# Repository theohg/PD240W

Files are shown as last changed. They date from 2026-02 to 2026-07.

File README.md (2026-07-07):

# PD240W









An adjustable power supply for motor drives using USB-C Power Delivery negotiation, supporting up to **240W at 48V 5A**. This device is designed to be compatible with USB-PD up to 3.2. Firmware runs on a Raspberry Pi Pico ([RP2040](https://www.raspberrypi.com/products/rp2040/)).

Follow the latest project logs and updates on <a href="https://hackaday.io/project/205084-pd240w" target="_blank" title="PD240W on Hackaday.io">
Hackaday.io Hackaday.io
</a>

<p align="center">
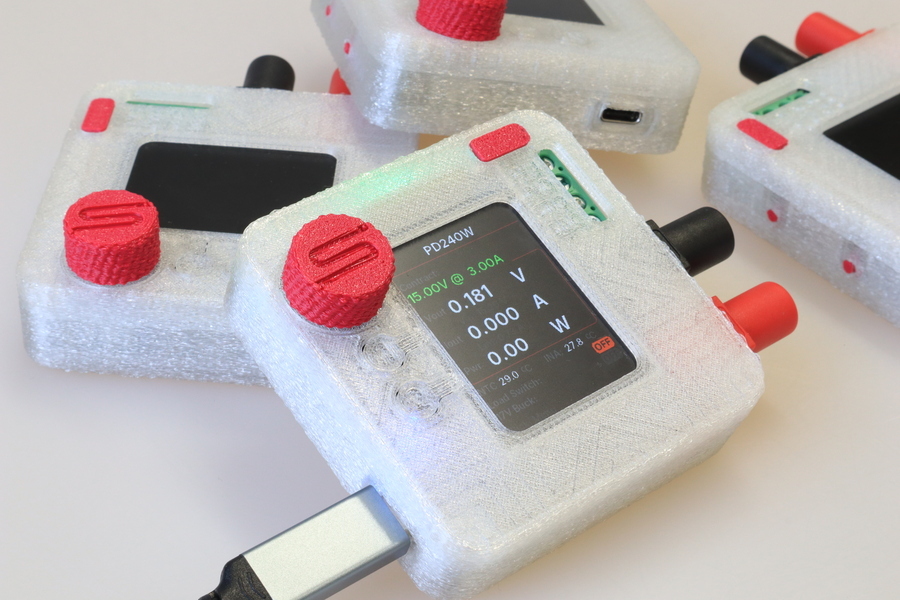
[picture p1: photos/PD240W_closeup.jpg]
PD240W closeup
  
</p>

> [!WARNING]
> **Disclaimer**: Firmware v2.0.0 includes guarded AVS/EPR negotiation, startup restore, and EPR-exit handling, but high-voltage charger interoperability still depends on the source and cable combination you test with. Validate 28V/36V/48V operation on your hardware.

## Table of Contents

- [Features](#features)
- [Hardware](#hardware)
- [Quick Start](#quick-start)
- [Controls](#controls)
- [Firmware Structure](#firmware-structure)
- [Want one?](#want-one)
- [Planned Features](#planned-features)
- [Acknowledgements](#acknowledgements)

## Features

- **USB-C Power Delivery**: Negotiates Fixed, PPS (3.3-21V programmable), and AVS (15-48V EPR) profiles
- **Current Limiting**: Adjustable 10mA-5A via INA228 power monitor with hardware overcurrent protection
- **LCD Interface**: 240x320 ST7789 display with anti-aliased fonts and Prusa-style encoder navigation
- **Safety**: Overcurrent ISR, overtemperature monitoring (NTC + INA228)
- **Settings Persistence**: User settings stored in RP2040 flash with CRC32 validation
- **Auto PPS/AVS Tuning**: Closed-loop voltage correction for PPS/AVS charger output accuracy
- **Charger Diagnostics**: On-device PD revision, charger identity, cable inference, and max-power reporting
- **Remote CLI**: USB serial command interface for measurements, PD selection, and settings updates
- **Energy Monitoring**: Tracks mAh delivered since boot via INA228 charge accumulator
- **17V Buck Output**: Optional mock STO/SBC voltage for motor drive safety circuits
- **Configurable**: Brightness, auto-dim, startup melody, auto-output on boot and more

## Hardware

<p align="center">
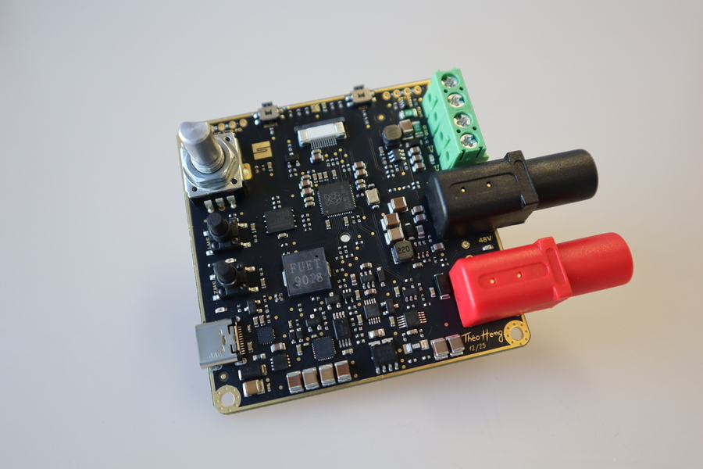
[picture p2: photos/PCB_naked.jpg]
PCB overview
  
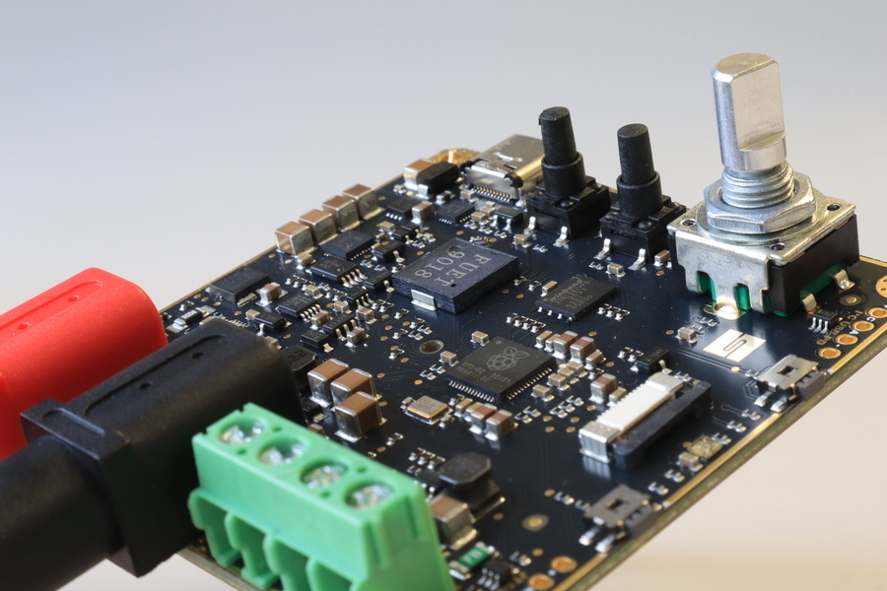
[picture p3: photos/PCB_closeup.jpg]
PCB closeup
  
</p>
<p align="center">
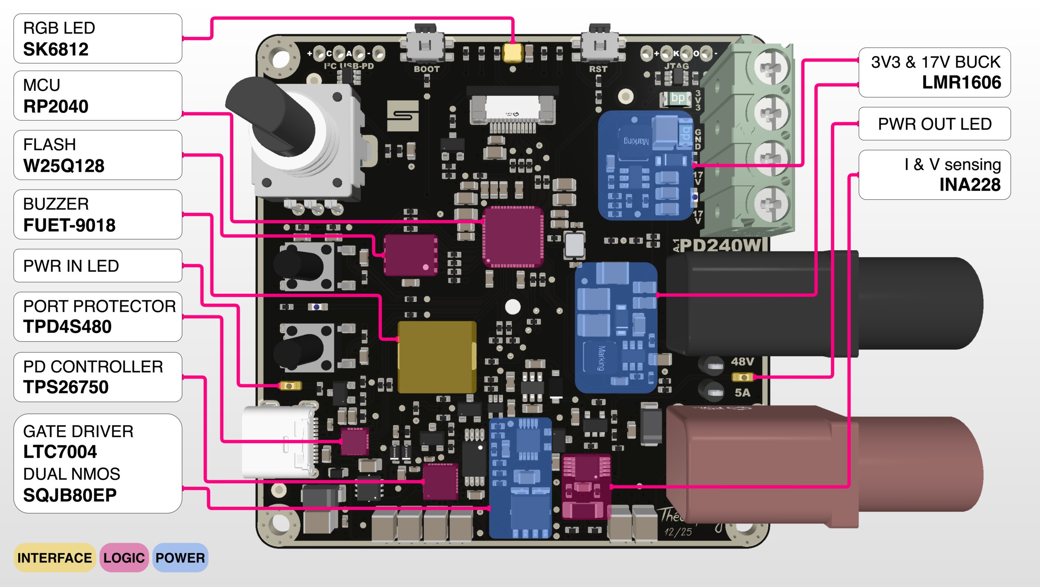
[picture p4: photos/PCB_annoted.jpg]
PCB annoted
  
</p>
<p align="center">
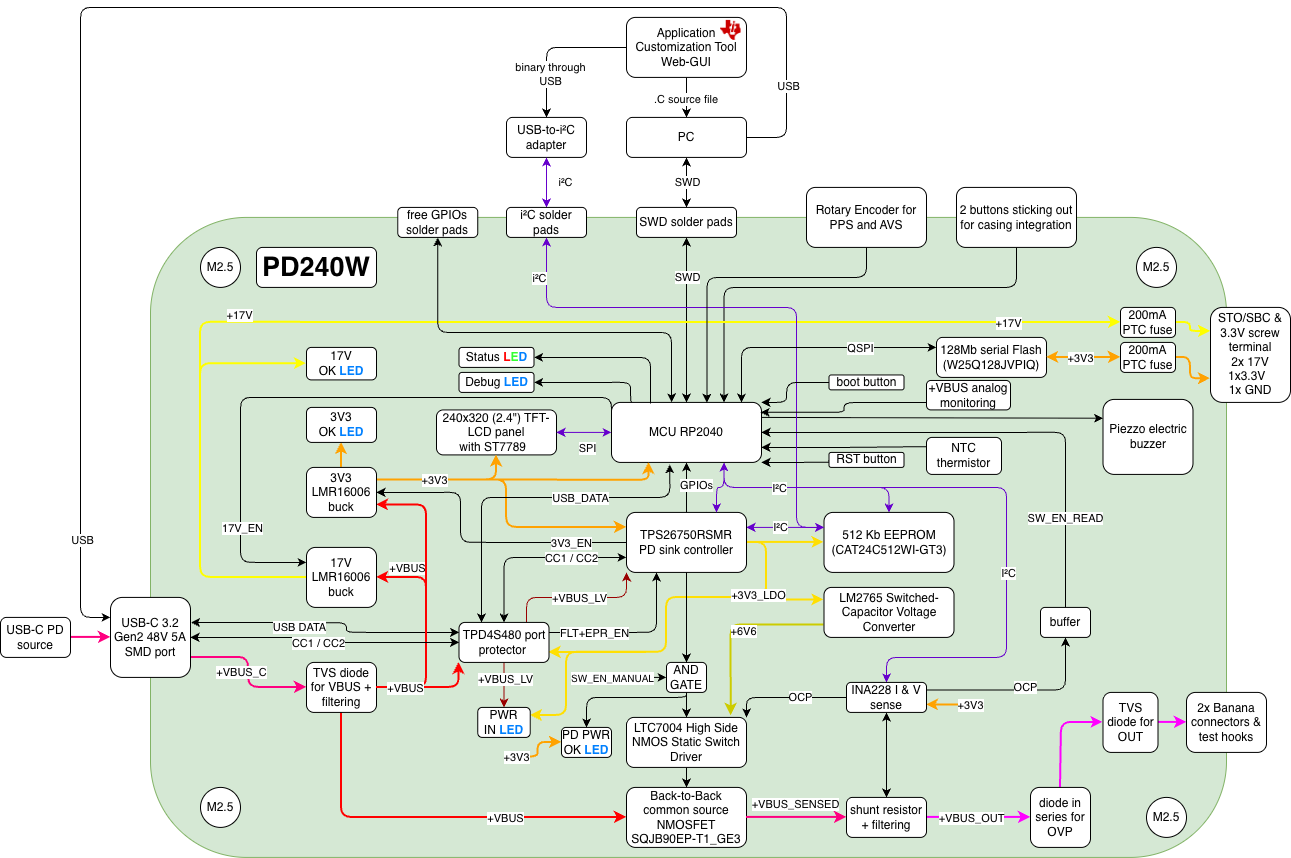
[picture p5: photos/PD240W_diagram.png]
PD240W diagram
  
</p>

| Type | Path | Contents |
|---|---|---|
| PCB (STEP) | `3D_models/PD240W_PCB.stp` | Full PCB 3D model |
| Enclosure (STL) | `3D_models/enclosure/` | Casing top/bottom, knob, button, LCD support, SWD cover |
| Gerbers | `PCB_files/Manufacturing/Fabrication/` | PCB manufacturing files |
| BOM | `PCB_files/Manufacturing/Assembly/` | Bill of materials |
| Pick & Place | `PCB_files/Manufacturing/Assembly/` | Pick and place file |

### Hardware Erata

USB data lines (D+/D-) are reversed in the current PCB revision, preventing native USB communication between the RP2040 and the USB host. This can be easily fixed by crossing the D+ and D- lines on the PCB by crossing the series 27Ω resistors as shown below:

<p align="center">
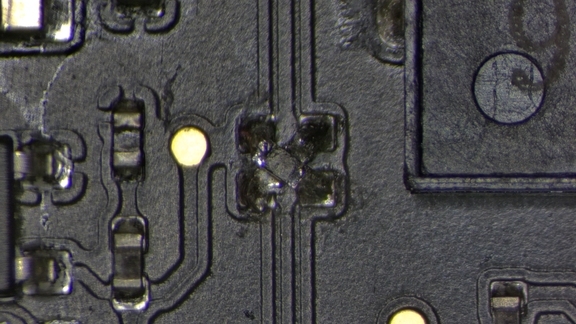
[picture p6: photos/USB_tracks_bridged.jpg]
PCB USB data lines bridged
  
</p>

## Quick Start

### Flash Pre-built Firmware

1. Download `PD240W.uf2` from the [latest release](https://github.com/theohg/PD240W/releases/latest)
2. Hold **BOOTSEL** button on the Pico while connecting USB
3. Drag `PD240W.uf2` to the mounted `RPI-RP2` drive

### Build from Source

Requires: [Pico SDK 2.3.0](https://github.com/raspberrypi/pico-sdk), ARM GCC toolchain, CMake, Ninja

```bash
git clone --recurse-submodules https://github.com/theohg/PD240W.git
cd PD240W

mkdir -p build && cd build
cmake -G Ninja ..
ninja
```

The output binary is `build/PD240W.uf2`.

The INA228 driver is tracked as a Git submodule in `external/ina228_multiplatform`. If you already cloned the repository without submodules, run:

```bash
git submodule update --init --recursive
```

PD240W does not automatically follow the newest INA228 library release. The version is pinned by the parent repository's recorded submodule commit for `external/ina228_multiplatform`, and that exact checked-out commit is what gets compiled into the firmware. Prebuilt `PD240W.uf2` releases already include that pinned INA version.

### Flash via SWD

```bash
openocd -f interface/cmsis-dap.cfg -f target/rp2040.cfg \
  -c "adapter speed 5000; program build/PD240W.elf verify reset exit"
```

> [!IMPORTANT]
> **EEPROM Initial Setup**: Before full PD negotiation can work, you must flash the **TPS26750 EEPROM** configuration. This is done via the **EEPROM Flash** workflow found in the **Settings** menu. 
> 
> **Note**: Before the EEPROM is flashed, the board will only power on when connected to a standard 5V non-PD charger (USB BC1.2 mode).

Once the firmware has been successfully flashed, connect the device to a compatible USB-PD power source and interact with the encoder and buttons to navigate the menus and adjust settings as explained below.

> [!NOTE]
> Finding a compact and affordable charger supporting **USB-PD 3.1** (up to 48V EPR) is currently quite rare. Here are a few known options:
>
> | Model | Max single-port PD Output | Voltage Profile | Approx. Price |
> |---|---|---|---|
> | **[UGREEN Nexode 140W](https://fr.ugreen.com/products/ugreen-nexode-140w-chargeur-usb-c-pd-3-1-3-ports)** | 140W | 28V @ 5A | ~60€ |
> | **[Framework Power Adapter - 180W](https://frame.work/fr/fr/products/16-power-adapter?v=FRANCR000F)** | 180W | 36V @ 5A | ~109€ |
> | **[HKY 240W GaN Charger](https://www.amazon.de/-/en/Charger-Framework-Thunderbolt-External-ADP-240KB/dp/B0FLXY1HYW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)** | 240W | 48V @ 5A | ~90€ |
> | **[Framework Power Adapter - 240W](https://frame.work/fr/fr/products/power-adapter-240w?v=FRAKMX000F)** | 240W | 48V @ 5A | ~120€ |
> | **[UGREEN NEXODE 500W](https://eu.ugreen.com/products/ugreen-nexode-500w-6-port-gan-desktop-fast-charger)** | 240W | 48V @ 5A | ~250€ |

## Controls

| Input | Action |
|---|---|
| Encoder Rotate | Navigate menus / Adjust values |
| Encoder Click | Confirm / Select |
| BTN1 (top) | Toggle load switch output |
| BTN2 (bottom) | Toggle 17V buck (requires VBUS > 18V) |

<p align="center">
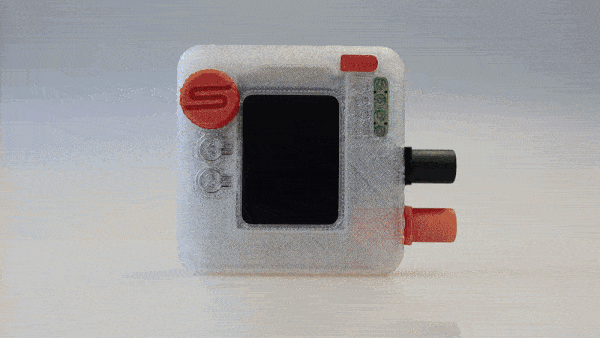
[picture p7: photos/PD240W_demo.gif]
PD240W usage demo
  
</p>

### Menu Structure

```mermaid
graph TD
  %% Nodes
      Boot([Boot]) -->|≤2s| Main[Main Screen]
      Main -->|Error| Fault[Fault Screen]
      Fault -->|Click| Main
      
      Main <-->|Click| Menu[Main Menu]

      Menu --> Voltage[Select Voltage]
      Menu --> Current[Current Limit]
      Menu --> Settings[Settings]
      Menu --> AboutFirmware[About PD240W]
      Menu --> AboutCharger[About This Charger]
      Menu --> Back[Back]

      Voltage <-->|Select PDO| AdjV[Adjust Voltage]
      Current <-->|Set Limit| AdjC[Adjust Current]
      
      Settings --> EEPROM[Flash EEPROM]
      Settings --> Configs[Params: Brightness / Sounds / Tuning...]
      AboutFirmware --> Main
      AboutCharger --> Main
      
      %% Styling
      classDef default fill:#f9f9f9,stroke:#333,stroke-width:1px;
      classDef alert fill:#ffcccc,stroke:#cc0000,stroke-width:2px;
      class Fault alert;
```

| Menu Item | Description |
|---|---|
| Select Voltage | Fixed / PPS / AVS PDO selection |
| Current Limit | 10mA - 5A output current limit adjustment with encoder acceleration |
| Settings | EEPROM flash workflow plus tuning, startup, brightness, and sound options |
| About PD240W | Device identity, firmware build info, flash usage, and project link |
| About This Charger | Live PD revision, CC orientation, QC inference, and cable diagnostics |
| Back | Return to the main live display |

## Firmware Structure

```
src/
├── main.cpp                        Entry point, non-blocking main event loop
├── hardware.h/cpp                  Hardware singleton aggregating all drivers
├── interrupts.h/cpp                Centralized GPIO interrupt router (RP2040 single-callback)
│
├── config/
│   ├── board_config.h              Pin definitions (Board:: namespace)
│   ├── app_config.h                Timeouts, thresholds, limits (AppConfig:: namespace)
│   └── version.h                   Firmware & hardware version, author...
│
├── drivers/                        Low-level hardware drivers (no business logic)
│   ├── display/
│   │   ├── st7789.h/cpp            SPI LCD driver with AA font rendering
│   │   ├── aa_font.h               Anti-aliased font data structure
│   │   └── font_inter_*.h          Generated Inter font bitmaps (14/20/28px)
│   ├── power/
│   │   └── tps26750/               USB-PD controller: PDO discovery, contract negotiation
│   ├── input/
│   │   ├── rotary_enc.h/cpp        Quadrature encoder with velocity tracking
│   │   ├── button.h/cpp            Debounced button with click/long-press
│   │   └── adc_inputs.h/cpp        VBUS voltage + NTC temperature (ADC channels)
│   ├── gpio/                       SimpleIO: digital output with non-blocking blink
│   ├── buzzer/                     PWM buzzer with melody playback
│   └── rgb_led/                    SK6812 via PIO state machine
│
├── logic/                          Application logic
│   ├── state_machine.h/cpp         BOOT -> MAIN <-> MENU <-> ADJUST, FAULT handling
│   ├── safety.h/cpp                Temperature/voltage/current monitoring, fault triggers
│   ├── pd_manager.h/cpp            PD contract caching, PPS keep-alive, auto-tuning
│   ├── settings.h/cpp              Flash persistence with CRC32, debounced saves
│   └── tps_eeprom_workflow.h/cpp   TPS26750 EEPROM compare/flash state machine
│
├── ui/
│   ├── display_manager.h/cpp       All screen rendering (boot, main, menu, adjust, fault)
│   ├── font_config.h               Central font size mapping (FONT_LARGE/MEDIUM/SMALL)
│   └── assets/synapticon_logo.h    Boot screen logo bitmap
│
├── utils/
│   ├── logging.h                   LOG_INFO/WARN/ERROR/DEBUG/CRITICAL macros
│   ├── pd_voltage.h                Shared programmable-voltage alignment helper
│   ├── tps_eeprom_loader.h/cpp     Low-level TPS26750 EEPROM read/write
│   └── tps26750_patch.c            TPS26750 binary configuration blob
```

## Want one?

<p align="center">
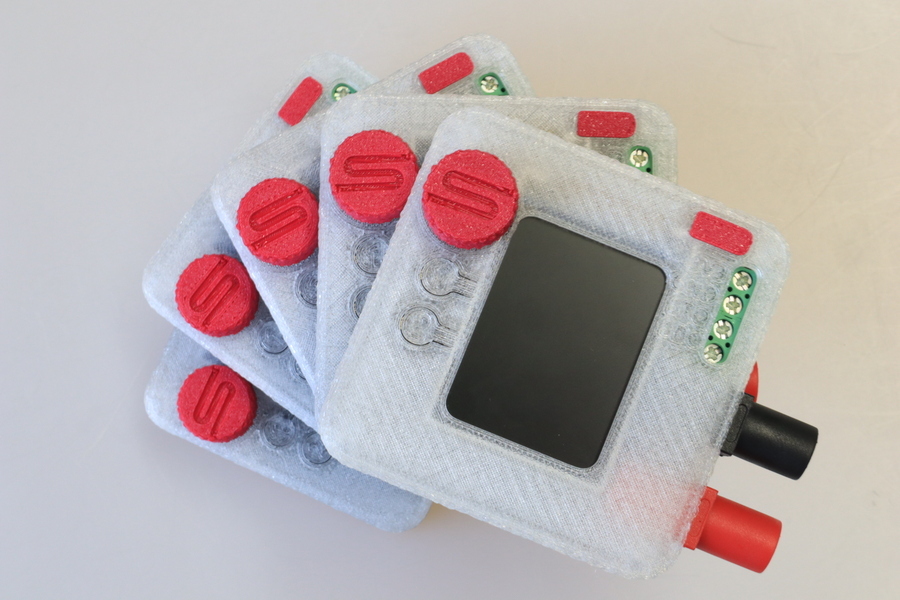
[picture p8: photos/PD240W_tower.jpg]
PD240W units
  
</p>

Feel free to order assembled PCBs, flash the firmware, and test it for yourself! Manufacturing 5 assembled PCBs will cost approximately **$415**. 

The project is open for contributions. Don't hesitate to improve the code, report bugs, or suggest new features via Pull Requests and Issues!

## License and Copyright

This repository contains different types of source files, which are licensed as follows:

### 1. Hardware files (CC BY-NC 4.0)
All hardware design files in the PCB_files directory (Schematics, PCB layout, Gerbers, BOM) and 3D printable enclosure files are licensed under the **Creative Commons Attribution-NonCommercial 4.0 International License**. 

You are free to download, modify, and build this board for personal, educational, and hobbyist use. However, you may **not** use these designs for commercial purposes (such as manufacturing and selling the boards) without prior written permission.

Please see the [LICENSE.txt](./LICENSE.txt) file for full terms.

### 2. Firmware & Software (MIT License)
The firmware and software source code in this repository is licensed under the **MIT License**. 

You are free to use, modify, and distribute the software component of this project. 

Please see the [LICENSE-FIRMWARE.txt](./LICENSE-FIRMWARE.txt) file for full terms.

## Planned Features for V2.1.0+

- **PPS battery charging in Constant Current (CC) mode**: PPS allows a fixed current mode that can be used for battery charging. This is to be tested by charging lithium-ion battery packs.
- **Improved CLI interface**: Needs more testing and polish.
- **Extended PPS and AVS Range**: Support for PPS voltages as low as 3.5V, AND SPR AVS profiles down to 9V.

## Acknowledgements

This project was made possible by [Synapticon GmbH](https://www.synapticon.com), who funded and supported its development. Thank you for providing the resources, hardware, and opportunity to bring PD240W to life.

Inspiration for this project was taken from the great work on portable USB-C PD power supplies by CentyLab on the [PocketPD](https://hackaday.io/project/194295-pocketpd-usb-c-portable-bench-power-supply) project and Alex Xia with his [ProtoV MINI](https://hackaday.io/project/204461-protov-mini-tiny-usb-c-breadboard-power-supply).

All work done on this project, from Hardware design to Firmware development, was done by me, as the sole contributor. I am grateful for the support and feedback from the community, and I hope this project can be a useful resource for anyone interested in USB-C PD power supplies!

***

<p align="center">
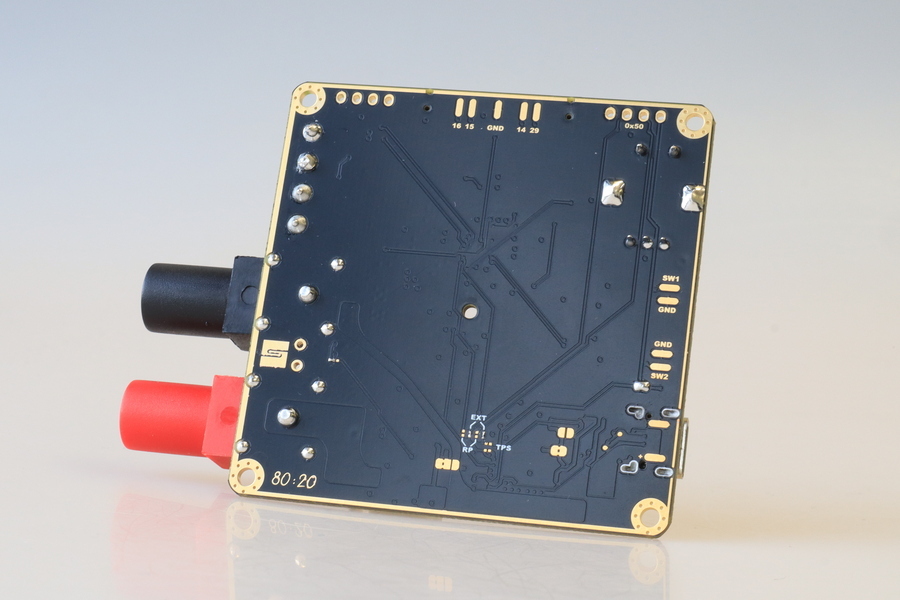
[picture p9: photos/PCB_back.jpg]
PCB back
  
</p>

Made with ❤️ by Théo Heng

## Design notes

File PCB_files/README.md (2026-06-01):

<p align="center" width="100%">
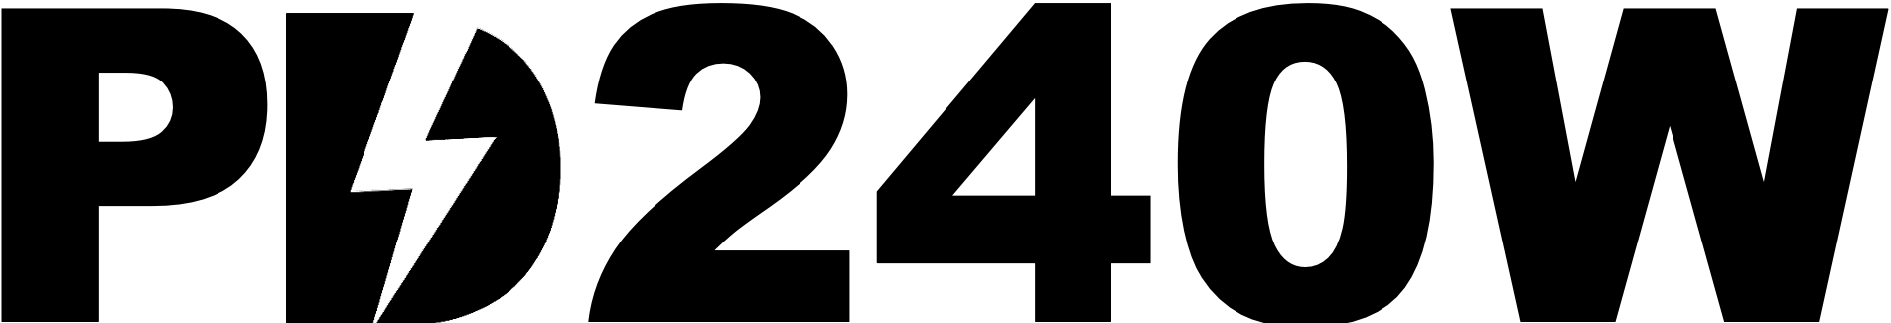
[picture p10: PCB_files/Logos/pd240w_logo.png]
  
</p>

<h1 align="center">PD240W</h1>

<p align="center" width="100%">
    
</p>

***

<p align="center">
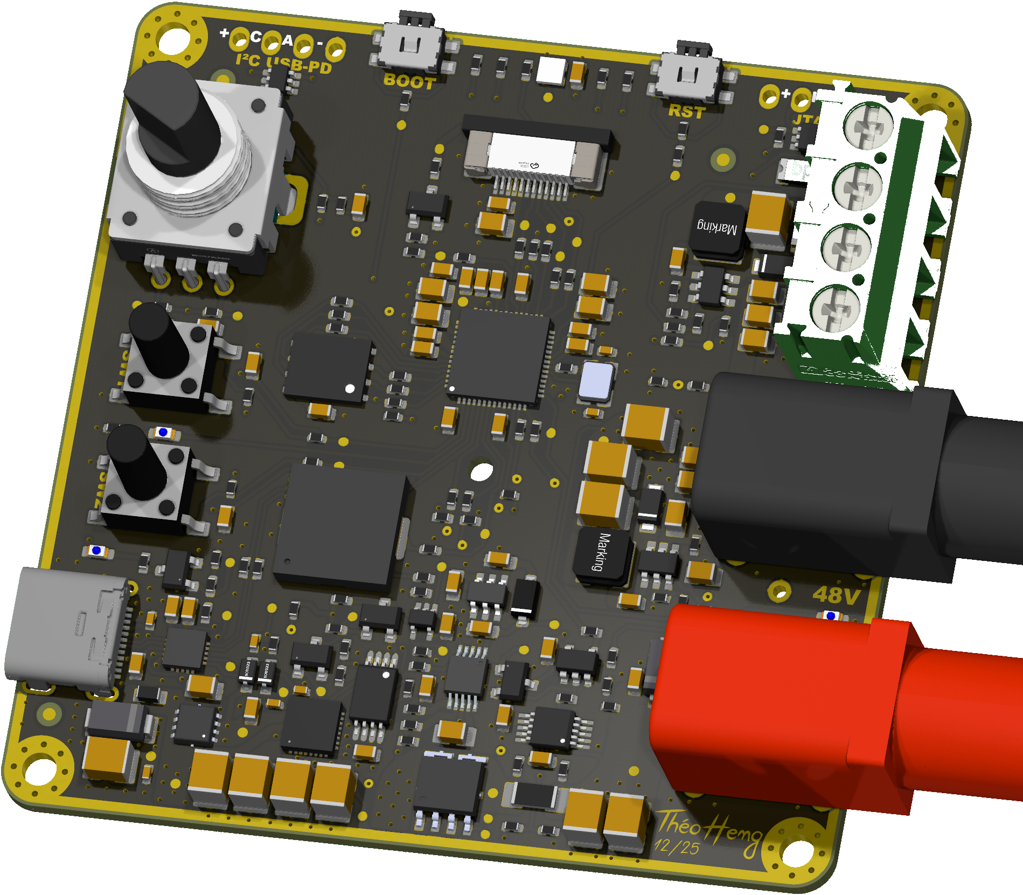
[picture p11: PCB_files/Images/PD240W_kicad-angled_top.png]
3D Top Angled
  
&nbsp; &nbsp; &nbsp; &nbsp;
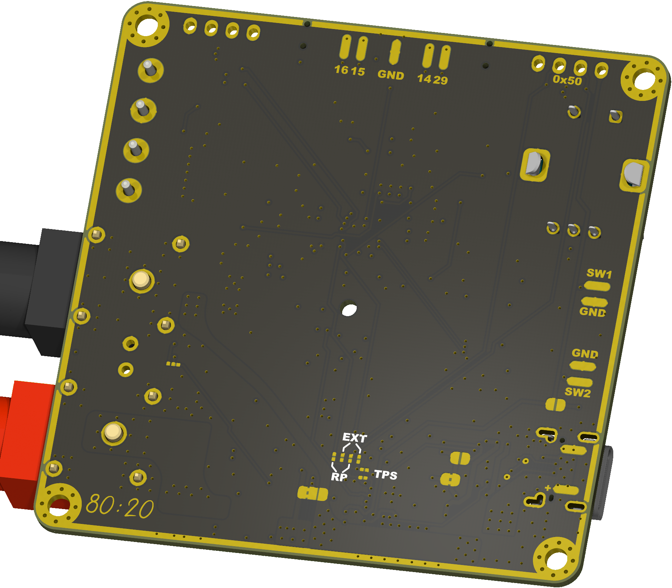
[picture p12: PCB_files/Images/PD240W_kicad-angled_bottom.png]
3D Bottom Angled
  
</p>

***

## SPECIFICATIONS

| Parameter | Value | 
| --- | --- |
| Dimensions | 66.0 × 66.0 mm |
| Input Voltage | 5 - 53 V |
| Output Voltage | 3.3 - 48 V |
| Max. Output Current Voltage | 5 A |
| Max Power Output | 240 W |

***

## DIRECTORY STRUCTURE
```
  ├─ Images             # Pictures, renders, and annotated PCB images
  ├─ lib                # KiCad footprint and symbol libraries
  │  ├─ lib_fp          # Footprint libraries
  │  └─ lib_sym         # Symbol libraries
  ├─ Logos              # Project logos used in the PCB design package
  ├─ Manufacturing      # Assembly and fabrication deliverables
  │  ├─ Assembly        # BoM, placement, and assembly notes
  │  └─ Fabrication     # Fabrication exports and release bundles
  ├─ Schematic          # Exported schematic documentation
  └─ Templates          # KiCad title block templates
```

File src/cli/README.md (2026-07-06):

# PD240W Serial CLI Reference

## Connection

The PD240W exposes a serial CLI over USB CDC at **115200 baud, 8N1**. Lines are terminated with `\n`.

> [!NOTE]
> On the current PCB revision, native USB CDC requires the USB D+/D- rework described in the repository [README](../../README.md).

**Finding the serial port:**

| OS | Command |
|----|---|
| macOS | `ls /dev/tty.usbmodem*` |
| Linux | `ls /dev/ttyACM*` |
| Windows | Device Manager → Ports (COM & LPT) |

Connect with any serial terminal:
```bash
# macOS / Linux
screen /dev/tty.usbmodem1234 115200
# or
minicom -D /dev/ttyACM0 -b 115200
```

## Protocol Rules

- **Queries** end with `?` and return the value on a single line: `20000\n`
- **Set commands** include a value after a space and return `OK\n` on success
- **Action commands** (no argument) return `OK\n`
- **Errors** return `ERR <CODE>\n` immediately

### Error Codes

| Code | Description |
|---|---|
| `UNKNOWN_CMD` | Command not found in dispatch table |
| `INVALID_PARAM` | Argument is missing, malformed, or wrong type (e.g. non-numeric, not ON/OFF) |
| `INVALID_INDEX` | PDO index out of range |
| `OUT_OF_RANGE` | Numeric value outside allowed bounds |
| `NOT_AVAILABLE` | Operation not possible (e.g. PPS command with no PPS contract, buck with low VBUS) |
| `FAULT_ACTIVE` | Output command rejected because a safety fault is active |
| `NO_POWER_MONITOR` | Load switch refused: INA228 power monitor did not initialize (no current sensing / overcurrent protection) |

### Log Output

Firmware log lines use prefixes: `[INFO]`, `[WARN]`, `[ERROR]`, `[DEBUG]`. These are separate from CLI responses and can be suppressed:

- `LOG:OFF` — Suppress all log output (recommended for scripting)
- `LOG:ON` — Re-enable log output

### Remote Control Mode

Receiving any serial command puts the device in **REMOTE** mode:
- Front panel is locked (encoder/buttons disabled)
- LCD shows a red **RMT** badge
- Long-press encoder returns to local control
- `SYST:LOC` command also exits remote mode

## Command Reference

### Identity & Status

| Command | Arguments | Response | Description |
|---|---|---|---|
| `*IDN?` | — | `PD240W,HWA.1,FWv2.0.0` | Device identification |
| `SYST:STAT?` | — | `MAIN` / `FAULT:OVERTEMP` / ... | System state |
| `SYST:UPTIME?` | — | `12345` | Uptime in seconds |
| `SYST:REBOOT` | — | `OK` | Software reboot (watchdog reset) |
| `SYST:BOOTSEL` | — | `OK` | Reboot into BOOTSEL (UF2 flash mode) |
| `SYST:LOC` | — | `OK` | Exit remote mode, return to local control |

### Output Control

| Command | Arguments | Response | Description |
|---|---|---|---|
| `OUTP:SW?` | — | `ON` / `OFF` | Query load switch state |
| `OUTP:SW` | `ON` / `OFF` | `OK` | Enable/disable load switch |
| `OUTP:BUCK?` | — | `ON` / `OFF` | Query 17V buck state |
| `OUTP:BUCK` | `ON` / `OFF` | `OK` | Enable/disable 17V buck (requires VBUS > 18V) |

### Measurements (read-only)

| Command | Arguments | Response | Description |
|---|---|---|---|
| `MEAS:VOLT?` | — | `20000` | Output voltage in mV (from INA228) |
| `MEAS:CURR?` | — | `1500` | Output current in mA |
| `MEAS:POW?` | — | `30000` | Output power in mW |
| `MEAS:TEMP?` | — | `452` | Board temperature in °C × 10 (45.2°C) |
| `MEAS:ITEMP?` | — | `380` | INA228 die temperature in °C × 10 |
| `MEAS:ENERGY?` | — | `1234` | Accumulated energy since boot in mWh |
| `MEAS:CHARGE?` | — | `1234` | Accumulated charge since boot in mAh |
| `MEAS:VBUS?` | — | `20100` | Pre-switch VBUS voltage in mV (from ADC) |
| `MEAS:ALL?` | — | `20000,1500,30000,452,380,1234` | volt_mv, curr_ma, pow_mw, temp_c×10, itemp_c×10, energy_mwh |

### PD Contract Management

| Command | Arguments | Response | Description |
|---|---|---|---|
| `PD:LIST?` | — | `0:5000/3000,1:9000/3000,...` | List available PDOs (index:mV/mA or PPS/AVS format) |
| `PD:ACTIVE?` | — | `20000,3000,FIXED` | Active contract: voltage, current, type |
| `PD:REV?` | — | `PD3.2` | PD revision string (`PD2.0` / `PD3.0` / `PD3.1` / `PD3.2`) |
| `PD:SEL` | `<index>` | `OK` | Select PDO by index (from PD:LIST?) |
| `PD:PPS` | `<voltage_mv>` | `OK` | Set PPS voltage in mV (must be in active PPS range) |
| `PD:AVS` | `<voltage_mv>` | `OK` | Set AVS voltage in mV (must be in active AVS range) |

### Current Limit

| Command | Arguments | Response | Description |
|---|---|---|---|
| `CURR:LIM?` | — | `1500` | Query current limit in mA |
| `CURR:LIM` | `<10-5000>` | `OK` | Set current limit in mA (10 mA steps) |

### Settings

| Command | Arguments | Response | Description |
|---|---|---|---|
| `SETT:BRIGHT?` | — | `80` | Query LCD brightness (5–100) |
| `SETT:BRIGHT` | `<5-100>` | `OK` | Set LCD brightness |
| `SETT:SOUND?` | — | `ON` / `OFF` | Query sounds enabled |
| `SETT:SOUND` | `ON` / `OFF` | `OK` | Toggle sounds |
| `SETT:AUTOPPS?` | — | `ON` / `OFF` | Query auto PPS tuning |
| `SETT:AUTOPPS` | `ON` / `OFF` | `OK` | Toggle auto PPS tuning |
| `SETT:AUTOAVS?` | — | `ON` / `OFF` | Query auto AVS tuning |
| `SETT:AUTOAVS` | `ON` / `OFF` | `OK` | Toggle auto AVS tuning |
| `SETT:AUTOOUT?` | — | `ON` / `OFF` | Query auto output |
| `SETT:AUTOOUT` | `ON` / `OFF` | `OK` | Toggle auto output |
| `SETT:DIM?` | — | `5` | Query dim timeout in minutes |
| `SETT:DIM` | `<0-10>` | `OK` | Set dim timeout in minutes (`0` = OFF) |
| `SETT:SAVE` | — | `OK` | Force save settings to flash |
| `SETT:RESET` | — | `OK` | Reset all settings to defaults |

### Log Control

| Command | Arguments | Response | Description |
|---|---|---|---|
| `LOG:ON` | — | `OK` | Enable firmware log output |
| `LOG:OFF` | — | `OK` | Suppress firmware log output |

### System

| Command | Arguments | Response | Description |
|---|---|---|---|
| `SYST:REBOOT` | — | `OK` | Software reboot via watchdog |
| `SYST:BOOTSEL` | — | `OK` | Reboot into UF2 flash mode |
| `SYST:LOC` | — | `OK` | Return to local (front panel) control |

## Raw Session Example

```
> *IDN?
PD240W,HWA.1,FWv2.0.0
> LOG:OFF
OK
> SYST:STAT?
MAIN
> PD:LIST?
0:5000/3000,1:9000/3000,2:15000/3000,3:20000/3000,4:PPS/3300-21000/5000
> PD:ACTIVE?
20000,3000,FIXED
> PD:REV?
PD3.0
> PD:SEL 4
OK
> PD:PPS 9500
OK
> MEAS:ALL?
9480,0,0,312,298,0
> CURR:LIM 2000
OK
> CURR:LIM?
2000
> OUTP:SW ON
OK
> MEAS:VOLT?
9500
> MEAS:CURR?
850
> MEAS:POW?
8075
> SETT:BRIGHT 70
OK
> OUTP:SW OFF
OK
```

## Python Quick Start

```python
from pd240w import PD240W

with PD240W("/dev/ttyACM0") as psu:
    print(psu.identity())           # PD240W,HWA.1,FWv2.0.0
    print(psu.list_pdos())          # ['0:5000/3000', '1:9000/3000', ...]
    psu.select_pdo(3)               # Select 20V
    psu.output(True)                # Enable output
    m = psu.measurements()
    print(f"{m['voltage_mv']/1000:.2f}V  {m['current_ma']/1000:.3f}A")
    psu.output(False)               # Disable output
```

See [tools/pd240w.py](../../tools/pd240w.py) for the full library and CLI tool.

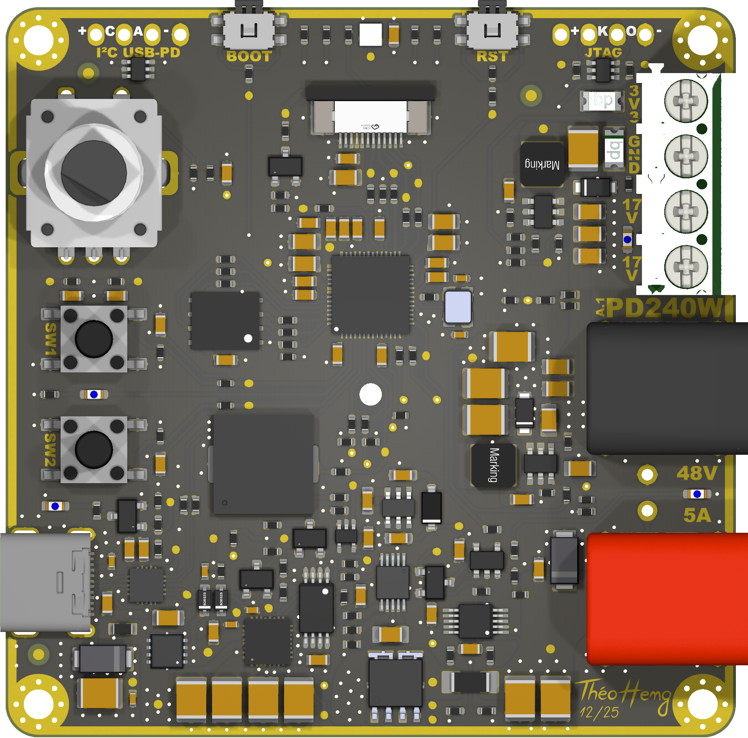
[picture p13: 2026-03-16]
PCB_files/Images/PD240W_kicad-top.png

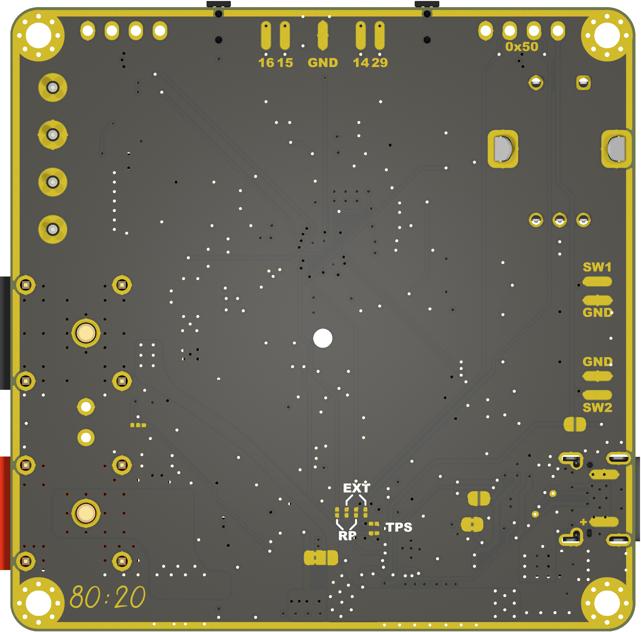
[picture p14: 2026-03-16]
PCB_files/Images/PD240W_kicad-bottom.png

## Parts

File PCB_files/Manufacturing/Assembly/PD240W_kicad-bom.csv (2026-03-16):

Row | Quantity Per PCB | References | Value | Datasheet | Footprint | Description | Manufacturer | Manufacturer Part Number | LCSC
1 | 2 | C45 C46 | 15p COG 50V | https://jlcpcb.com/api/file/downloadByFileSystemAccessId/8579707286171729920 | capc_1005_06_n | Capacitor, 15pF, 5%, C0G, 50V, 1005, 0402 | FH (Guangdong Fenghua Advanced Tech) | 0402CG150J500NT | C1548
2 | 2 | C19 C20 | 220p X7R 50V | https://jlcpcb.com/api/file/downloadByFileSystemAccessId/8588946226129604609 | capc_1005_06_l | Capacitor, 220pF, 10%, X7R, 50V, 1005, 0402 | Samsung Electro-Mechanics | CL05B221KB5NNNC | C296710
3 | 3 | C1 C2 C5 | 10n X7R 100V | https://jlcpcb.com/api/file/downloadByFileSystemAccessId/8588949628376502272 | capc_1005_06_n | Capacitor, 10nF, 10%, X7R, 100V, 1005, 0402 | Yageo | CC0402KRX7R0BB103 | C527014
4 | 32 | C4 C6 C8 C16 C17 C21 C22 C23 C24 C25 C26 C27 C30 C34 C35 C37 C38 C39 C40 C41 C42 C43 C44 C47 C48 C49 C50 C52 C53 C54 C55 C63 | 100n X7R 100V | https://jlcpcb.com/api/file/downloadByFileSystemAccessId/8586178586332446721 | capc_1608_09_l | Capacitor, 100nF, 10%, X7R, 100V, 1608, 0603 | Samsung Electro-Mechanics | CL10B104KC8NNNC | C15725
5 | 13 | C7 C31 C32 C33 C36 C51 C56 C57 C58 C62 C64 C65 C66 | 1u X7R 100V | https://jlcpcb.com/api/file/downloadByFileSystemAccessId/8590904853830971392 | capc_2012_14_n | Capacitor, 1uF, 10%, X7R, 100V, 2012, 0805 | Yageo | CC0805KKX7R0BB105 | C5370002
6 | 1 | C18 | 2.2u X7R 100V | https://jlcpcb.com/api/file/downloadByFileSystemAccessId/8590916664114966528 | capc_2012_14_m | Capacitor, 2.2nF, 10%, X7R, 100V, 2012, 0805 | Chinocera | HHV0805R7225K101NSLJ | C22367838
7 | 3 | C13 C14 C15 | 3.3u X5R 25V | https://jlcpcb.com/api/file/downloadByFileSystemAccessId/8590902687791857664 | capc_1608_09_n | Capacitor, 3.3uF, 20%, X5R, 25V, 1608, 0603 | CCTC | TCC0603X5R335M250CT | C5360803
8 | 1 | C3 | 4.7u | https://jlcpcb.com/api/file/downloadByFileSystemAccessId/8588955064752869376 | capc_3225_22_n | Capacitor, 4.7 uF, 10%, X7S, 100V, 3225, 1210 | Murata Electronics | GCM32DC72A475KE02 | C913445
9 | 10 | C9 C10 C11 C12 C28 C29 C59 C60 C61 C67 | 10u X7R 63V | https://jlcpcb.com/api/file/downloadByFileSystemAccessId/8589835732941770752 | capc_3225_27_n | Capacitor, 10uF, 10%, X7R, 63V, 3225, 1210 | Murata Electronics | GRM32ER71J106KA12L | C437568
10 | 4 | D4 D6 D9 D14 | APTD1608LQBC/D | https://jlcpcb.com/api/file/downloadByFileSystemAccessId/8589837755585884160 | kingbright_0603_blue | Standard LEDs - SMD Chip LED, Package= 0603, Color = Blue | Kingbright | APTD1608LQBC/D | C5344742
11 | 1 | D5 | B0520LW-7-F | https://jlcpcb.com/api/file/downloadByFileSystemAccessId/8560080535511982080 | sod-123_270x155135_n | Schottky Diodes & Rectifiers 20V 410mW, SMD, SOD123 | Diodes Incorporated | B0520LW-7-F | C155367
12 | 2 | D2 D3 | BZT52C18SQ | https://jlcpcb.com/api/file/downloadByFileSystemAccessId/8590197770775654400 | sod-323_230p_170x125x100_n | Zener Diode 18V 200mW 5% Surface Mount SOD-323 | JSMSEMI | BZT52C18SQ | C2857090
13 | 2 | D7 D10 | D3V3F4U6S-7 | https://jlcpcb.com/api/file/downloadByFileSystemAccessId/8589951277003141120 | sot363_sc88_65p_200x125x110_n | 4-Ch 3.3V Low Cap TVS Array 0.85pF 3.5A 350mW | Diodes Incorporated | D3V3F4U6S-7 | C1869321
14 | 2 | D12 D13 | MBR1H100SFT3G | https://jlcpcb.com/api/file/downloadByFileSystemAccessId/8588886768716288000 | sod-123fl_305p_260x160x90_n | Rectifier Diode, Schottky, 1 Phase, 1A, 100V | onsemi | MBR1H100SFT3G | C235757
15 | 1 | D11 | SK6812-EC20 | https://jlcpcb.com/api/file/downloadByFileSystemAccessId/8589835384537849856 | SK6812-EC20 | RGB LED with integrated controller | OPSCO Optoelectronics | SK6812-EC20 | C2909058
16 | 2 | D1 D8 | SMAJ48A | https://jlcpcb.com/api/file/downloadByFileSystemAccessId/8564879166429958145 | do-214ac_440p_430x250x230_n_p | Diode, TVS, Single, Unidirectional, Vrwm max 48V, Vbr min 53.3V, Vcl max 77.4V, Irm 1uA, peak puls power 400W, C 80pF @50V, IEC61000-4-2 ESD, IEC61000-4-4 EFT, IEC61000-4-5 Surge, DO-214AC, 2.9x4.6x2.65mm, -55°C ~ 150°C | hongjiacheng | SMAJ48A | C41376401
17 | 1 | DSP1 | HS20HS072RX | https://jlcpcb.com/api/file/downloadByFileSystemAccessId/8590902731202768896 | generic_display_518x362x2_10mm_standoff | 240x320 (2.4") TFT-LCD panel Integrated driver (ST7789T3) and FPC | HS | HS20HS072RX | C5329582
18 | 2 | F1 F2 | FSMD020-1206-R | https://jlcpcb.com/api/file/downloadByFileSystemAccessId/8588906240126279680 | ptc_1206_08_n | PTC, 30V, I_ hold 200mA, I_Trip 400mA, Imax 100A, 1206 | Fuzetec Tech | FSMD020-1206-R | C220145
19 | 1 | FB1 | BLM18SN220TH1D | https://jlcpcb.com/api/file/downloadByFileSystemAccessId/8589838767348477952 | fer_1608_09_n | Ferrite Bead, 120Ohm@100MHz, 25%, DCR 25mOhm, 1608, 0603 | Murata Electronics | BLM18SN220TH1D | C710392
20 | 2 | J5 J6 | 1935776 | https://jlcpcb.com/api/file/downloadByFileSystemAccessId/8590286408062967808 | phoenix_1935776 | 2 Position Wire to Board Terminal Block Horizontal with Board 0.197" (5.00mm) Through Hole | Phoenix Contact | 1935776 | C3817389
21 | 1 | J3 | 24.245.1 | https://jlcpcb.com/api/file/downloadByFileSystemAccessId/8590904437944623104 | fcr7350r | 4MM PANEL SKT S16N-PC RED | Changzhou Amass Elec | 24.245.1 | C7437326
22 | 1 | J4 | 24.245.2 | https://jlcpcb.com/api/file/downloadByFileSystemAccessId/8590904438813249536 | fcr7350b | 4MM PANEL SKT S16N-PC BLACK | Changzhou Amass Elec | 24.245.2 | C7437327
23 | 1 | J8 | AFC07-S12FCA-00 | https://jlcpcb.com/api/file/downloadByFileSystemAccessId/8588894283646029825 | AFC07-S12FCA-00 | 0.3mm 0.5mm 12P 2mm Bottom Contact Slide Lock Surface Mount, Right Angle SMD,P=0.5mm,Surface Mount，Right Angle FFC, FPC (Flat Flexible) Connector Assemblies ROHS | JUSHUO | AFC07-S12FCA-00 | C262559
24 | 1 | J1 | DX07S024JJ2R1300 | https://4donline.ihs.com/images/VipMasterIC/IC/JAEI/JAEI-S-A0001615074/JAEI-S-A0001615074-1.pdf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 | DX07S024JJ2R1300 | USB Connector USB 3.2 Gen 2 TypeC Receptacle Horizontal SMT Body, Height 3.14 mm, 24 Contacts | JAE Electronics | DX07S024JJ2R1300 | C2977282
25 | 1 | L1 | 22uH 1A 0.29Ohm | https://jlcpcb.com/api/file/downloadByFileSystemAccessId/8588893270500261888 | SWPA4030S220MT | FIXED IND 22UH 1A 292 MOHM SMD | Sunlord | SWPA4030S220MT | C83472
26 | 1 | L2 | 68uH 0.55A 0.91Ohm | https://jlcpcb.com/api/file/downloadByFileSystemAccessId/8588929589444030464 | SWPA4030S220MT | FIXED IND 68UH 0.55A 910 MOHM SMD | Sunlord | ASWPA4035S680MT | C340217
27 | 1 | PZ1 | FUET-9018 | https://jlcpcb.com/api/file/downloadByFileSystemAccessId/8588904050284220416 | buzzer_9x9x2.1mm | -30℃~+70℃ 1V~25V 2.1mm 3V 4kHz 5mA 65dB 9mm 9mm Passive (Externally Driven) Piezoelectric SMD, 9x9mm Buzzers ROHS | FUET | FUET-9018 | C391035
28 | 1 | Q1 | AGM612AP | https://jlcpcb.com/api/file/downloadByFileSystemAccessId/8589950125352120320 | vsonp8_65p_330x330x80_mfg | MOSFET, n-channel, 60V, r_ds_on 11mOhm, 10A @Ta=25°C, 50A @Tc=25°C, Vgs_th 1.6V, SMD PDFN-8 pin, (3.3x3.3x0.8mm), -55°C ~ 155°C (Tj) | AGM-Semi | AGM612AP | C5349119
29 | 5 | Q2 Q4 Q5 Q6 Q7 | AO3404A | https://jlcpcb.com/api/file/downloadByFileSystemAccessId/8586177430906146816 | sot-23-3L_103p_300x130x110_n | MOSFET 30V 1.4W, SOT-23-3L | Alpha & Omega Semicon | AO3404A | C30010
30 | 1 | Q3 | SQJB90EP-T1_GE3 | https://jlcpcb.com/api/file/downloadByFileSystemAccessId/8588924689125150720 | PowerPAKSO-8_127p_513x615x120_n | Dual NMOS transistor, 6 pin package | Vishay Intertech | SQJB90EP-T1_GE3 | C727731
31 | 1 | R22 | 8m 1% | https://jlcpcb.com/api/file/downloadByFileSystemAccessId/8590227465076842496 | WSLP1206_n_current_sense_6m_to_50m | Resistor, 8m, 1%, 50ppm, 1W, 3216, 1206 | Milliohm | HoLLR1206-1W-8mR-1% | C2988654
32 | 1 | R73 | 3.9R 1% | https://jlcpcb.com/api/file/downloadByFileSystemAccessId/8590208739052445696 | resc_1005_04_m | Resistor, 3.9R, 1%, 200ppm, 1/16W, 1005, 0402 | FOJAN | FRC0402F3R90TS | C2933095
33 | 29 | R7 R23 R24 R26 R37 R38 R39 R40 R42 R43 R44 R45 R46 R47 R48 R49 R51 R52 R56 R57 R58 R59 R60 R61 R62 R64 R65 R66 R74 | 27R 1% | https://jlcpcb.com/api/file/downloadByFileSystemAccessId/8588899757724995584 | resc_1005_04_m | Resistor, 27R, 1%, 100ppm, 1/16W, 1005, 0402 | Yageo | RC0402FR-0727RL | C138021
34 | 3 | R20 R50 R68 | 330R 1% | https://jlcpcb.com/api/file/downloadByFileSystemAccessId/8579706017514917888 | resc_1005_04_m | Resistor, 330R, 1%, 100ppm, 1/16W, 1005, 0402 | UNI-ROYAL(Uniroyal Elec) | 0402WGF3300TCE | C25104
35 | 7 | R5 R35 R53 R54 R55 R63 R67 | 1k 1% | https://jlcpcb.com/api/file/downloadByFileSystemAccessId/8579705924167974912 | resc_1005_04_m | Resistor, 1k, 1%, 100ppm, 1/16W, 1005, 0402 | UNI-ROYAL(Uniroyal Elec) | 0402WGF1001TCE | C11702
36 | 10 | R8 R9 R11 R12 R18 R25 R30 R84 R89 R90 | 4.7k 1% | https://jlcpcb.com/api/file/downloadByFileSystemAccessId/8579705919464263680 | resc_1005_04_m | Resistor, 4.7k, 1%, 100ppm, 1/16W, 1005, 0402 | UNI-ROYAL(Uniroyal Elec) | 0402WGF1003TCE | C25741
37 | 14 | R6 R10 R13 R19 R31 R36 R41 R69 R70 R71 R76 R77 R83 R86 | 10k 1% | https://jlcpcb.com/api/file/downloadByFileSystemAccessId/8556212101498380288 | resc_1005_04_n | Resistor, 10k, 1%, ±25ppm, 1/16W, 1005, 0402 | UNI-ROYAL(Uniroyal Elec) | 0402WGF1002TCE | C25744
38 | 9 | R2 R4 R33 R34 R72 R78 R79 R80 R82 | 33k 1% | https://jlcpcb.com/api/file/downloadByFileSystemAccessId/8671329089120387072 | resc_1005_04_n | Resistor, 33k, 1%, 100ppm, 1/16W, 1005, 0402 | Yageo | RC0402FR-0733KL | C138003
39 | 15 | R1 R3 R14 R15 R16 R17 R21 R27 R28 R29 R75 R81 R85 R87 R88 | 100k 1% | https://jlcpcb.com/api/file/downloadByFileSystemAccessId/8579705919464263680 | resc_1005_04_m | Resistor, 100k, 1%, 100ppm, 1/16W, 1005, 0402 | UNI-ROYAL(Uniroyal Elec) | 0402WGF1003TCE | C25741
40 | 1 | R32 | 10k @25°C | https://jlcpcb.com/api/file/downloadByFileSystemAccessId/8588905414750572545 | resc_1005_04_m | NTC Thermistors 10k @25°C, B3950, 0.33mA max | Sunlord | SDNT1005X103F3950FTF | C95939
41 | 2 | S1 S2 | EVQ-PUC02K | https://jlcpcb.com/api/file/downloadByFileSystemAccessId/8588918409580974080 | EVQPUC02K | Small-sized Side-operational SMD Light Touch Switches with straight terminals, with boss. | Panasonic | EVQ-PUC02K | C79174
42 | 2 | S4 S5 | GT-TC120A-H120-L1 | https://jlcpcb.com/api/file/downloadByFileSystemAccessId/8588904166035374080 | GT-TC120A-H120-L1 | Tactile switch SMD, black round button 12mm. | G-Switch | GT-TC120A-H120-L1 | C2762973
43 | 1 | S3 | PEC11R-4215F-S0024 | https://jlcpcb.com/api/file/downloadByFileSystemAccessId/8588891509874049024 | PEC11R-4215F-S0024 | Rotary Encoders 15mm SHAFT w/SWITCH 24 detents, 24 PPR | Bourns | PEC11R-4215F-S0024 | C143790
44 | 1 | U5 | 74LVC1G08SE-7 | https://jlcpcb.com/api/file/downloadByFileSystemAccessId/8588934949626130432 | sot353_65p_200x125x110_mo-203-aa_n | Single 2-input AND gate | Diodes Incorporated | 74LVC1G08SE-7 | C460522
45 | 1 | U6 | CAT24C512YI-GT3 | https://jlcpcb.com/api/file/downloadByFileSystemAccessId/8588881550012796928 | JEDEC_MO-153_AA | 512 Kb I2C CMOS Serial | Onsemi | CAT24C512YI-GT3 | C56096
46 | 1 | U8 | INA228AIDGSR | https://www.ti.com/lit/ds/symlink/ina228.pdf | vssop10_50p_300x300x110_mfg | INA240 High- and Low-Side, Bidirectional, Zero-Drift, Current-Sense Amplifier with | Texas Instruments | INA228AIDGSR | C2887910
47 | 1 | U2 | LM2765 | https://www.ti.com/cn/lit/ds/symlink/lm2765.pdf?ts=1773109320900 | sot236_p95_290x160x110_n | Switched-Capacitor Voltage Converter, 40mA, input 1.8-5.5V, out =2xVIN, 50kHz, SOT-23, -40°C~+85°C | Texas Instruments | LM2765M6X/NOPB | C140270
48 | 2 | U11 U12 | LMR16006XDDCR | https://www.ti.com/cn/lit/ds/symlink/lmr16006.pdf?ts=1773033603279 | sot6_p95_290x180x110_n | LMR16006 SIMPLE SWITCHER® 60 V 0.6 A Buck Regulators With High Efficiency ECO mode, 600mA, input 4-65V, out 4-65V, 700kHz, SOT-6, -40°C~+125°C | Texas Instruments | LMR16006XDDCR | C87080
49 | 1 | U4 | LTC7004x | https://jlcpcb.com/api/file/downloadByFileSystemAccessId/8588908169414520832 | msop_10p_300x490x110_tp168x188_n | Fast 60V High Side NMOS Static Switch Driver. | Analog Devices | LTC7004EMSE#TRPBF | C690106
50 | 1 | U9 | RP2040 | https://pip-assets.raspberrypi.com/categories/814-rp2040/documents/RP-008371-DS-1-rp2040-datasheet.pdf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 | qfn56_40p_700x700x90_tp_320x320_mfg | ARM® Cortex-M0+ - Microcontroller IC 32-Bit Dual-Core 133MHz External Program Memory 56-QFN (7x7) | Raspberry Pi | SC0914(13) | C2040
51 | 1 | U7 | SN74LVC1G17DBVR | https://www.ti.com/lit/ds/symlink/sn74lvc1g17.pdf?ts=1773125655769 | sot25_95p_300x280x145_jedec_mo-178-aa_n | SN74LVC1G17 Single Schmitt-Trigger Buffer | Texas Instruments | SN74LVC1G17DBVR | C7836
52 | 1 | U1 | TPD4S480RUKR | https://www.ti.com/lit/ds/symlink/tpd4s480.pdf?ts=1773161250726 | wqfn20_40p_300x300x80_tp_170x170_n | USB Type-C™ 48V EPR port protector with short-to-VBUS overvoltage and IEC ESD protection 20-WQFN -40 to 125 | Texas Instrument | TPD4S480RUKR | C43131250
53 | 1 | U3 | TPS26750SRSMR | https://www.ti.com/lit/ds/symlink/tps26750.pdf | qfn32_40p_400x400x100_tp_280x280_mfg | TPS26750 USB Type-C® and USB PD Controller With Integrated Power Switches | Texas Instruments | TPS26750SRSMR | C42166327
54 | 1 | U10 | W25Q128JVPIQ | https://jlcpcb.com/api/file/downloadByFileSystemAccessId/8588881960005472256 | wson8_127p_600x500x80_tp_435x340_n | 3V 128M-BIT SERIAL FLASH MEMORY WITH DUAL/QUAD SPI | Winbond Electronics | W25Q128JVPIQ | C190862
55 | 1 | Y1 | ABM8-272-T3 | https://jlcpcb.com/api/file/downloadByFileSystemAccessId/8559470777180311552 | osccc_320x205x80_abm8 | Crystal 12MHz 10pF 30ppm -40C +85C | Abracon LLC | ABM8-272-T3 | C20625731

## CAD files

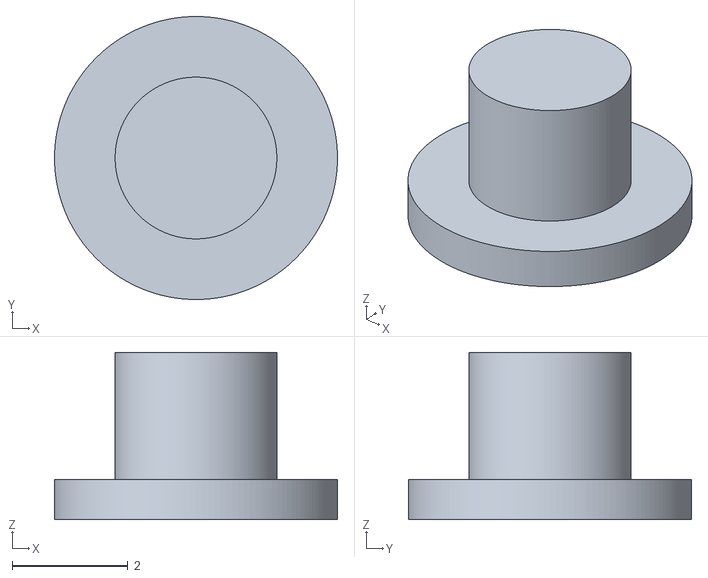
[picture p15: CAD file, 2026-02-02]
3D_models/enclosure/button.stl
4.90 x 4.90 x 2.90

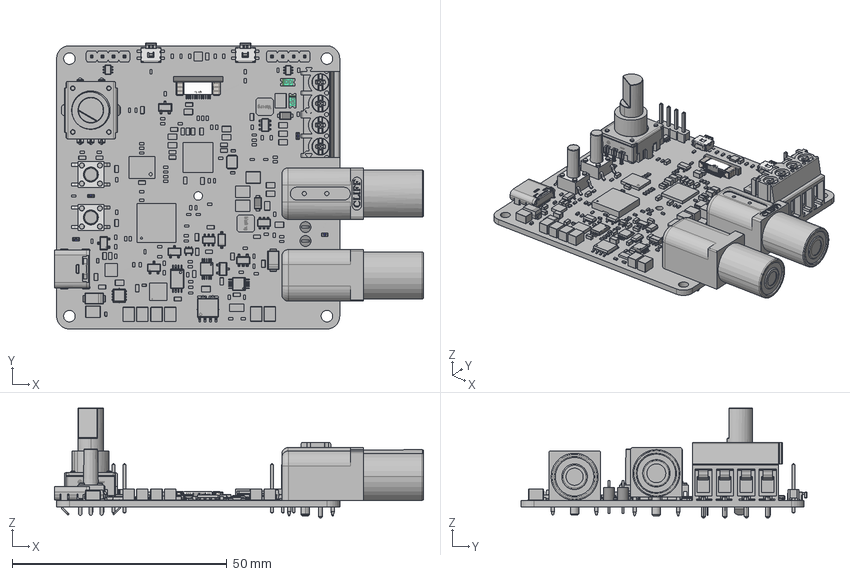
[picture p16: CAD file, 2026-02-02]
3D_models/PD240W_PCB.stp
86.0 x 66.7 x 25.6 mm

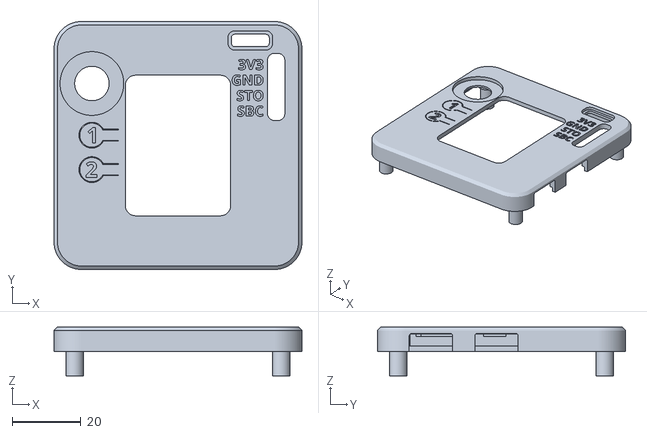
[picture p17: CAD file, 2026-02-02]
3D_models/enclosure/casing_top.stl
72.0 x 72.0 x 14.2

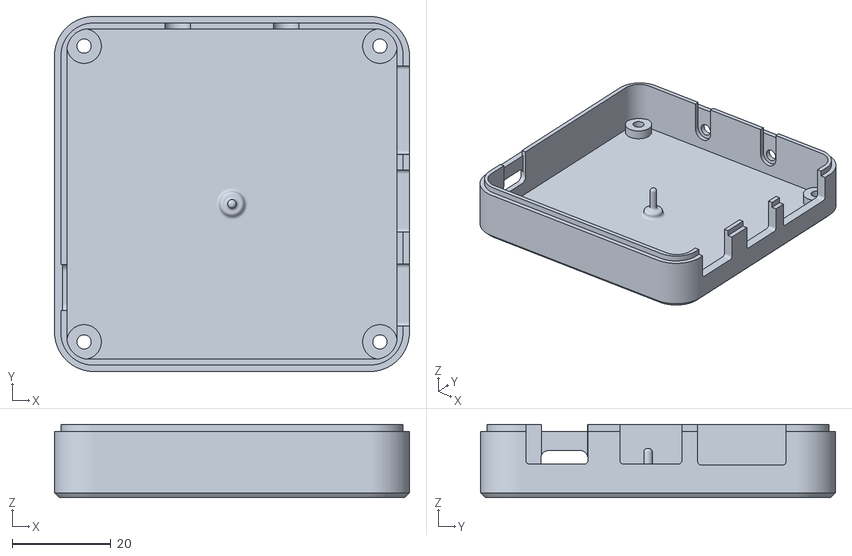
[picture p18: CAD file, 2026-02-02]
3D_models/enclosure/casing_bottom.stl
72.0 x 72.0 x 14.9

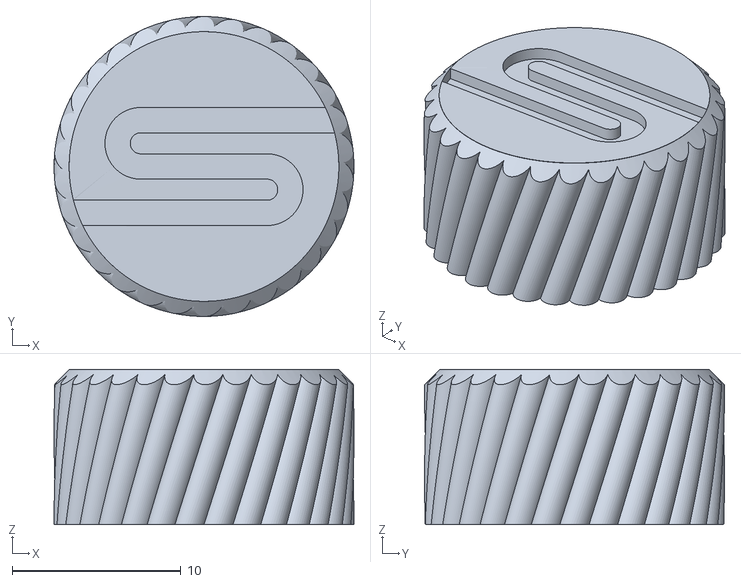
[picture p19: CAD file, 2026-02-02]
3D_models/enclosure/knob.stl
17.8 x 17.8 x 9.21

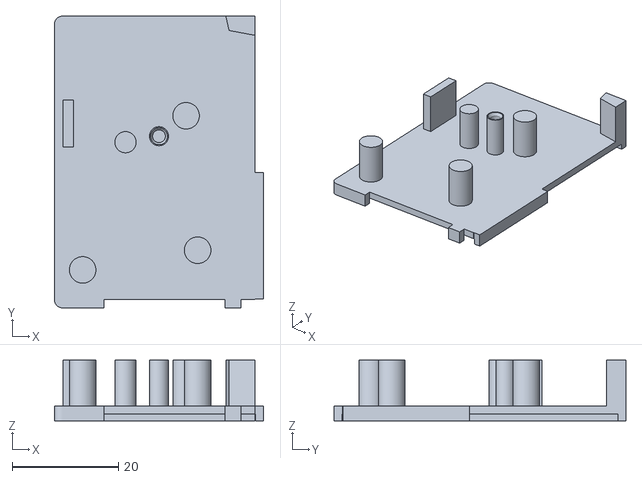
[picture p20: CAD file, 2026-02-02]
3D_models/enclosure/lcd_support.stl
39.4 x 55.0 x 11.5

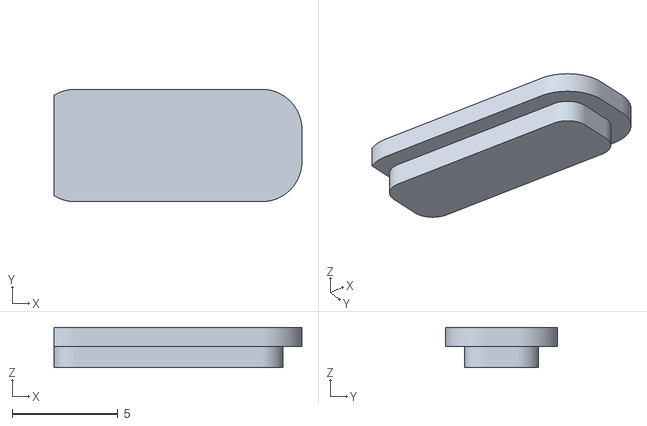
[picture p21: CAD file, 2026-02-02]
3D_models/enclosure/swd_cover.stl
11.7 x 5.30 x 1.90

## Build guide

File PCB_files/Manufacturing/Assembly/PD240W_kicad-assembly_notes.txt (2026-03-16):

ASSEMBLY NOTES (UNLESS OTHERWISE SPECIFIED)

1)	DO NOT POPULATE PARTS ARE MARKED WITH A RED CROSS.

2)	DO NOT POPULATE PARTS THAT ARE NOT PRESENT IN THE BOM.

3)	IF CONFLICTING INFORMATION IS FOUND BETWEEN THE ASSEMBLY
	FILE AND BOM, BOM SHOULD BE USED AS THE MAIN SOURCE.

4)	CONFORMAL COATING IS NOT REQUIRED.

5)	DOT OR TRIANGLE IDENTIFIES PIN #1 LOCATION AND DEVICE 
	ORIENTATION WHEN VIEWED FROM THE TOP.

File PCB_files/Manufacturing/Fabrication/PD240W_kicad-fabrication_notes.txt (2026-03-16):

FABRICATION NOTES (UNLESS OTHERWISE SPECIFIED)

1)	FABRICATE PER IPC-6012A CLASS 2.

2)	OUTLINE DEFINED IN SEPARATE GERBER FILE WITH
	"Edge_Cuts.GBR" SUFFIX.

	DIMENSIONS OF CIRCUMSIZED RECTANGLE SHOWN ON THIS
	DRAWING FOR REFERENCE ONLY.

3)	SEE SEPARATE DRILL FILES WITH ".DRL" SUFFIX 
	FOR HOLE LOCATIONS.

	SELECTED HOLE LOCATIONS SHOWN ON THIS DRAWING 
	FOR REFERENCE ONLY.

4)	SURFACE FINISH: IMMERSION GOLD

5)	SOLDERMASK ON BOTH SIDES OF THE BOARD SHALL 
	BE LPI, COLOR BLACK.

6)	SILK SCREEN LEGEND TO BE APPLIED PER LAYER 
	STACKUP USING WHITE NON-CONDUCTIVE EPOXY INK.

7)	ALL VIAS ARE TENTED ON BOTH SIDES UNLESS 
	SOLDERMASK OPENED IN GERBER.

8)	VENDOR SHOULD FOLLOW ROHS COMPLIANT PROCESS 
	AND Pb FREE FOR MANUFACTURING

9)	PCB MATERIAL REQUIREMENTS:

	A.	FLAMMABILITY RATING MUST MEET OR EXCEED 
		UL94V-0 REQUIREMENTS.
	B.	Tg 170 C OR EQUIVALENT.
	C.	EQUIVALENT MATERIAL SHALL BE RoHS COMPLIANT, 
		HALOGEN FREE AND APPROVED BY COMPANY NAME.

10)	DESIGN GEOMETRY MINIMUM FEATURE SIZES:

	BOARD SIZE				66.000 × 66.000 mm
	BOARD THICKNESS		1.578 mm
	TRACE WIDTH			0.150 mm
	TRACE TO TRACE		-0.000 mm
	MIN. HOLE (PTH)			0.300 mm
	MIN. HOLE (NPTH)		0.750 mm
	ANNULAR RING			0.100 mm
	COPPER TO HOLE		0.254 mm
	COPPER TO EDGE		0.250 mm
	HOLE TO HOLE			0.254 mm

11)	REFER TO IMPEDANCE TABLE FOR IMPEDANCE CONTROL REQUIREMENTS.

12)	CONFIRM SPACE WIDTHS AND SPACINGS.

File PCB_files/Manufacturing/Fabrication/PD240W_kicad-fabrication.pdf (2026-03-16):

# Top Fabrication (Scale 1:1)

# PD240W Fabrication Document

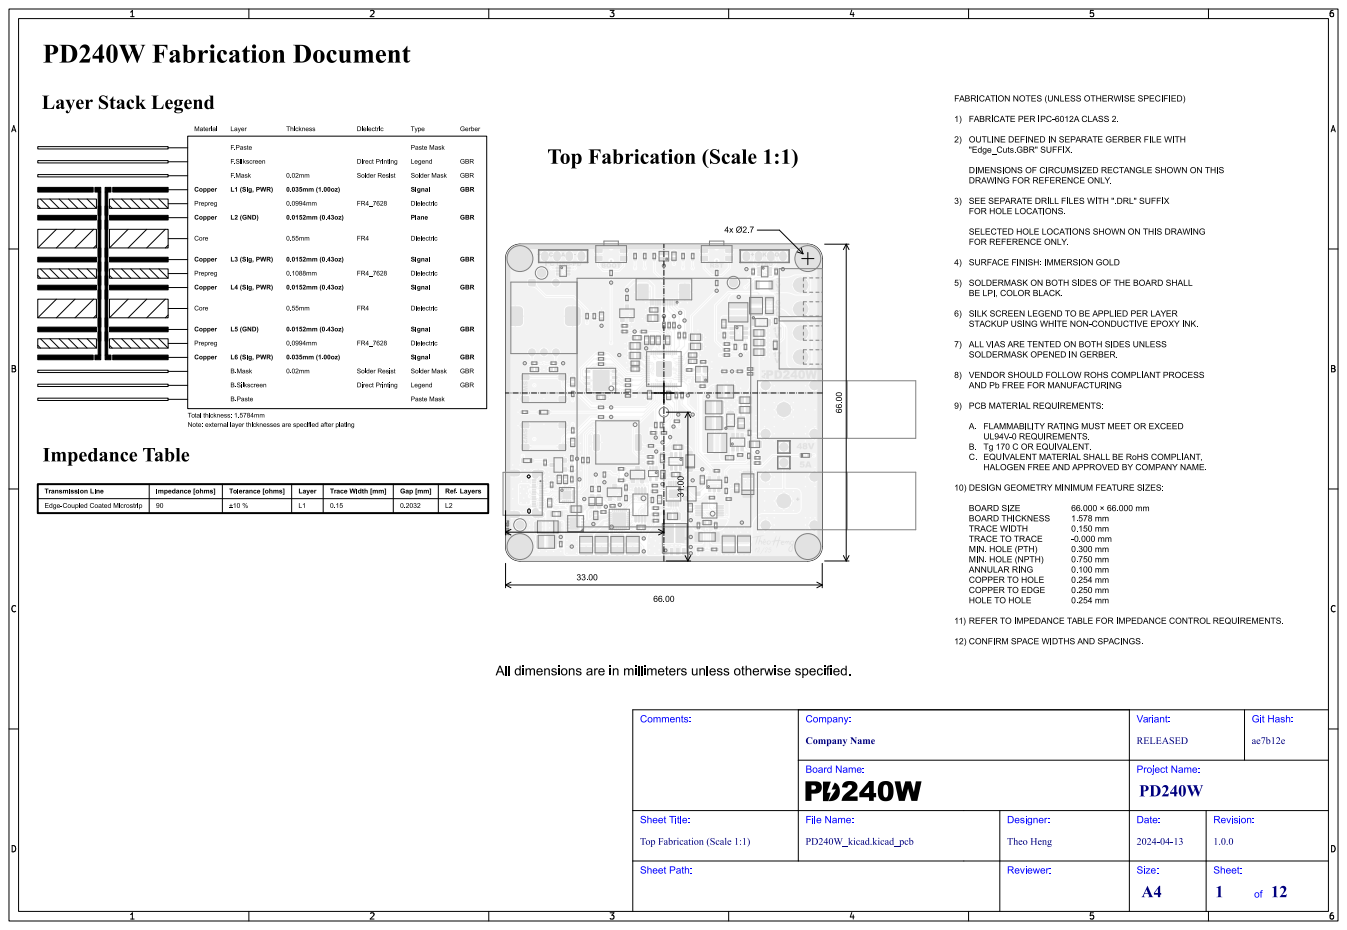
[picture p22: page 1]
Git Hash:; Comments:; Sheet Path:; Sheet Title:; File Name:; Company Name; Company:; RELEASED; Variant:; Board Name:; PD240W_kicad.kicad_pcb; Theo Heng; Designer:; Reviewer:; Project Name:; Date:; Revision:; Size:; Sheet:; 6 PCB EDGE

Top Fabrication (Scale 1:1)

# Bottom Fabrication (Scale 1:1)

# PD240W Fabrication Document

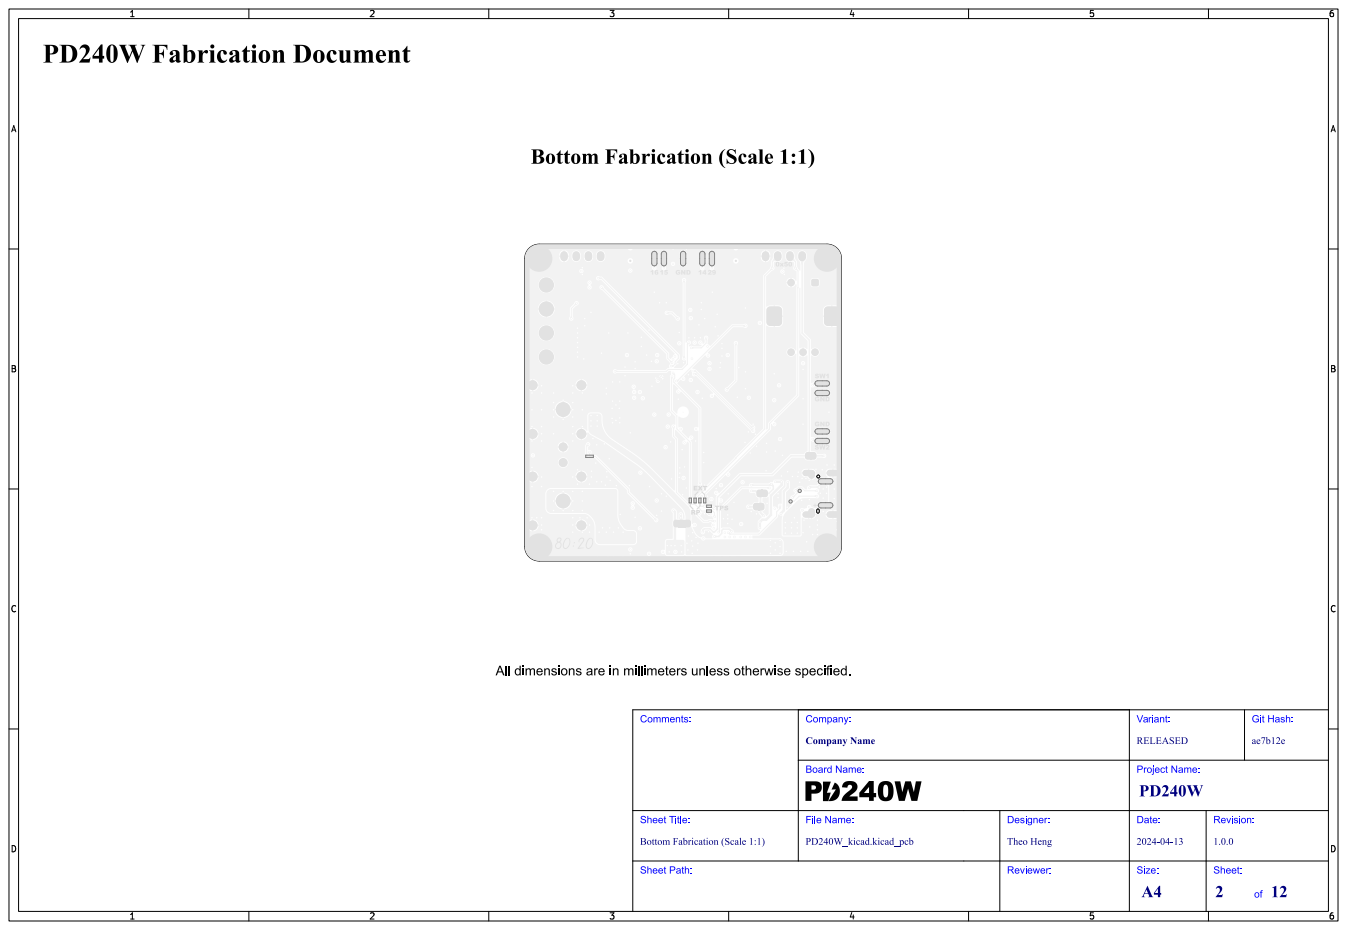
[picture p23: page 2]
Git; Hash:; Comments:; Sheet Path:; Sheet Title:; File Name:; Company Name; Company:; RELEASED; Variant:; Board Name:; PD240W_kicad.kicad_pcb; Theo Heng; Designer:; Reviewer:; Project Name:; Date:; Revision:; Size:; Sheet:

Bottom Fabrication (Scale 1:1)

# Drill Drawing L1 - L6 (Scale 1:1)

# PD240W Fabrication Document

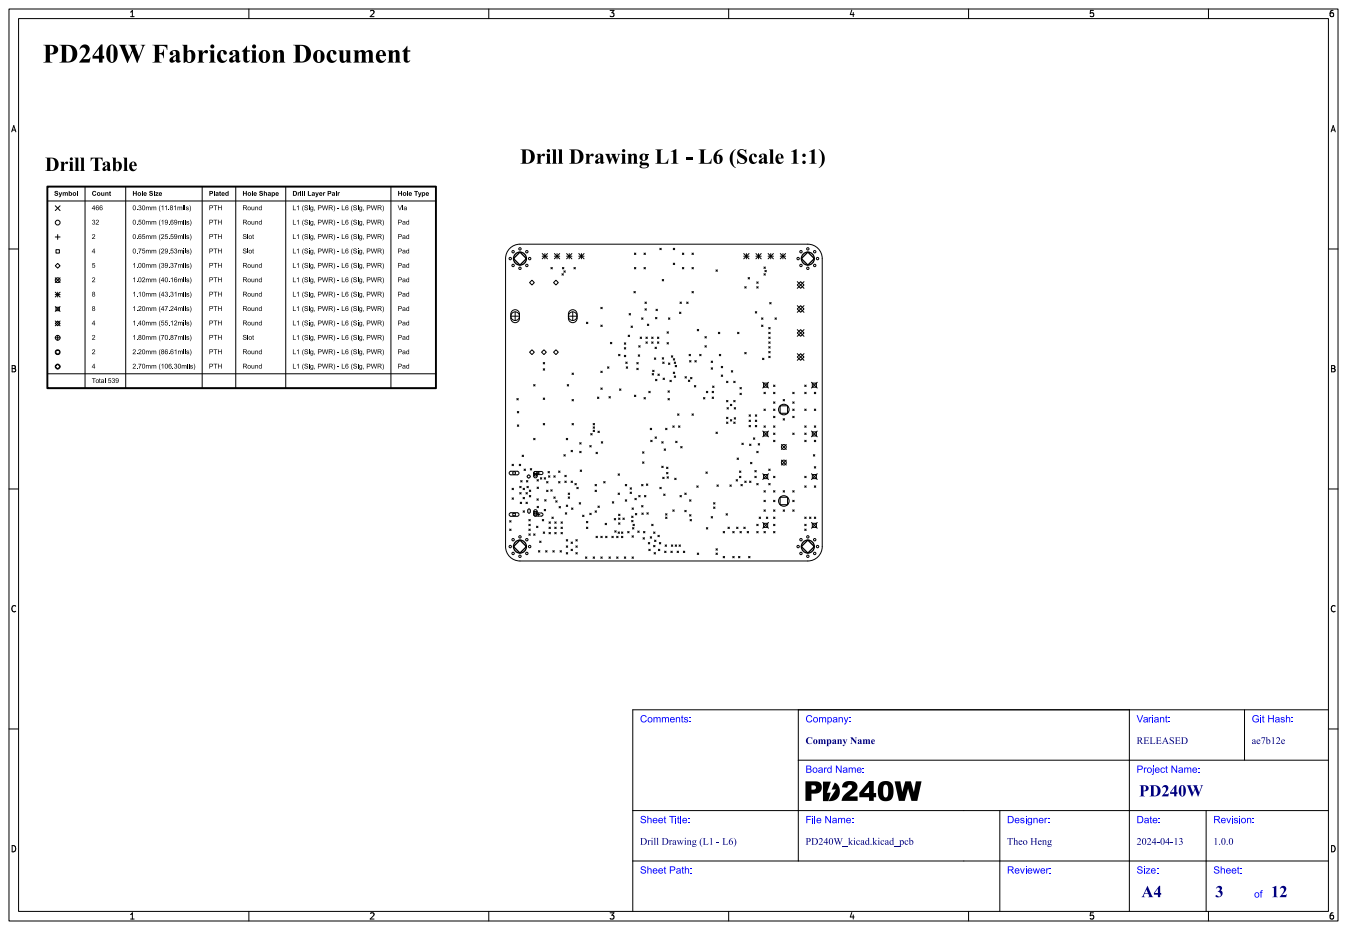
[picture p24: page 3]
Git; Hash:; Comments:; Drill Drawing (L1 - L6); Sheet Path:; Sheet Title:; File Name:; Company Name; Company:; RELEASED; Variant:; Board Name:; PD240W_kicad.kicad_pcb; Theo Heng; Designer:; Reviewer:; Project Name:; Date:; Revision:; Size:; Sheet:

# Drill Drawing L1 - L6 (Scale 1:1)

# PD240W Fabrication Document

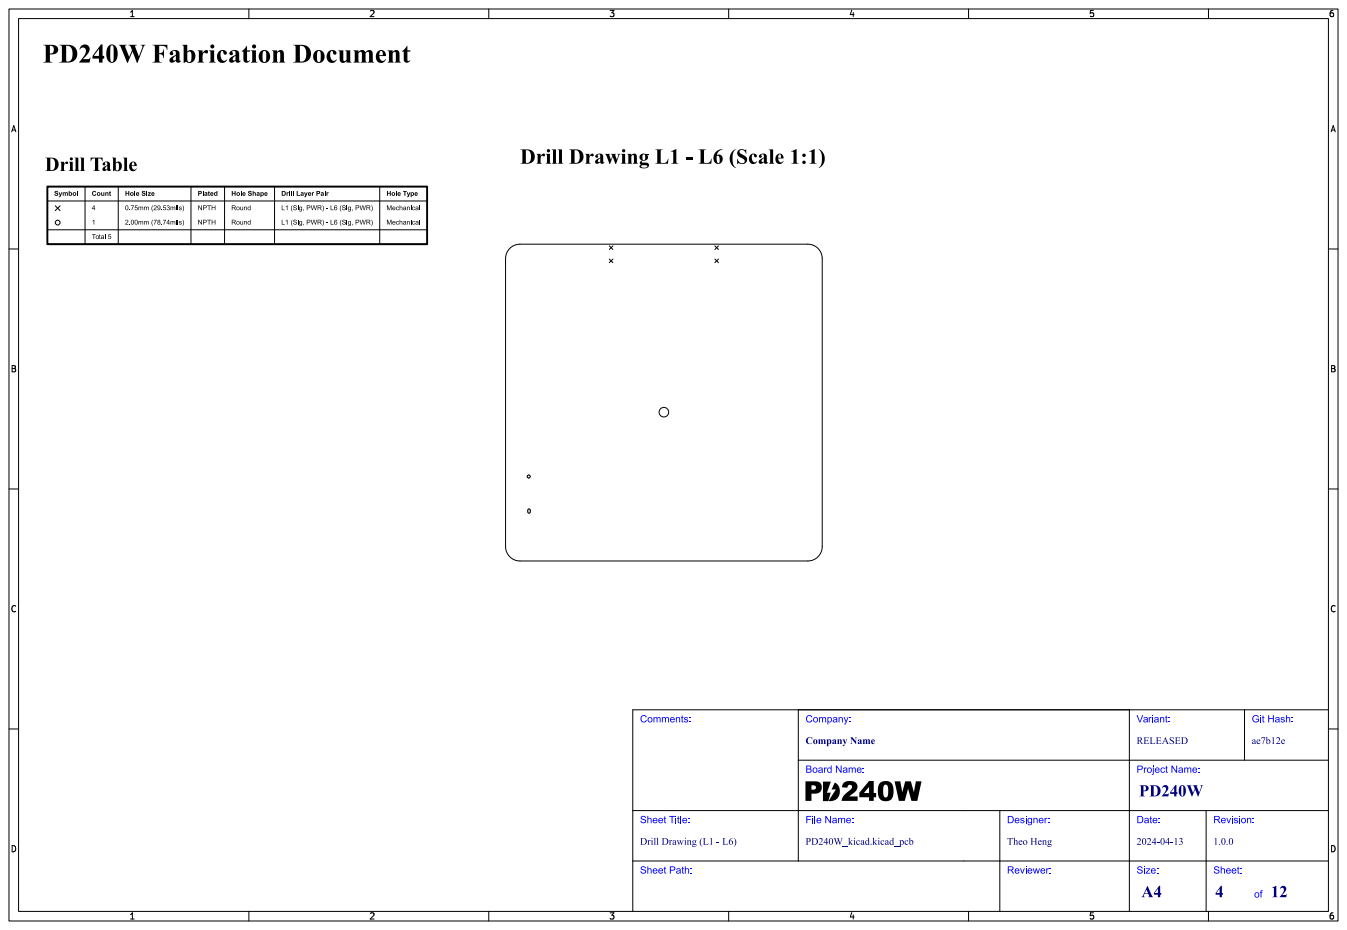
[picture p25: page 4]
Git; Hash:; Comments:; Drill Drawing (L1 - L6); Sheet Path:; Sheet Title:; File Name:; Company Name; Company:; RELEASED; Variant:; Board Name:; PD240W_kicad.kicad_pcb; Theo Heng; Designer:; Reviewer:; Project Name:; Date:; Revision:; Size:; Sheet:

# Top Test Points (Scale 1:1)

# PD240W Fabrication Document

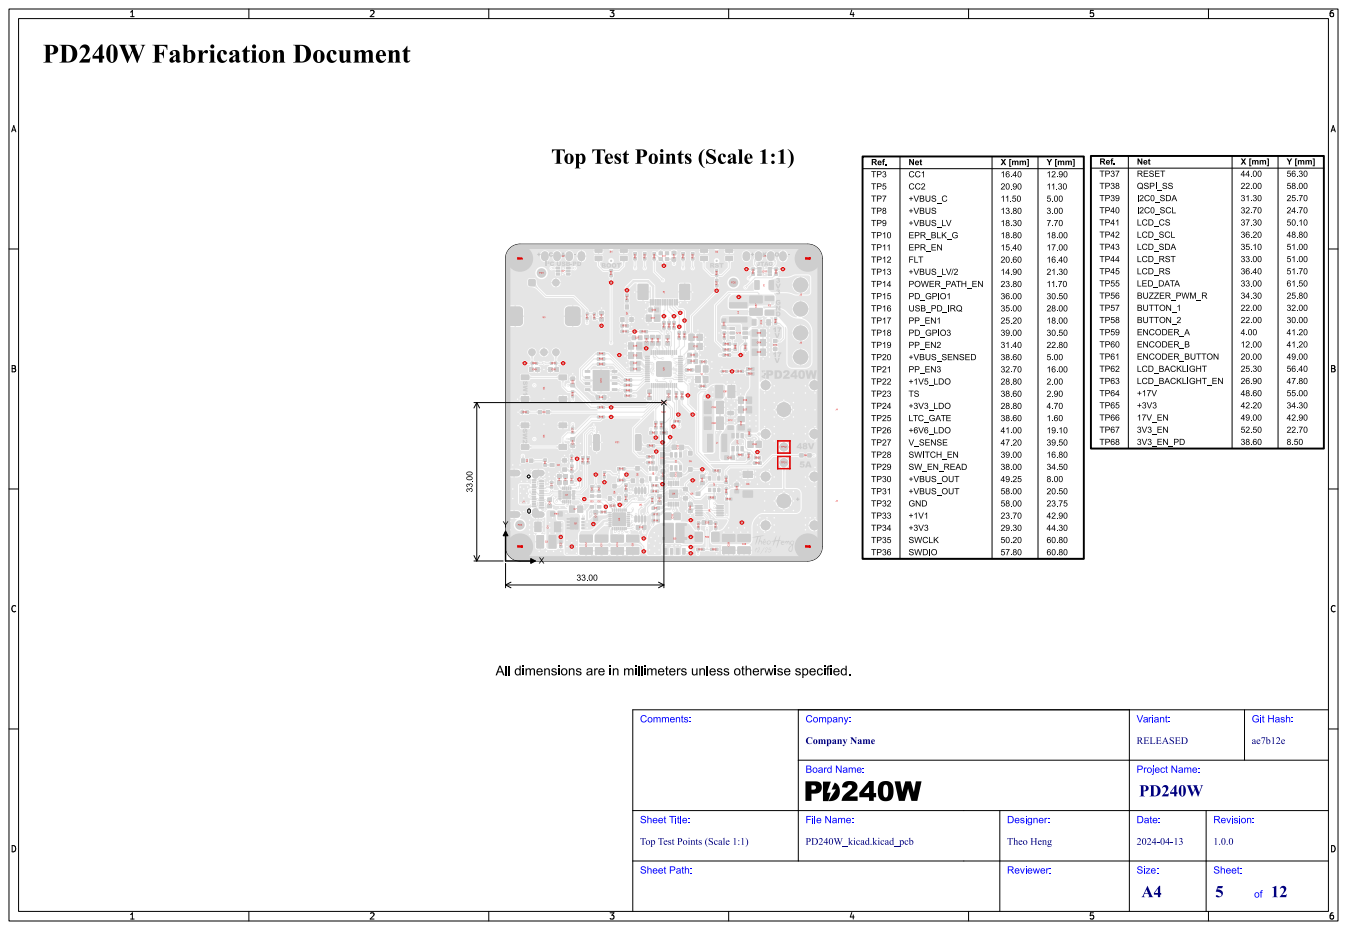
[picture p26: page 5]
Git Hash:; Comments:; Sheet Path:; Sheet Title:; File Name:; Company Name; Company:; RELEASED; Variant:; Board Name:; PD240W_kicad.kicad_pcb; Theo Heng; Designer:; Reviewer:; Project Name:; Date:; Revision:; Size:; Sheet:

Top Test Points (Scale 1:1)

# Bottom Test Points (Scale 1:1)

# PD240W Fabrication Document

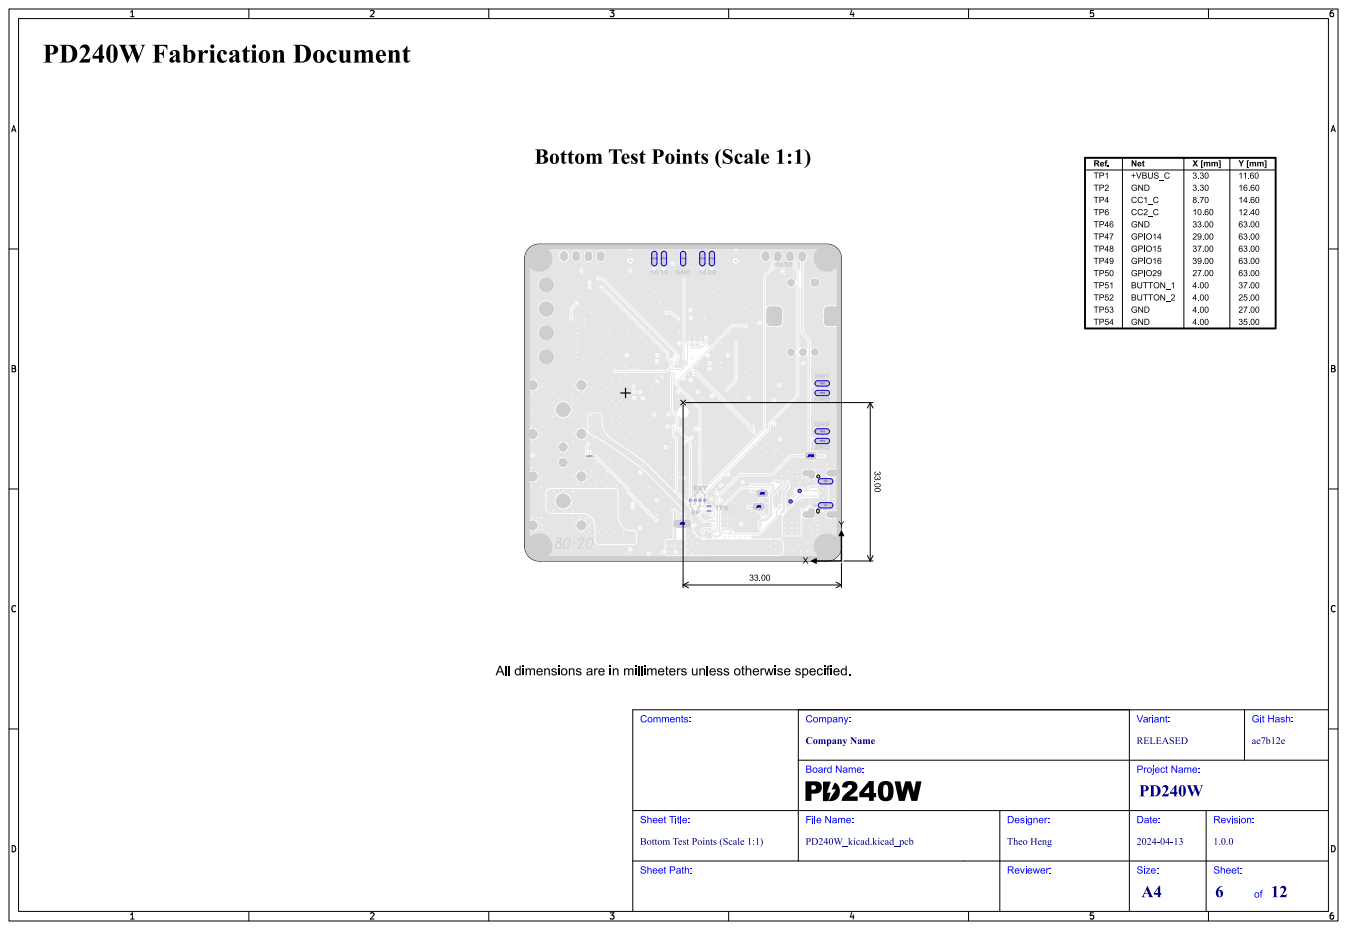
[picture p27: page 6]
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

Bottom Test Points (Scale 1:1)

# L1 (Sig, PWR) (Scale 1:1)

# PD240W Fabrication Document

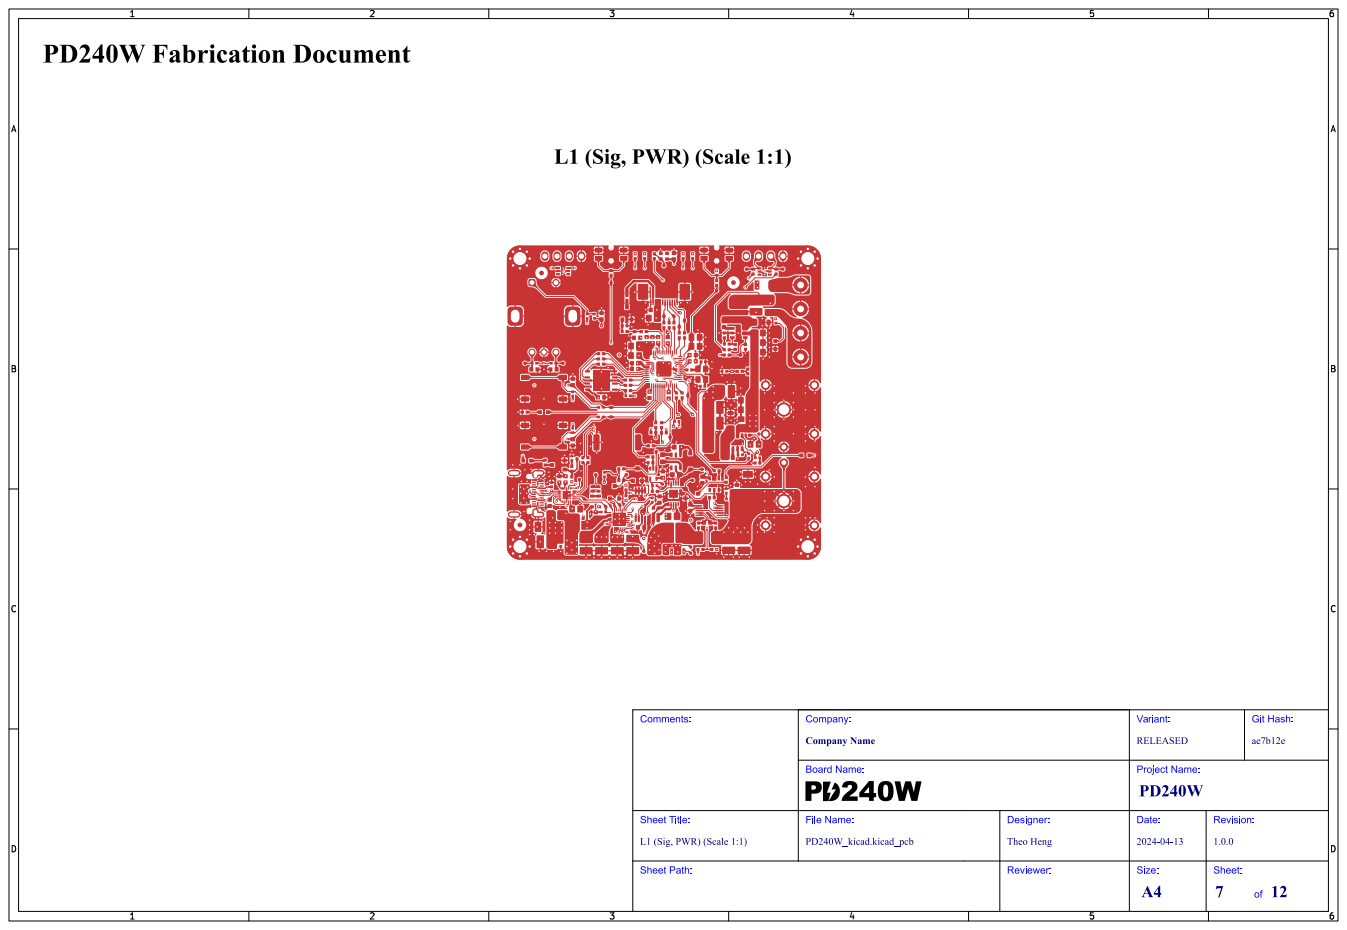
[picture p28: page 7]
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

L1 (Sig, PWR) (Scale 1:1)

# L2 (GND) (Scale 1:1)

# PD240W Fabrication Document

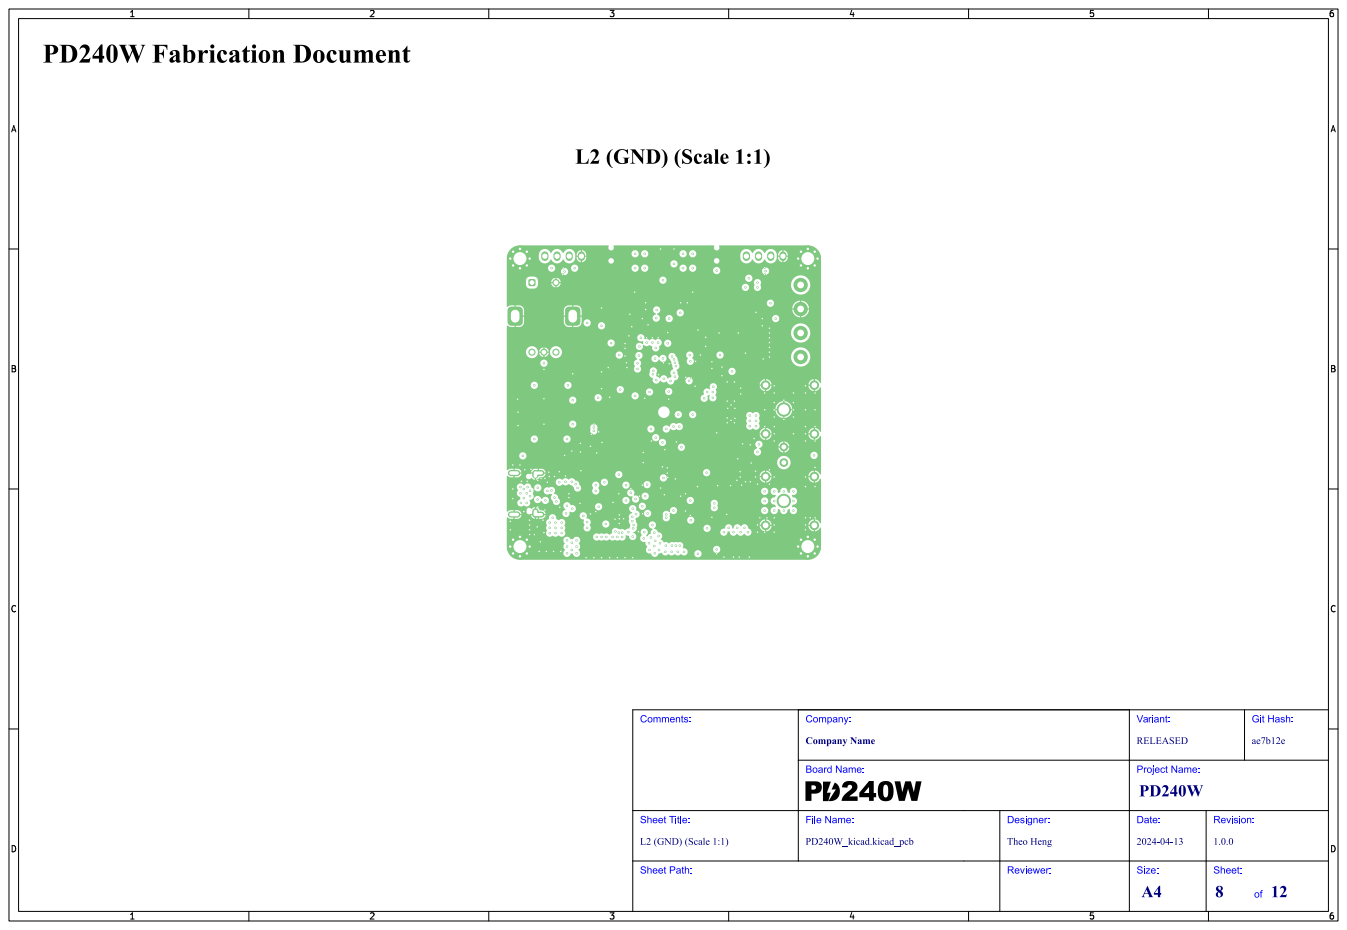
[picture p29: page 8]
Git; Hash:; Comments:; L2 (GND) (Scale 1:1); Sheet Path:; Sheet Title:; File Name:; Company Name; Company:; RELEASED; Variant:; Board Name:; PD240W_kicad.kicad_pcb; Theo Heng; Designer:; Reviewer:; Project Name:; Date:; Revision:; Size:; Sheet:

# L3 (Sig, PWR) (Scale 1:1)

# PD240W Fabrication Document

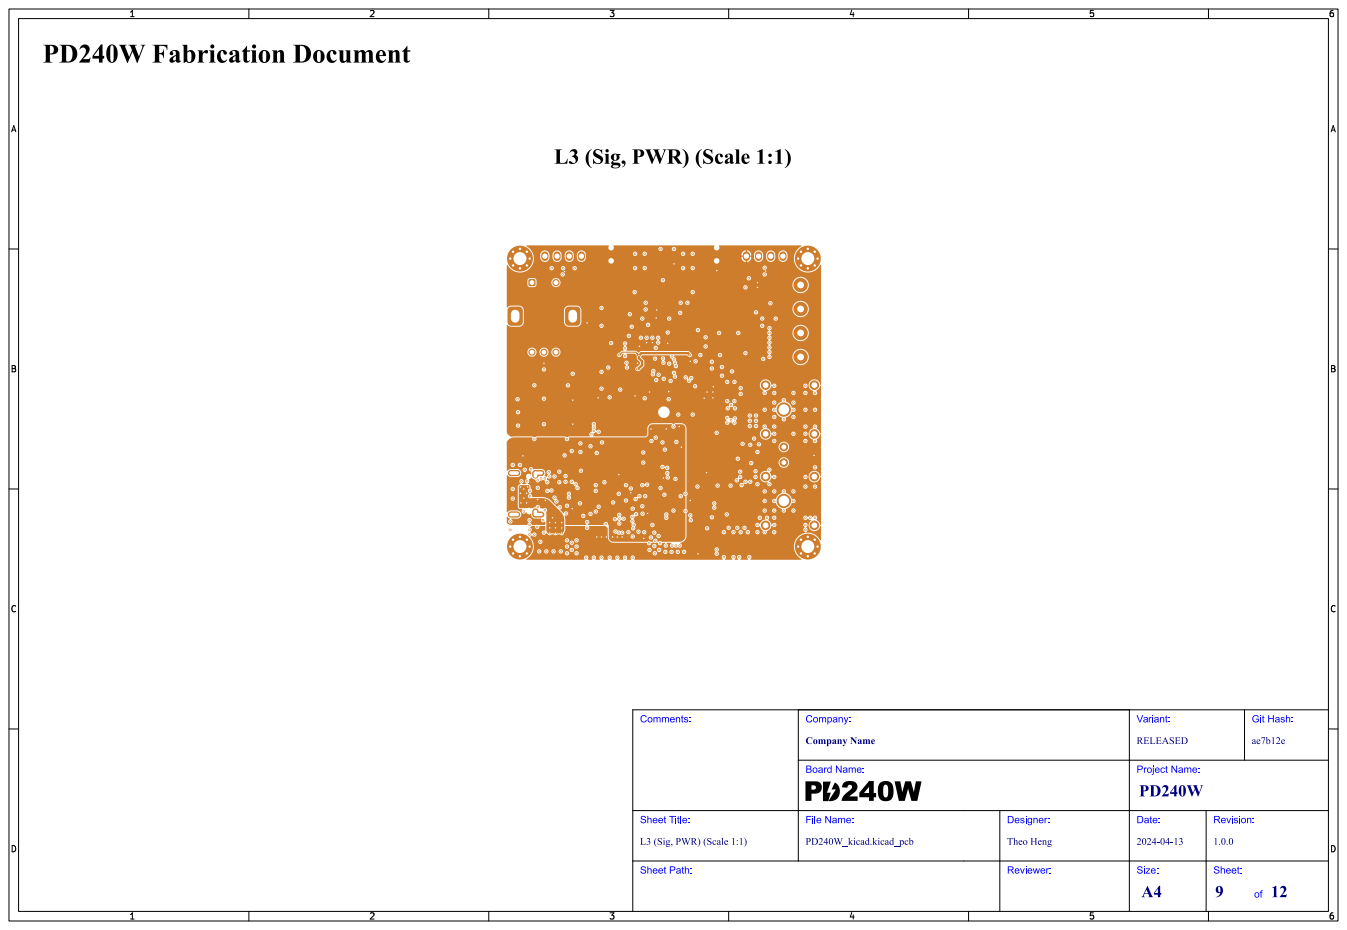
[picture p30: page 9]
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

L3 (Sig, PWR) (Scale 1:1)

# L4 (Sig, PWR) (Scale 1:1)

# PD240W Fabrication Document

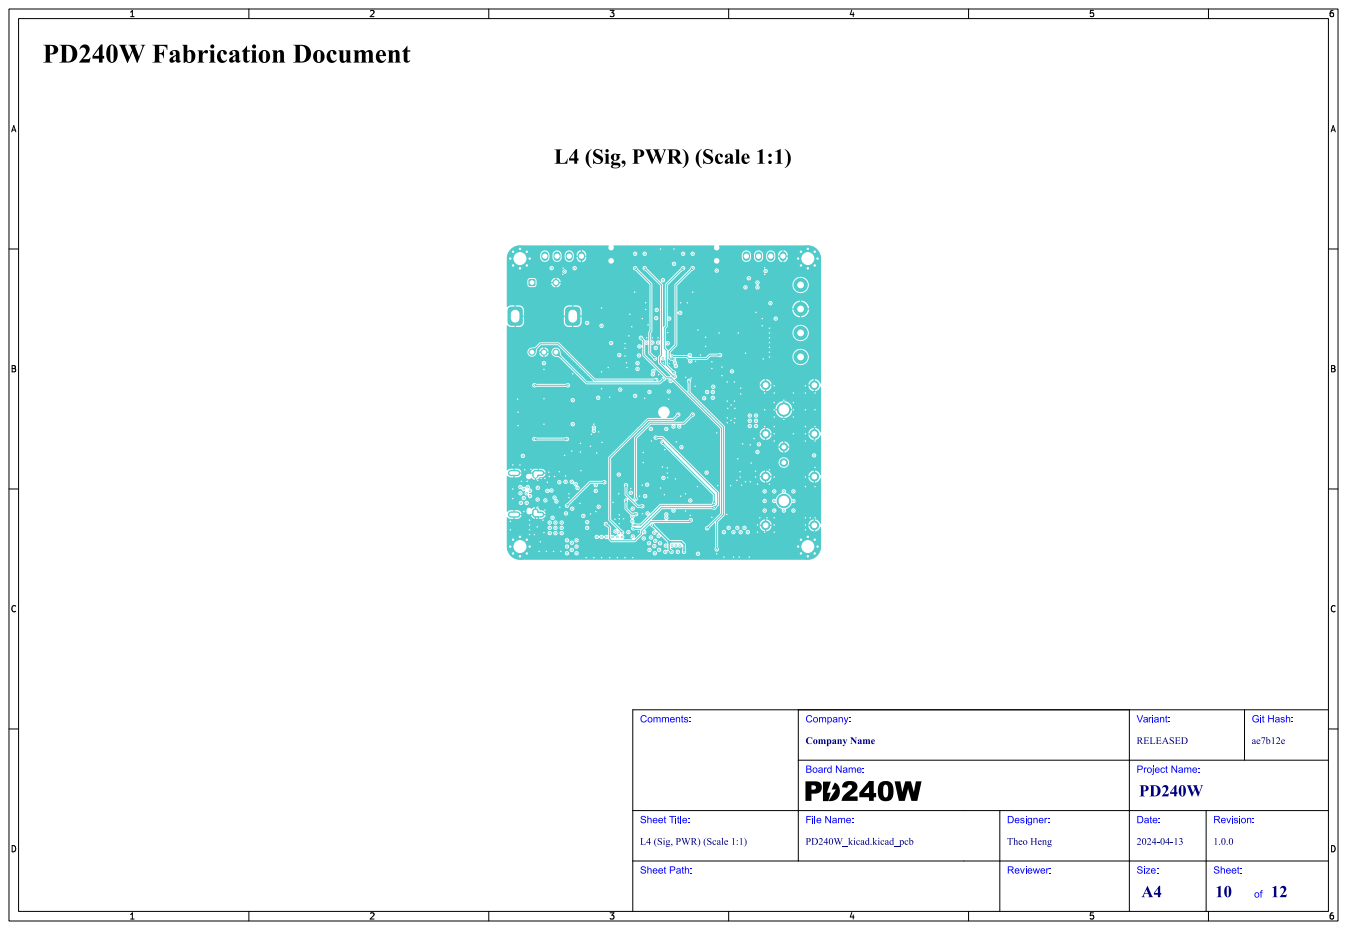
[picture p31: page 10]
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

L4 (Sig, PWR) (Scale 1:1)

# L5 (GND) (Scale 1:1)

# PD240W Fabrication Document

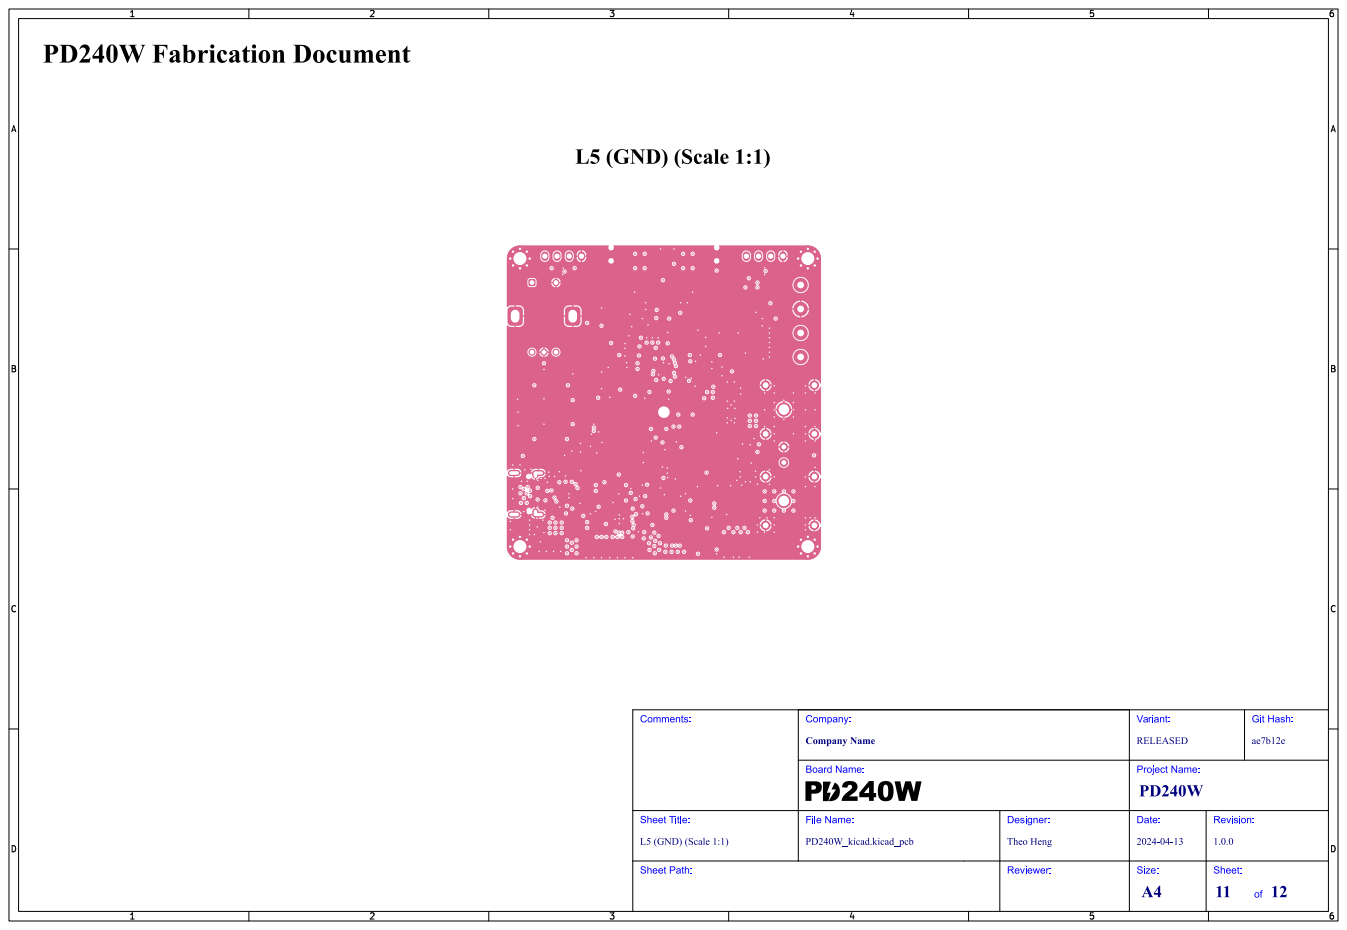
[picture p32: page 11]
Git; Hash:; Comments:; L5 (GND) (Scale 1:1); Sheet Path:; Sheet Title:; File Name:; Company Name; Company:; RELEASED; Variant:; Board Name:; PD240W_kicad.kicad_pcb; Theo Heng; Designer:; Reviewer:; Project Name:; Date:; Revision:; Size:; Sheet:

# L6 (Sig, PWR) (Scale 1:1)

# PD240W Fabrication Document

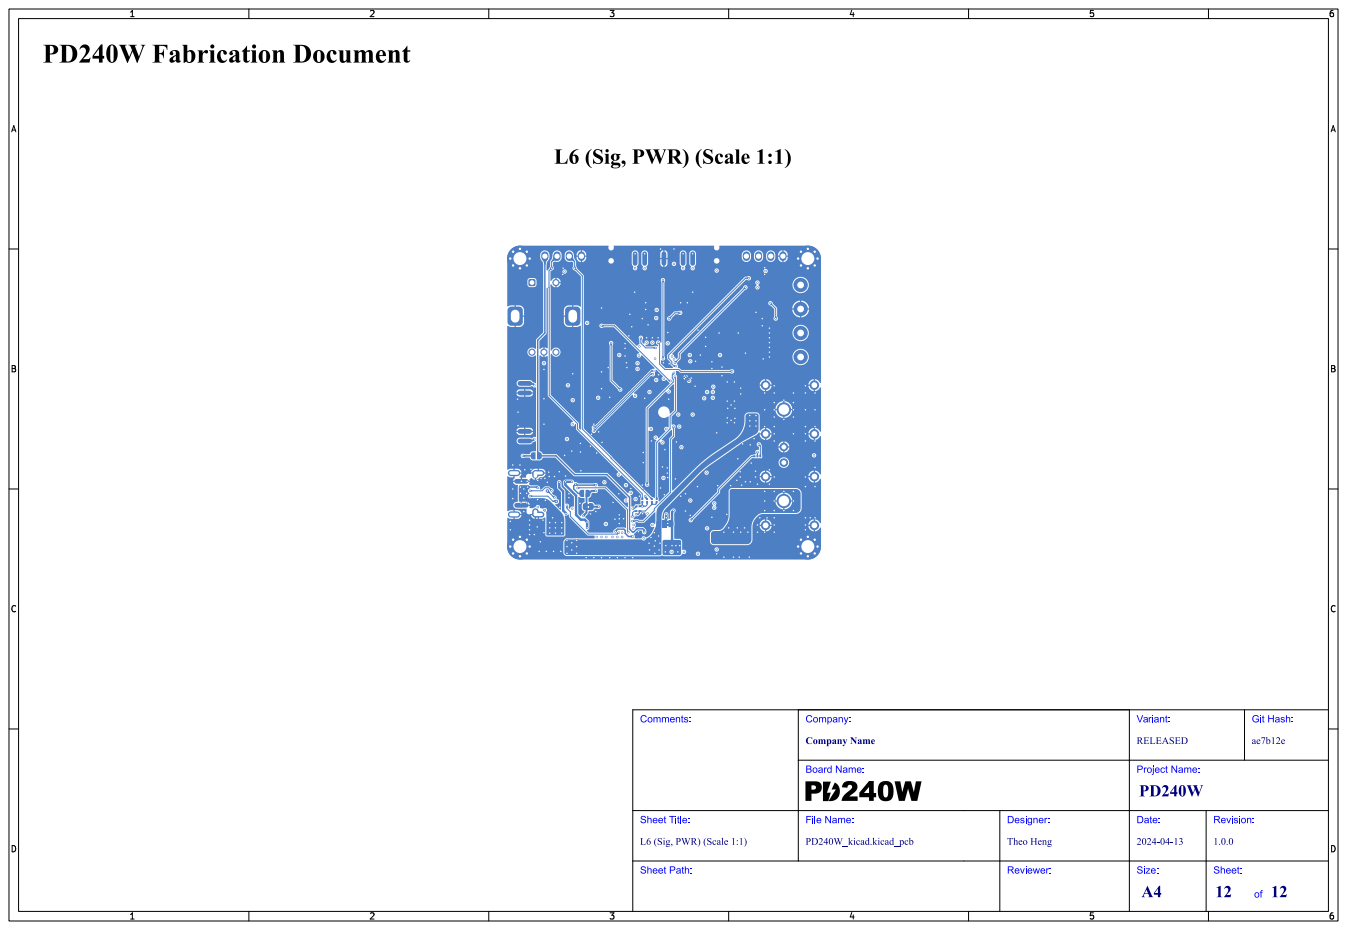
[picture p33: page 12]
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

L6 (Sig, PWR) (Scale 1:1)

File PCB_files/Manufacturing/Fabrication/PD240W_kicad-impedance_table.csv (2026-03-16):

Transmission Line | Impedance [ohms] | Tolerance [ohms] | Layer | Trace Width [mm] | Gap [mm] | Ref. Layers
Edge-Coupled Coated Microstrip | 90 | ±10 % | L1 | 0.15 | 0.2032 | L2

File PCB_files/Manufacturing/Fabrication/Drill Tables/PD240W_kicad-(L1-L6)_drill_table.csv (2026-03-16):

Count | Hole Size | Plated | Hole Shape | Drill Layer Pair | Hole Type
466 | 0.30mm (11.81mils) | PTH | Round | L1 (Sig, PWR) - L6 (Sig, PWR) | Via
32 | 0.50mm (19.69mils) | PTH | Round | L1 (Sig, PWR) - L6 (Sig, PWR) | Pad
2 | 0.65mm (25.59mils) | PTH | Slot | L1 (Sig, PWR) - L6 (Sig, PWR) | Pad
4 | 0.75mm (29.53mils) | PTH | Slot | L1 (Sig, PWR) - L6 (Sig, PWR) | Pad
5 | 1.00mm (39.37mils) | PTH | Round | L1 (Sig, PWR) - L6 (Sig, PWR) | Pad
2 | 1.02mm (40.16mils) | PTH | Round | L1 (Sig, PWR) - L6 (Sig, PWR) | Pad
8 | 1.10mm (43.31mils) | PTH | Round | L1 (Sig, PWR) - L6 (Sig, PWR) | Pad
8 | 1.20mm (47.24mils) | PTH | Round | L1 (Sig, PWR) - L6 (Sig, PWR) | Pad
4 | 1.40mm (55.12mils) | PTH | Round | L1 (Sig, PWR) - L6 (Sig, PWR) | Pad
2 | 1.80mm (70.87mils) | PTH | Slot | L1 (Sig, PWR) - L6 (Sig, PWR) | Pad
2 | 2.20mm (86.61mils) | PTH | Round | L1 (Sig, PWR) - L6 (Sig, PWR) | Pad
4 | 2.70mm (106.30mils) | PTH | Round | L1 (Sig, PWR) - L6 (Sig, PWR) | Pad
Total 539

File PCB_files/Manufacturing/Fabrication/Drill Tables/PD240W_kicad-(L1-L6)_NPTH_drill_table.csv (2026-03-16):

Count | Hole Size | Plated | Hole Shape | Drill Layer Pair | Hole Type
4 | 0.75mm (29.53mils) | NPTH | Round | L1 (Sig, PWR) - L6 (Sig, PWR) | Mechanical
1 | 2.00mm (78.74mils) | NPTH | Round | L1 (Sig, PWR) - L6 (Sig, PWR) | Mechanical
Total 5

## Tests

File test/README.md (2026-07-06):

# PD240W Host Unit Tests

Host-side (x86/ARM desktop) unit tests for the hardware-free logic in the
firmware. These compile the pure logic headers directly — no Pico SDK, no
target hardware — and run in well under a second under
[Snitch](https://github.com/snitch-org/snitch), with AddressSanitizer and
UndefinedBehaviorSanitizer enabled by default.

Only logic that is decoupled from the Pico SDK can be tested here: a module is
host-buildable when none of the headers it includes pull in `pico/*`.

---

## Build and run

Configure into a `build/` subdirectory (in-source builds are rejected):

```bash
cd test
cmake -G Ninja -B build       # configure (downloads Snitch on first run)
cmake --build build           # compile
cd build && ctest --output-on-failure
```

`ctest --output-on-failure` runs the suite and prints detail only on failure.
Running the binary directly (`./build/pd240w_tests`) shows Snitch's full report;
pass `--help` for filtering options.

The first configure takes longer because CMake fetches the Snitch framework via
`FetchContent`; subsequent configures reuse the cached copy.

---

## Options

Pass these to the configure step:

| Flag | Default | Effect |
|---|---|---|
| `-DENABLE_SANITIZERS=OFF` | ON | Disable ASan/UBSan (faster; loses memory/UB checking) |
| `-DENABLE_COVERAGE=OFF` | ON | Instrument for gcov and add a `coverage` target |

Changing an option requires re-running configure, e.g.
`cmake -G Ninja -B build -DENABLE_COVERAGE=OFF`.

---

## Coverage report

Coverage reports which lines the tests exercise. It requires `lcov` and
`genhtml`, which are not installed on macOS by default:

```bash
brew install lcov             # macOS; on Debian/Ubuntu: apt install lcov
```

Then:

```bash
cd test
cmake -G Ninja -B build -DENABLE_COVERAGE=ON
cmake --build build --target coverage
open build/coverage_report/index.html
```

Notes:

- The `coverage` target only exists when configured with `-DENABLE_COVERAGE=ON`.
- Without `lcov`/`genhtml` the target reports that they are missing rather than
  producing an empty result.

---

## Suites

| Suite | Module under test |
|---|---|
| `test_pd_diagnostics.cpp` | `src/logic/pd_diagnostics.h` — startup-contract matching (PPS/AVS clamping and step alignment), charger-identity VDO decode, cable-rating inference, PD-revision (PD2.0/3.0/3.1/3.2) inference from PDO shape, and power/vendor/string helpers |
| `test_settings_storage.cpp` | `src/logic/settings_storage.h` — flash-image CRC32 integrity, magic/version validation, v4/v5 → v6 migration, factory defaults, and the setter value clamps |
| `test_thermal_monitor.cpp` | `src/logic/thermal_monitor.h` — the 3-band (caution/warning/fault) overtemperature FSM with 2 °C hysteresis, latching, edge signalling, and display-status level |
| `test_programmable_tuning.cpp` | `src/logic/programmable_tuning.h` — the PPS/AVS auto-tuning corrector: convergence check, accumulating P-correction with ±clamp, and request-voltage clamp/step-align |

---

## How the host build sees hardware types

`pd_diagnostics.h` depends on two data types that were previously
hardware-coupled:

- `TPS26750_SourceCapability` — the TPS26750 driver is multiplatform. The test
  build defines `TPS26750_PLATFORM_NATIVE` (see `CMakeLists.txt`), selecting a
  desktop code path so its plain-data structs compile without an MCU I2C layer.
- `SavedStartupContractType` — extracted, with the other flash enums, into
  `src/logic/settings_types.h`, a header that includes only `<cstdint>`, so pure
  logic no longer pulls in the Pico-SDK-coupled `Settings` class.
- `UserSettings` + the flash CRC/validation/migration — extracted into
  `src/logic/settings_storage.h` (includes only `<cstdint>`/`<cstring>`,
  `app_config.h`, `settings_types.h`). `Settings` (in `settings.cpp`) now delegates
  the byte-crunching to it and keeps only the flash I/O, debounce, and logging.

---

## Adding a suite

1. Create `test_<module>.cpp` including `<snitch/snitch.hpp>`.
2. Add it to the `add_executable(pd240w_tests ...)` list in `CMakeLists.txt`.
3. Reconfigure, build, and run.

If the module does not compile because a header pulls in `pico/*`, extract its
pure logic into a `logic/`-style header first (as with `settings_types.h`).

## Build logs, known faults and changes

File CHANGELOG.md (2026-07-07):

# Changelog

## [2.0.4] - 2026-07-07

### Bug Fixes

- Waking the screen from auto-dim now restores the saved brightness instead of a stale menu value, and the encoder turn or button press that wakes the screen no longer also changes a menu selection or toggles the output.
- A fault that changes type while already faulted (e.g. overcurrent then overtemperature) now redraws the screen instead of leaving the previous fault's details on display.
- INA228 die-temperature readings are sign-corrected, fixing a spurious over-temperature fault when the board is cold.
- Thermal status no longer sticks at FAULT after cooling back into an already-latched warning band.
- A TPS26750 EEPROM flash can no longer be abandoned mid-write by a fault or menu timeout, preventing a half-programmed EEPROM.
- The load switch now refuses to enable when the INA228 power monitor failed to initialize, instead of silently enabling an unmonitored output with no overcurrent protection.
- Buzzer pitch is now correct below ~120 Hz, and the alarm tone can no longer latch on indefinitely.
- Added I2C timeouts and a watchdog to prevent bus-hang lockups; PPS/AVS keep-alive now backs off after a failed request instead of hammering the bus every loop.
- Fixed assorted display and LED glitches: LED stuck yellow after a fault clears, mis-clamped minimum brightness, and unreachable PDO-list rows after a mid-selection contract refresh.

### CLI

- `MEAS:ENERGY?` now reports energy in mWh; added `MEAS:CHARGE?` for delivered charge in mAh.
- About-screen firmware version strings now show clean release tags.

### Internal

- Major testability refactor: extracted the pure logic (PD diagnostics, PPS/AVS tuning, constant-current regulation, settings flash codec, thermal FSM, EPR safe-exit sequencing) into host-testable headers with a Snitch/ASan/UBSan unit-test suite, CI, and a 90% coverage floor.
- CI now builds our sources with `-Werror` so warning regressions fail the PR; deduplicated PPS/AVS keep-alive and PDO handling.

## [2.0.3] - 2026-07-04

### Features

- PPS voltage range now goes as low as 3.3V, matching the full USB-PD PPS spec.

### Improvements

- TPS26750 PD configuration is now pushed over I2C at boot instead of requiring an EEPROM flash, and flash size is configurable instead of hardcoded to 2MB.
- Bumped the shared TPS26750 driver, fixing Max Power showing 0W for non-PD chargers and other small bugs (brightness CLI, buzzer melody latch).
- Lowered the PD disconnect VBUS threshold to 3.3V.

### Internal

- Code-review cleanup pass (warnings, dead code, deduplication) and SDK bump to 2.3.0.

## [2.0.2] - 2026-06-25

### Internal

- Migrated the TPS26750 USB-PD driver to the shared `tps26750_multiplatform` submodule, replacing the in-tree driver.

### UI Improvements

- Added a TPS firmware version line to the About PD240W screen and tightened its spacing so the layout sits clear of the bottom navigation hint.

## [2.0.1] - 2026-06-16

### UI Improvements

- Voltage select menu now fits up to 10 contracts on screen (was 8) and sits closer to the header, reducing scrolling on chargers with many contracts.

## [2.0.0] - 2026-05-31

### USB-PD 3.1 / 3.2 Release

- Added USB-PD 3.1 and 3.2 firmware support, making AVS and EPR negotiation possible.
- Added completed constant-current control work, including an OFF current-limit mode and updated INA228 integration.
- Improved USB-PD behavior across Fixed, PPS, and EPR AVS profiles with closed-loop tuning, safer contract transitions, smarter startup restore, and better high-voltage charger handling.
- Added charger diagnostics and a USB serial CLI for remote inspection and control.
- Refreshed the interface with PD240W branding, smoother visuals, clearer about screens, richer boot information, and more configurable settings such as auto-dim control.
- Fixed reboot voltage spikes, badge and cursor restore issues, noisy logs, menu navigation edge cases, charger-change restore problems, and several AVS/EPR negotiation regressions.

## [1.0.0]

- Initial public firmware release.

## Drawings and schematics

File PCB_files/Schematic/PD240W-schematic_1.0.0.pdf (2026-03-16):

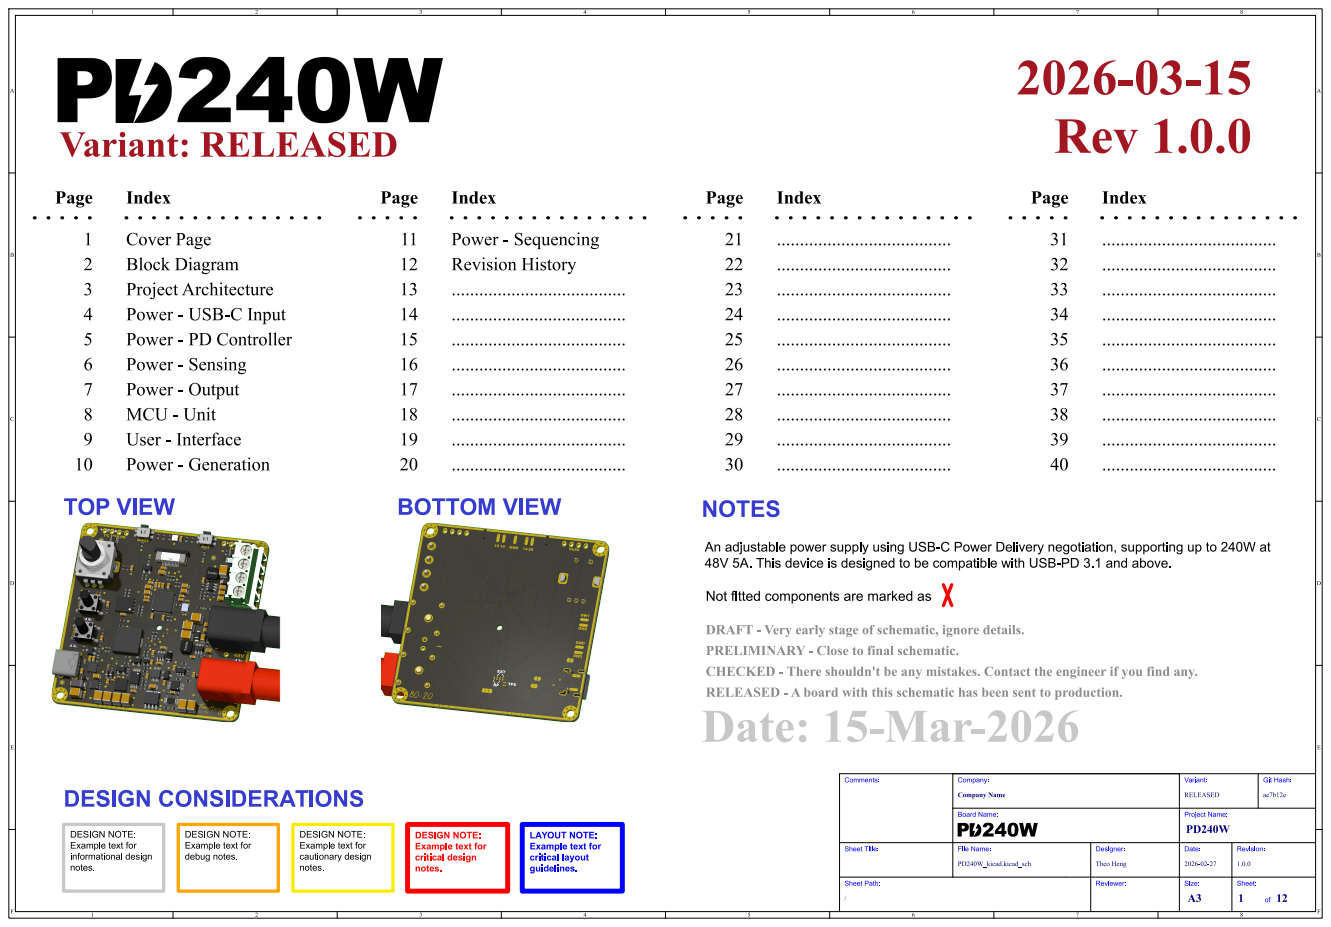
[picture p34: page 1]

...................................... CHECKED - Thereshouldn'tbeanymistakes.Contacttheengineerif youfindany.

Not fitted components are marked as

DRAFT - Veryearlystageof schematic,ignoredetails.
PRELIMINARY - Closetofinal schematic.
Date:15-Mar-2026

Revision: 1.0.0 Date: Project Name: 2026-02-27 Reviewer: Designer:

File: Project Architecture.kicad_sch DESIGN NOTE:
Example text for
debug notes.

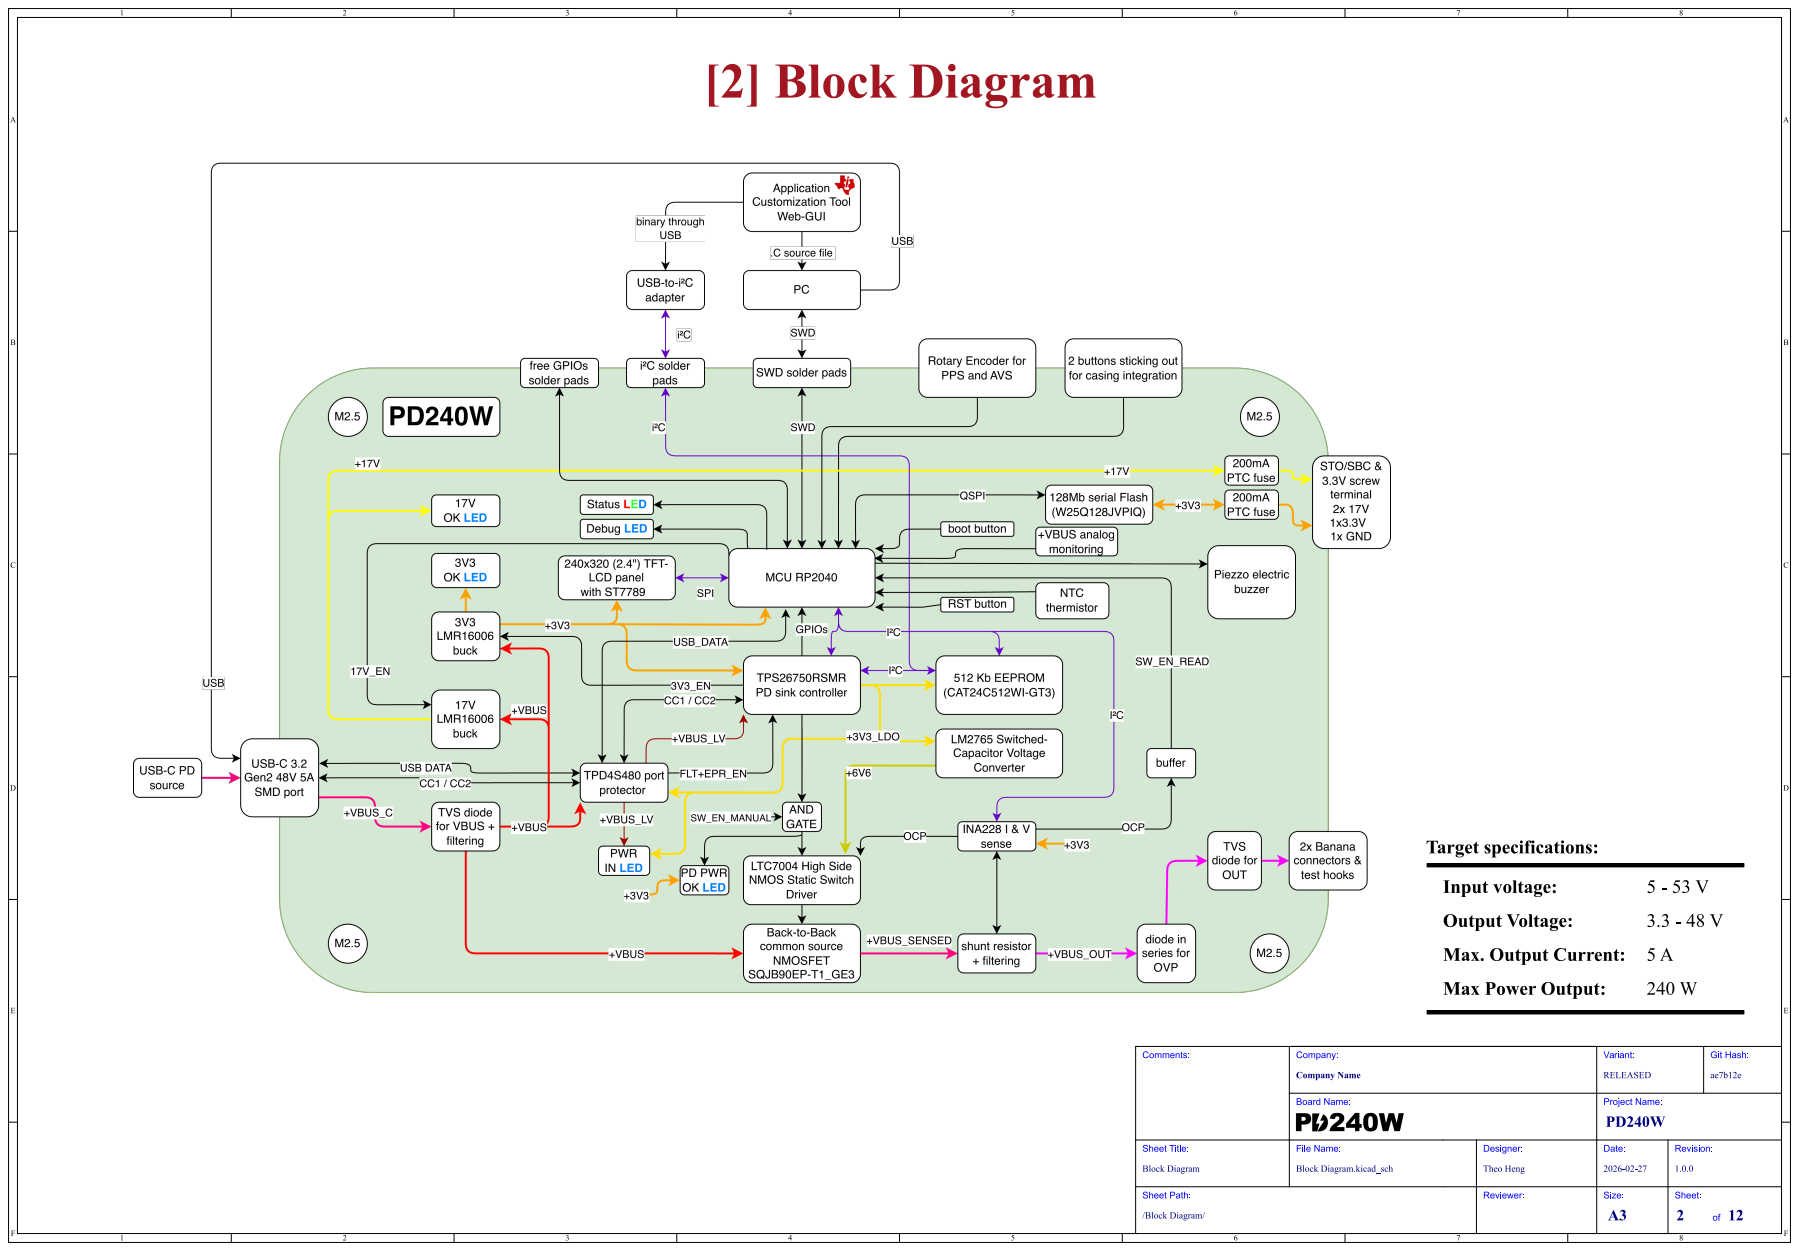
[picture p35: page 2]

/Block Diagram/ Sheet Path: Block Diagram

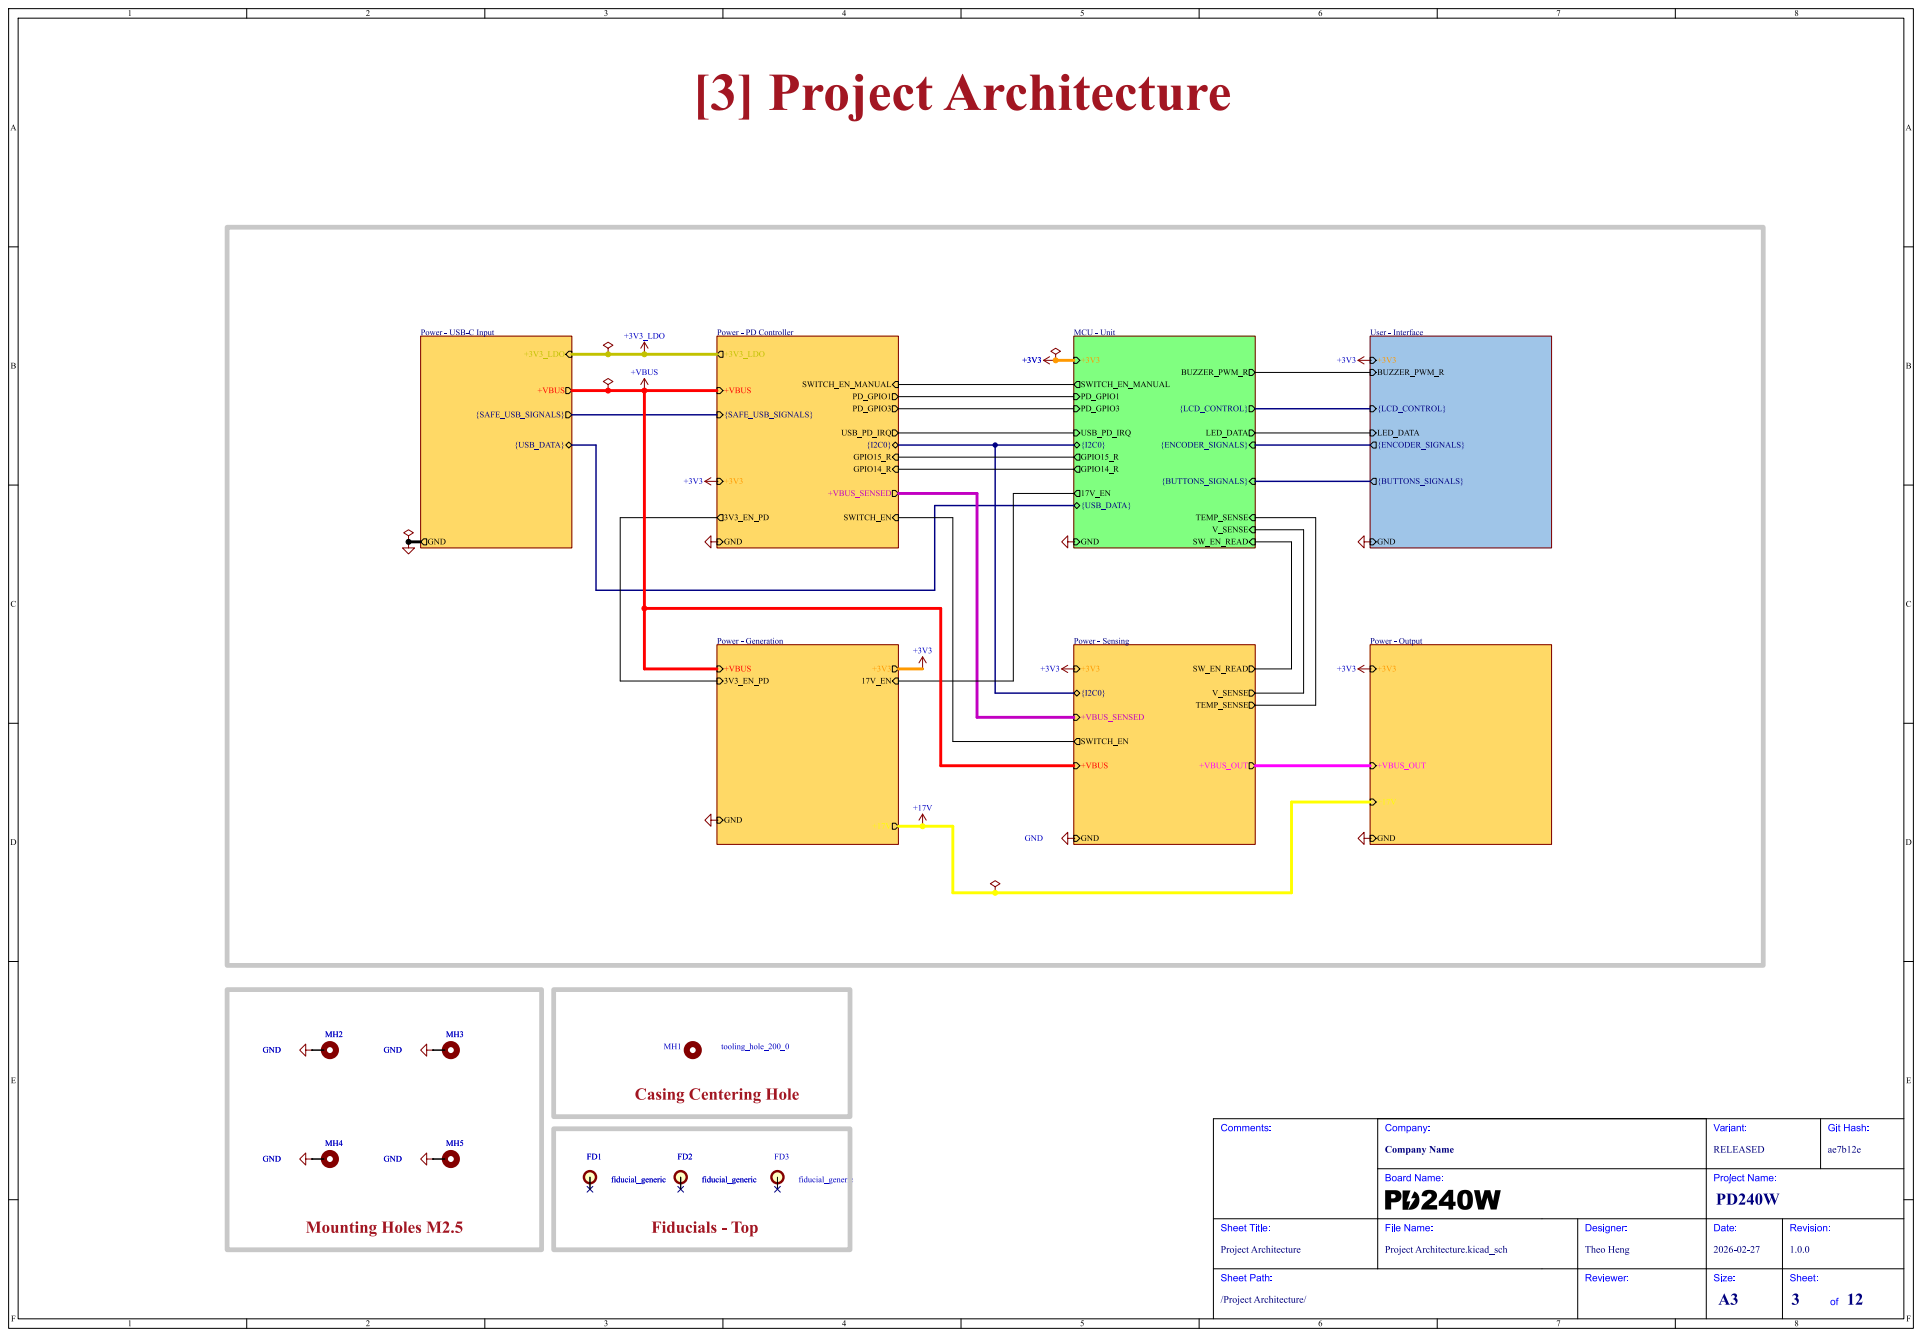
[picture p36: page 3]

Revision: 1.0.0 Date: Project Name: 2026-02-27 Reviewer: Designer:

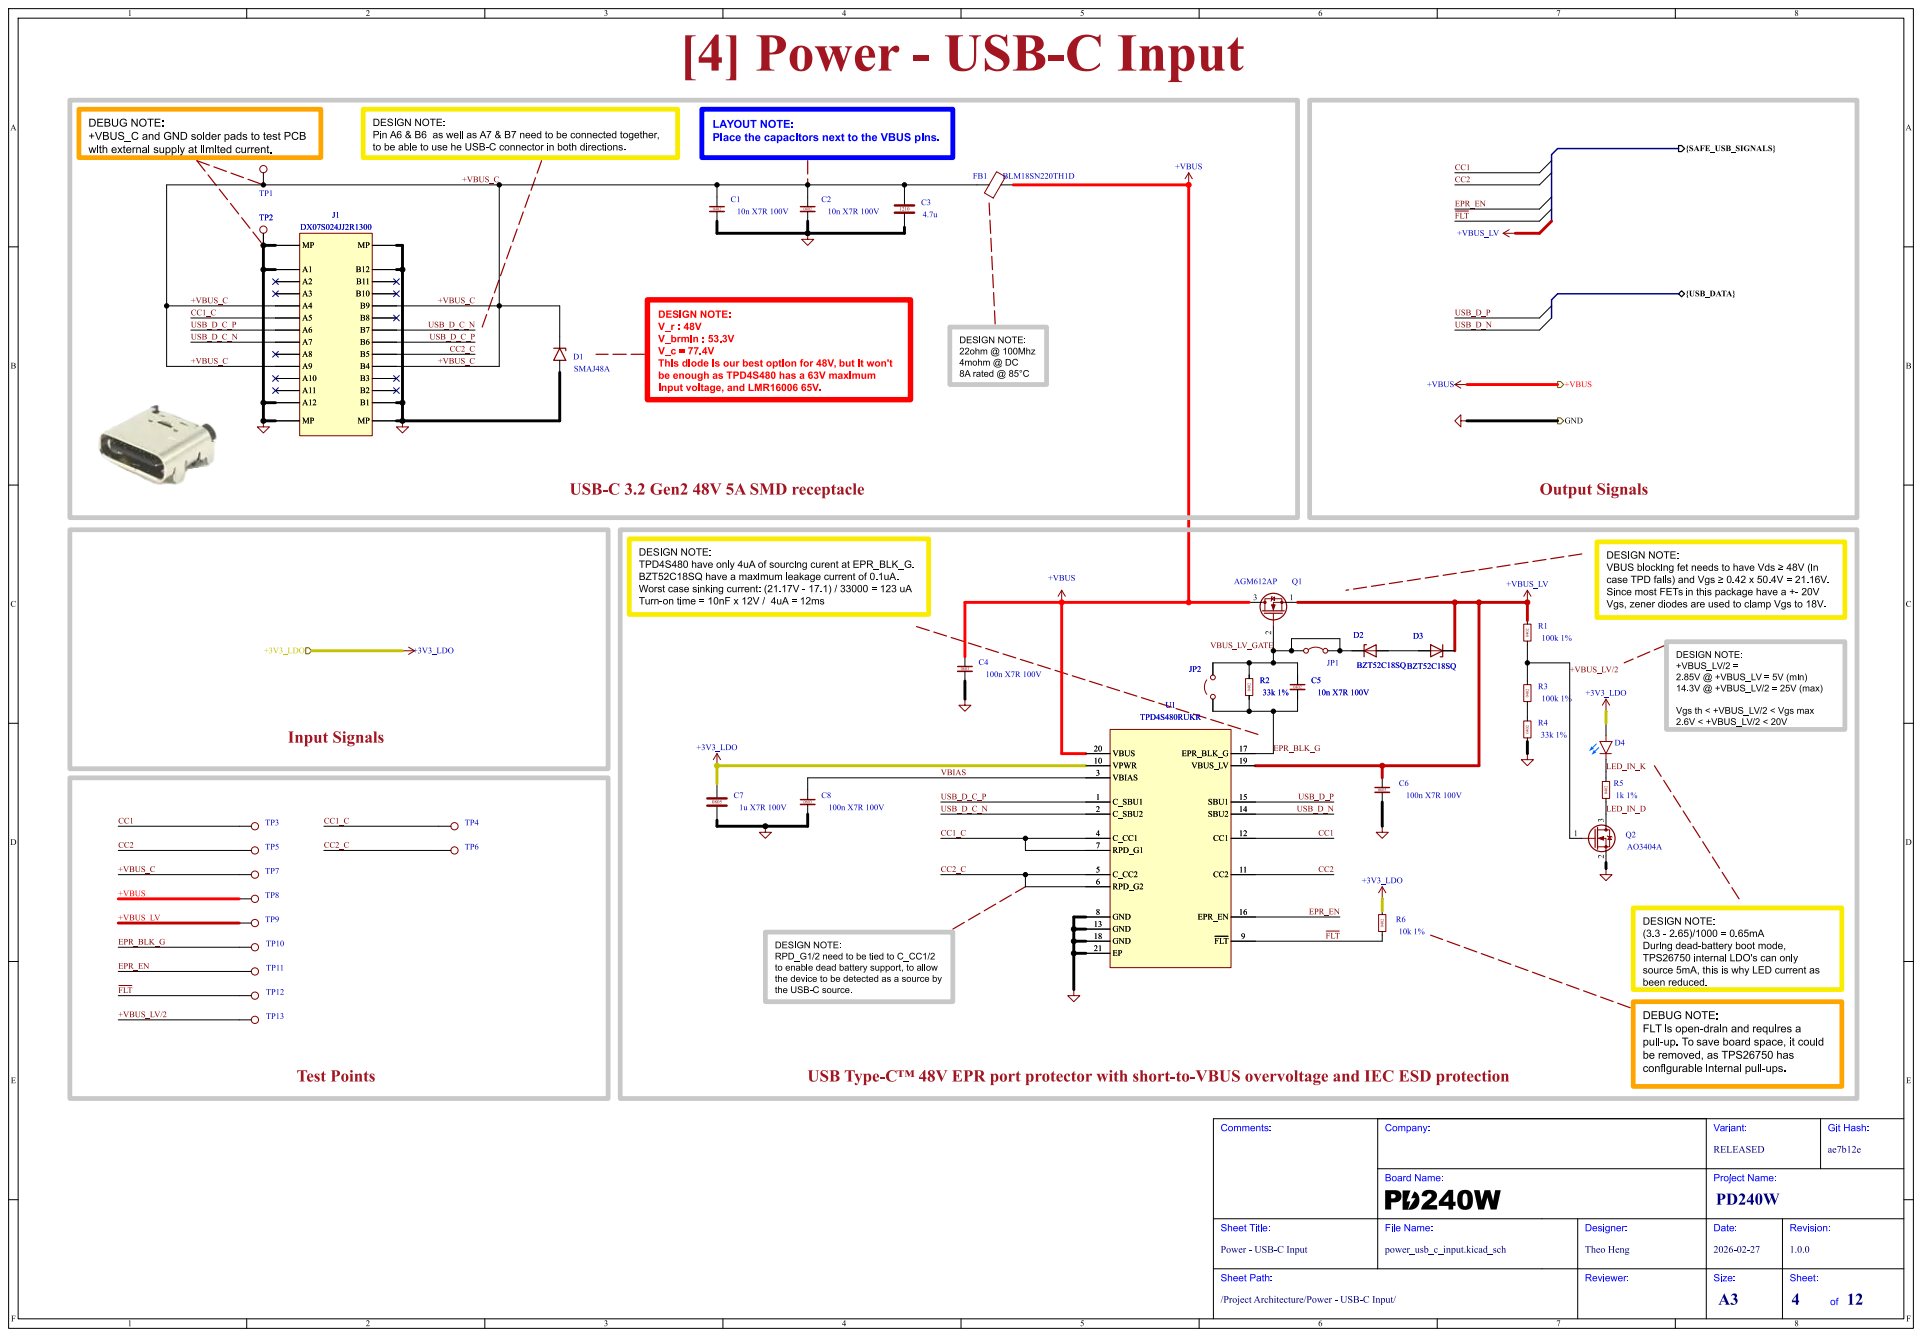
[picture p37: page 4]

DEBUG NOTE:
+VBUS_C and GND solder pads to test PCB
with external supply at limited current.

DESIGN NOTE: Pin A6 & B6 as well as A7 & B7 need to be connected together,

LAYOUT NOTE:
Place the capacitors next to the VBUS pins.

V_brmin : 53.3V
This diode is our best option for 48V, but it won't be enough as TPD4S480 has a 63V maximum

DESIGN NOTE:
VBUS blocking fet needs to have Vds þÿ"e48V (in
case TPD fails) and Vgs þÿ"e0.42 x 50.4V = 21.16V. Since most FETs in this package have a +- 20V

TPD4S480 have only 4uA of sourcing curent at EPR_BLK_G.
BZT52C18SQ have a maximum leakage current of 0.1uA. Worst case sinking current: (21.17V - 17.1) / 33000 = 123 uA

Turn-on time = 10nF x 12V / 4uA = 12ms DESIGN NOTE: RPD_G1/2 need to be tied to C_CC1/2

Vgs th < +VBUS_LV/2 < Vgs max 2.6V < +VBUS_LV/2 < 20V

(3.3 - 2.65)/1000 = 0.65mA During dead-battery boot mode,

TPS26750 internal LDO's can only
source 5mA, this is why LED current as been reduced.

to enable dead battery support, to allow
the device to be detected as a source by
the USB-C source.

FLT is open-drain and requires a
pull-up. To save board space, it could
be removed, as TPS26750 has
configurable internal pull-ups.

USBþÿType-C!" 48V EPR portprotectorwithshort-to-VBUSovervoltageandIEC ESD protection

Revision: 1.0.0 Date: Project Name: 2026-02-27 Reviewer: Designer:

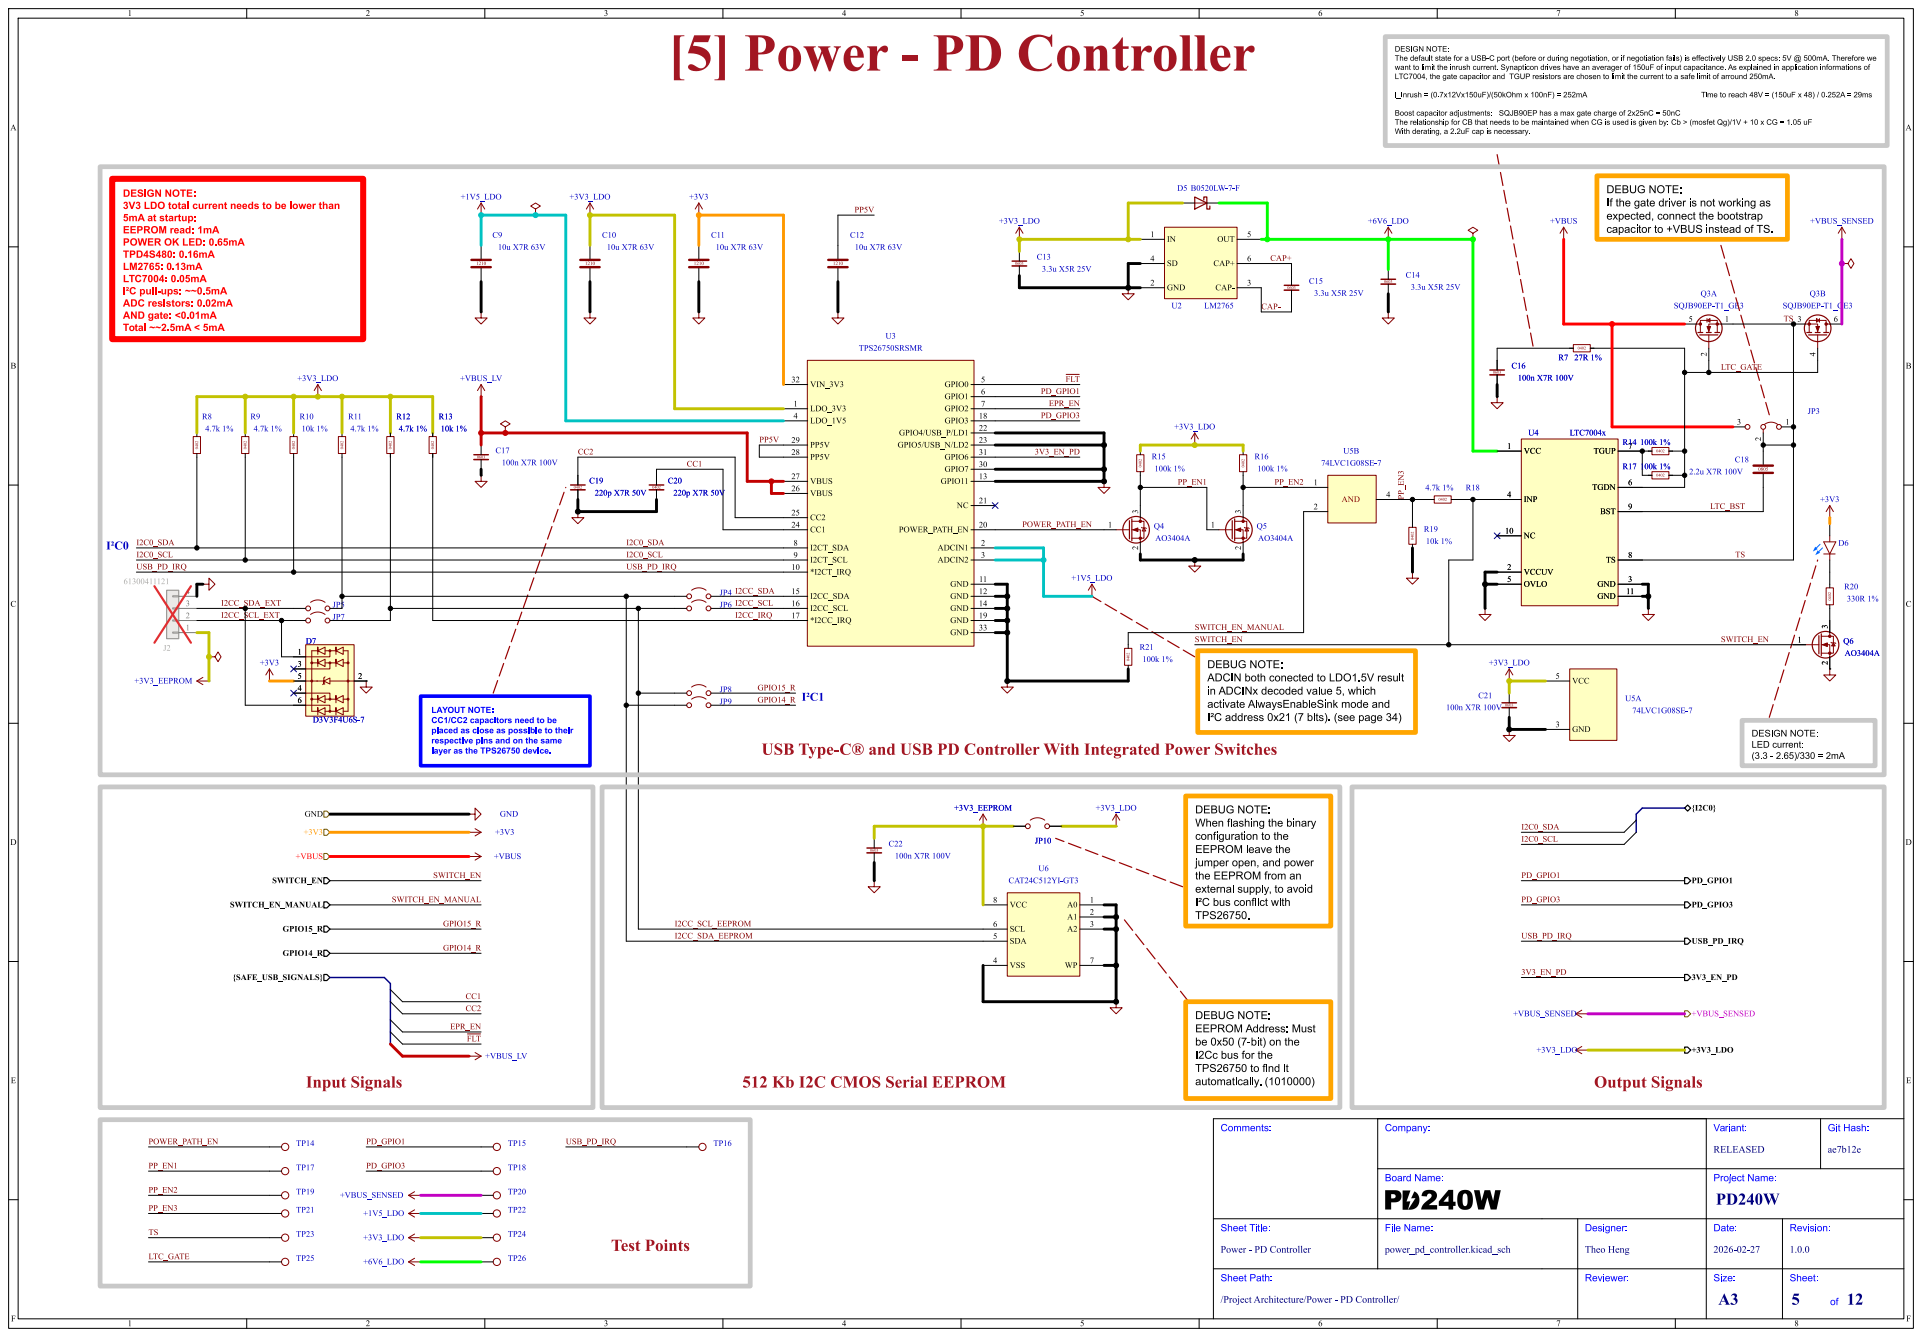
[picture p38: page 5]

The relationship for CB that needs to be maintained when CG is used is given by: Cb > (mosfet Qg)/1V + 10 x CG = 1.05 uF With derating, a 2.2uF cap is necessary. [5] Power- PD Controller

DESIGN NOTE: The default state for a USB-C port (before or during negotiation, or if negotiation fails) is effectively USB 2.0 specs: 5V @ 500mA. Therefore we want to limit the inrush current. Synapticon drives have an averager of 150uF of input capacitance. As explained in application informations of LTC7004, the gate capacitor and TGUP resistors are chosen to limit the current to a safe limit of arround 250mA.
capacitor to +VBUS instead of TS. DESIGN NOTE: LED current: (3.3 - 2.65)/330 = 2mA

DESIGN NOTE: 3V3 LDO total current needs to be lower than

If the gate driver is not working as expected, connect the bootstrap

5mA at startup: EEPROM read: 1mA

DEBUG NOTE:
ADCIN both conected to LDO1.5V result
in ADCINx decoded value 5, which
activate AlwaysEnableSink mode and

þÿI²C address 0x21 (7 bits). (see page 34) LAYOUT NOTE: CC1/CC2 capacitors need to be placed as close as possible to their

respective pins and on the same

USBþÿType-C® andUSBPD ControllerWith IntegratedPowerSwitches

When flashing the binary
configuration to the
EEPROM leave the
jumper open, and power
the EEPROM from an
external supply, to avoid
þÿI²C bus conflict with
TPS26750.

EEPROM Address: Must
be 0x50 (7-bit) on the
I2Cc bus for the
TPS26750 to find it
automatically. (1010000)

Revision: 1.0.0 Date: Project Name: 2026-02-27 Reviewer: Designer:

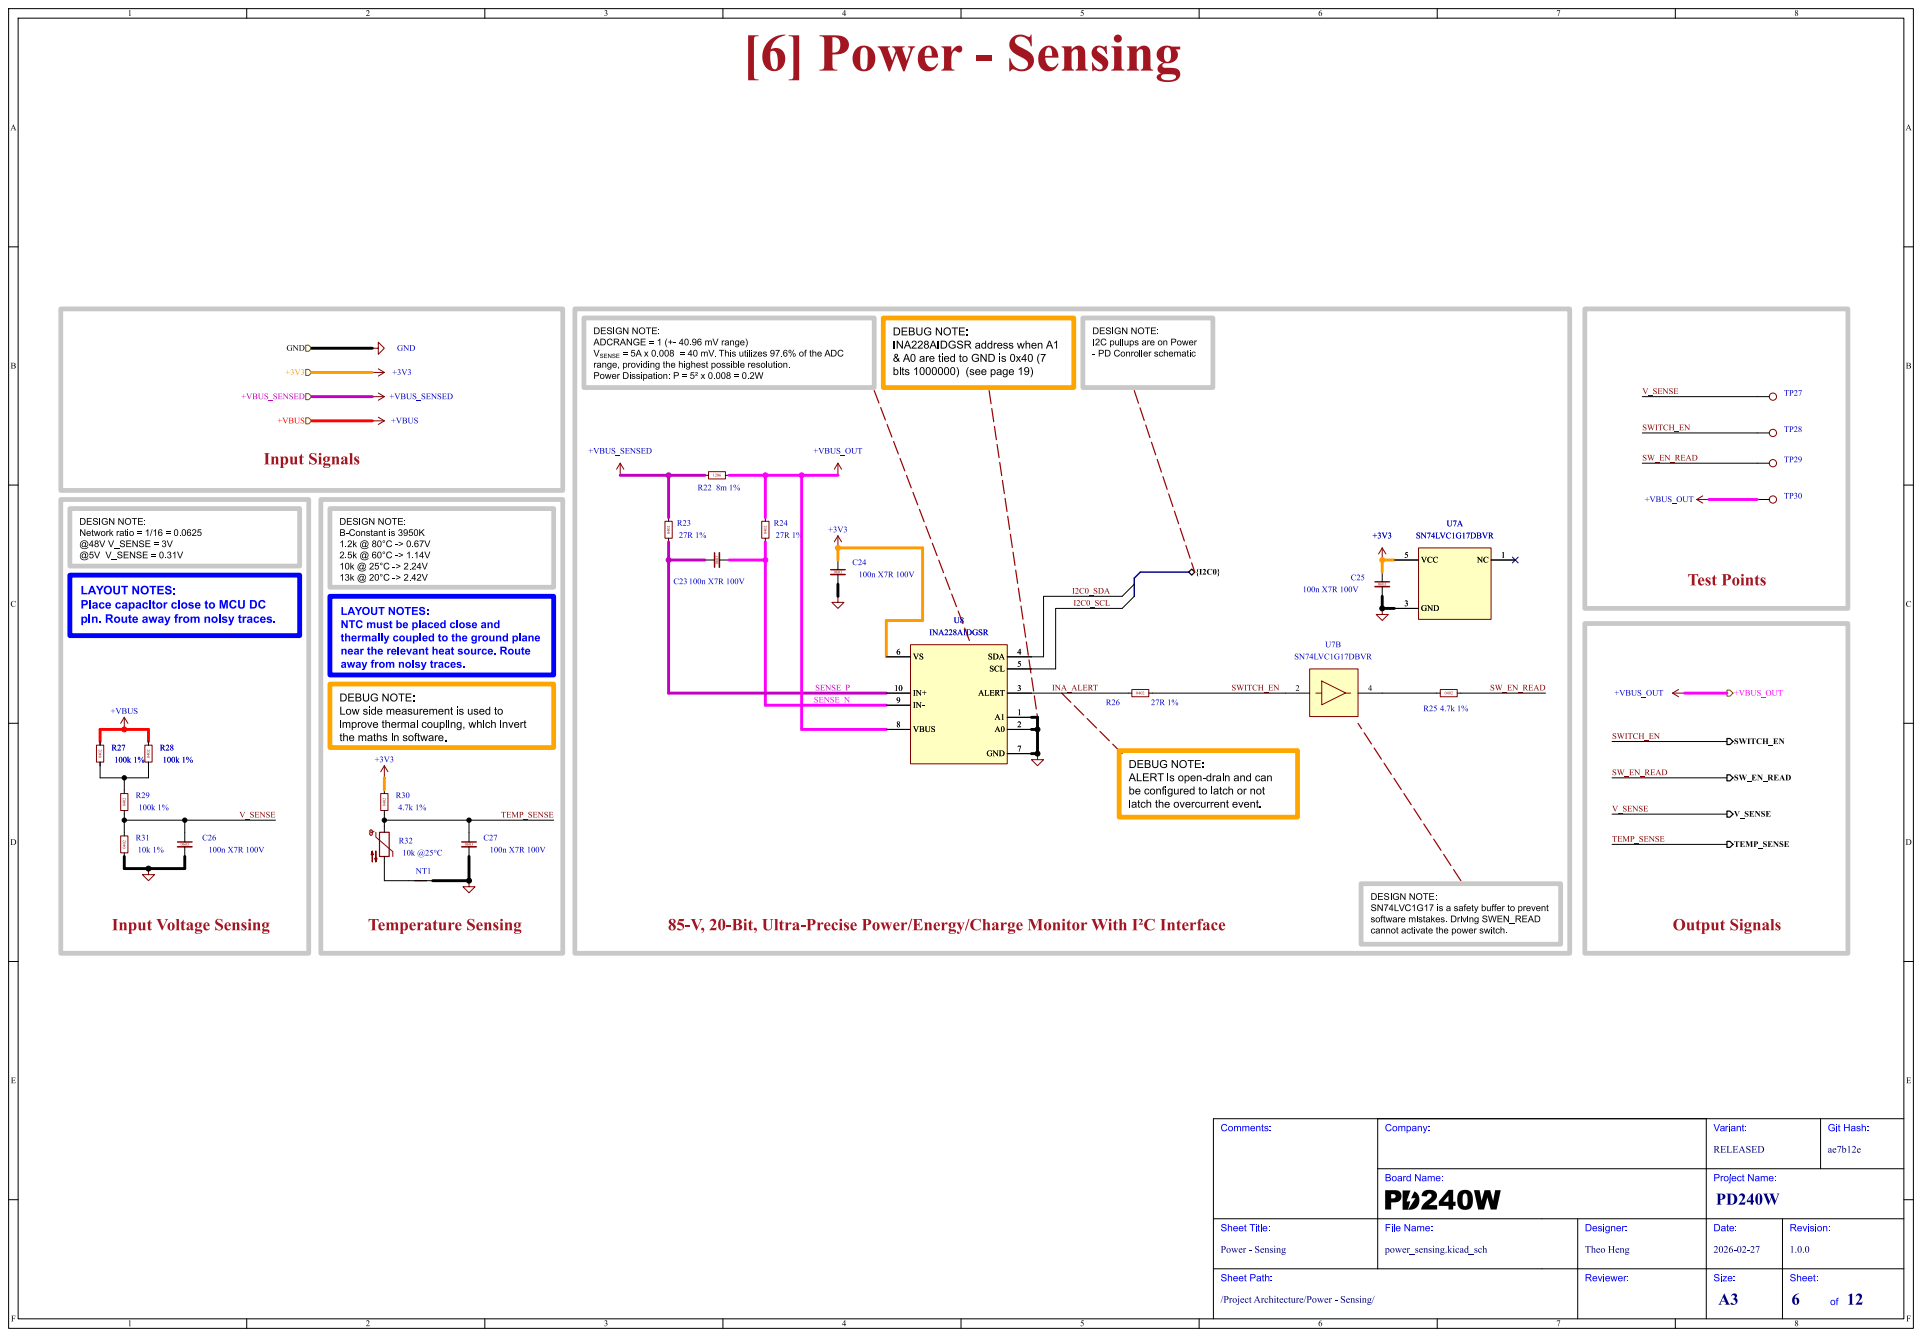
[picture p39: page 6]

- PD Conroller schematic [6] Power- Sensing

DESIGN NOTE: ADCRANGE = 1 (+- 40.96 mV range)

latch the overcurrent event. DEBUG NOTE:
INA228AIDGSR address when A1
& A0 are tied to GND is 0x40 (7

I2C pullups are on Power

V_{SENSE} = 5A x 0.008 = 40 mV. This utilizes 97.6% of the ADC
range, providing the highest possible resolution. Power Dissipation: P = þÿ5² x 0.008 = 0.2W

TEMP_SENSE DESIGN NOTE: B-Constant is 3950K

13k @ þÿ20°C -> 2.42V LAYOUT NOTES:
Place capacitor close to MCU DC

LAYOUT NOTES:
NTC must be placed close and
thermally coupled to the ground plane near the relevant heat source. Route

cannot activate the power switch. DEBUG NOTE:
Low side measurement is used to
improve thermal coupling, which invert
the maths in software.

ALERT is open-drain and can
be configured to latch or not

85-V,20-Bit,Ultra-PrecisePower/Energy/ChargeMonitorWith þÿI²C Interface

Revision: 1.0.0 Date: Project Name: 2026-02-27 Reviewer: Designer:

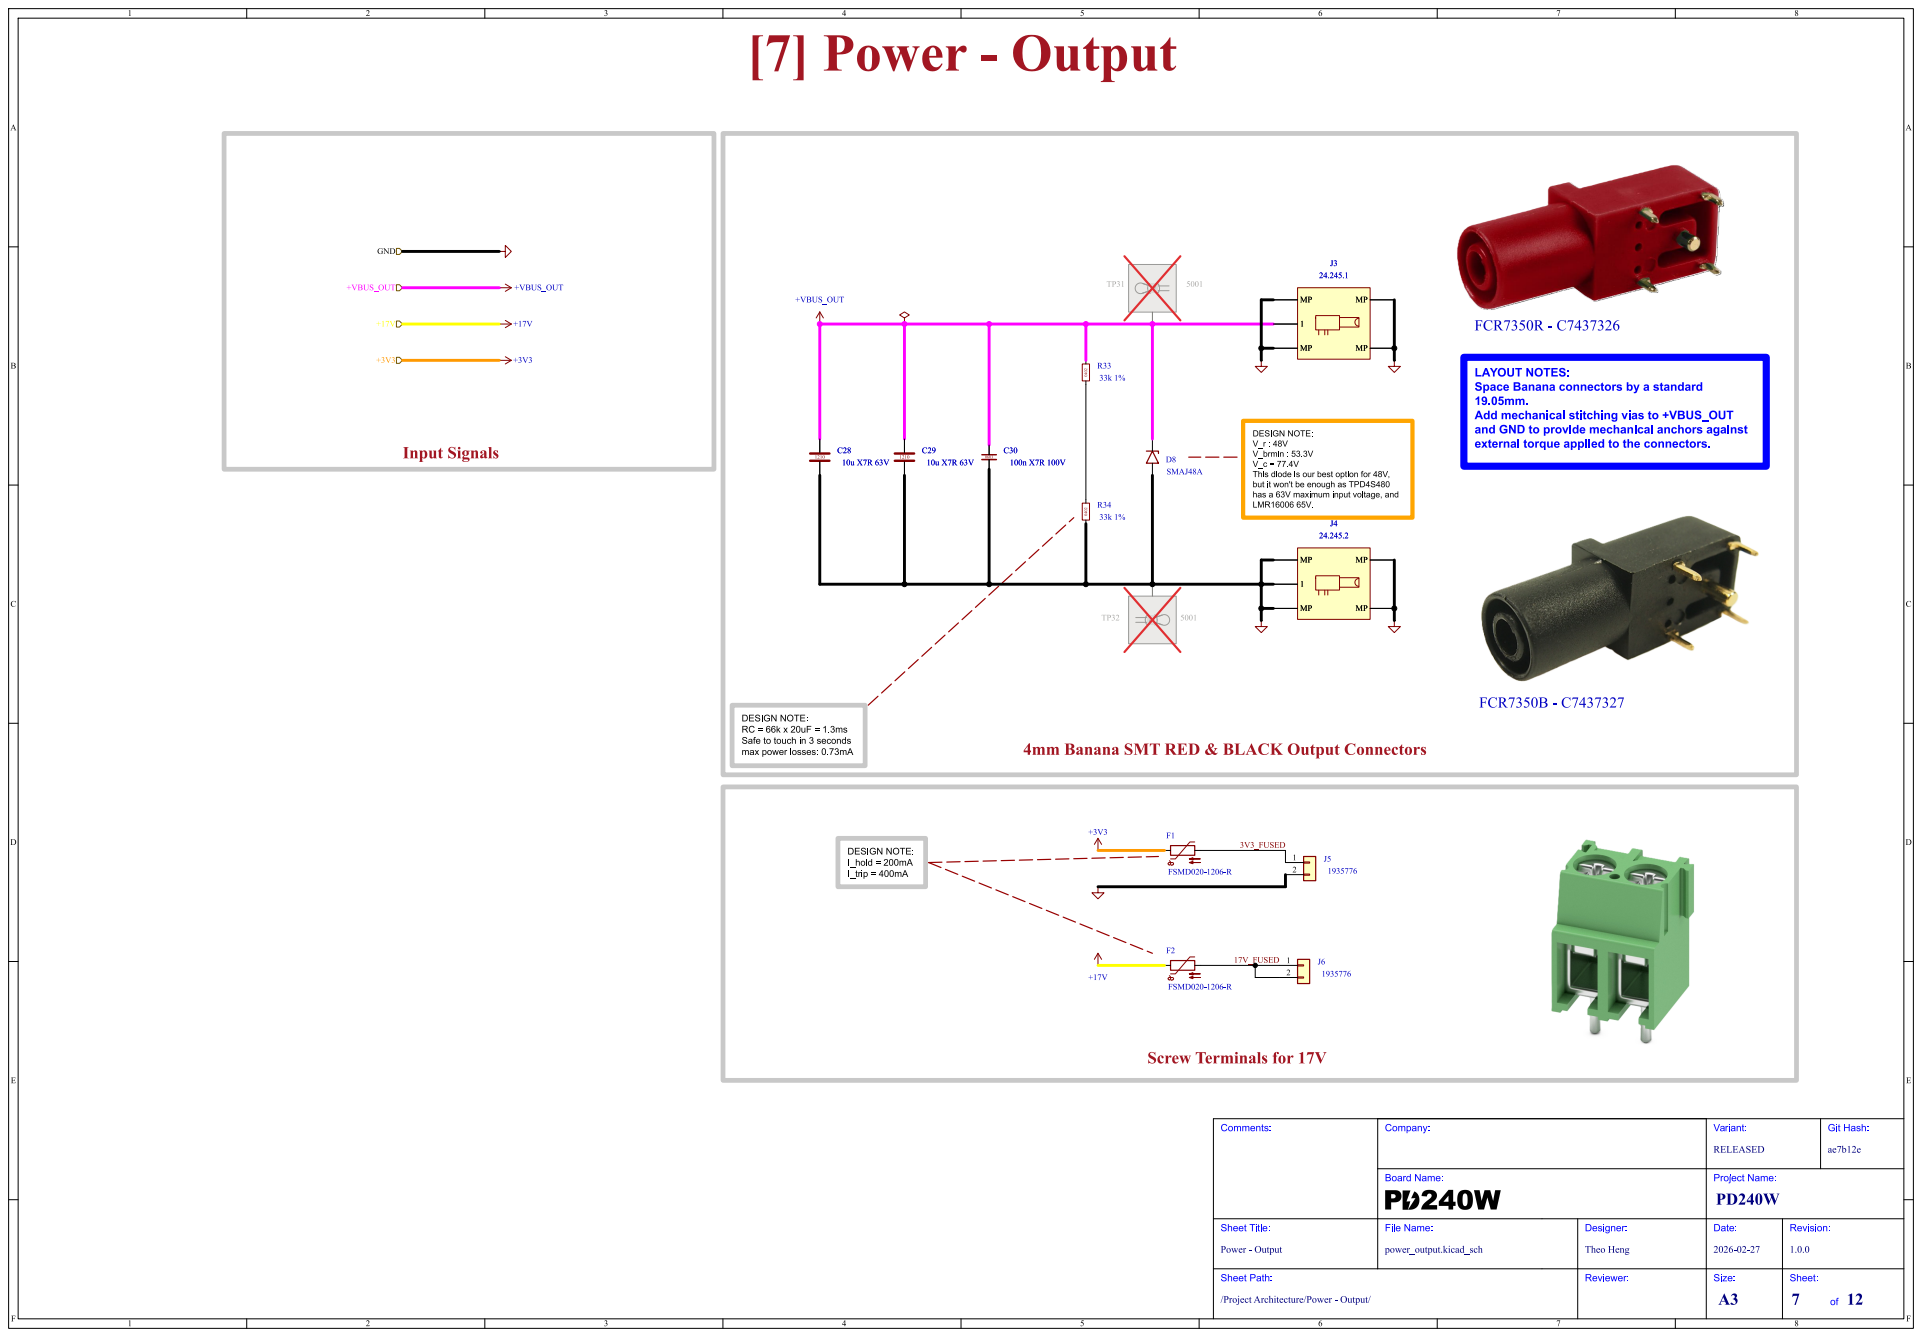
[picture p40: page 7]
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

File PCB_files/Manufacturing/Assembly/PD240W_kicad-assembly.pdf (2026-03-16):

# PD240W Assembly Document

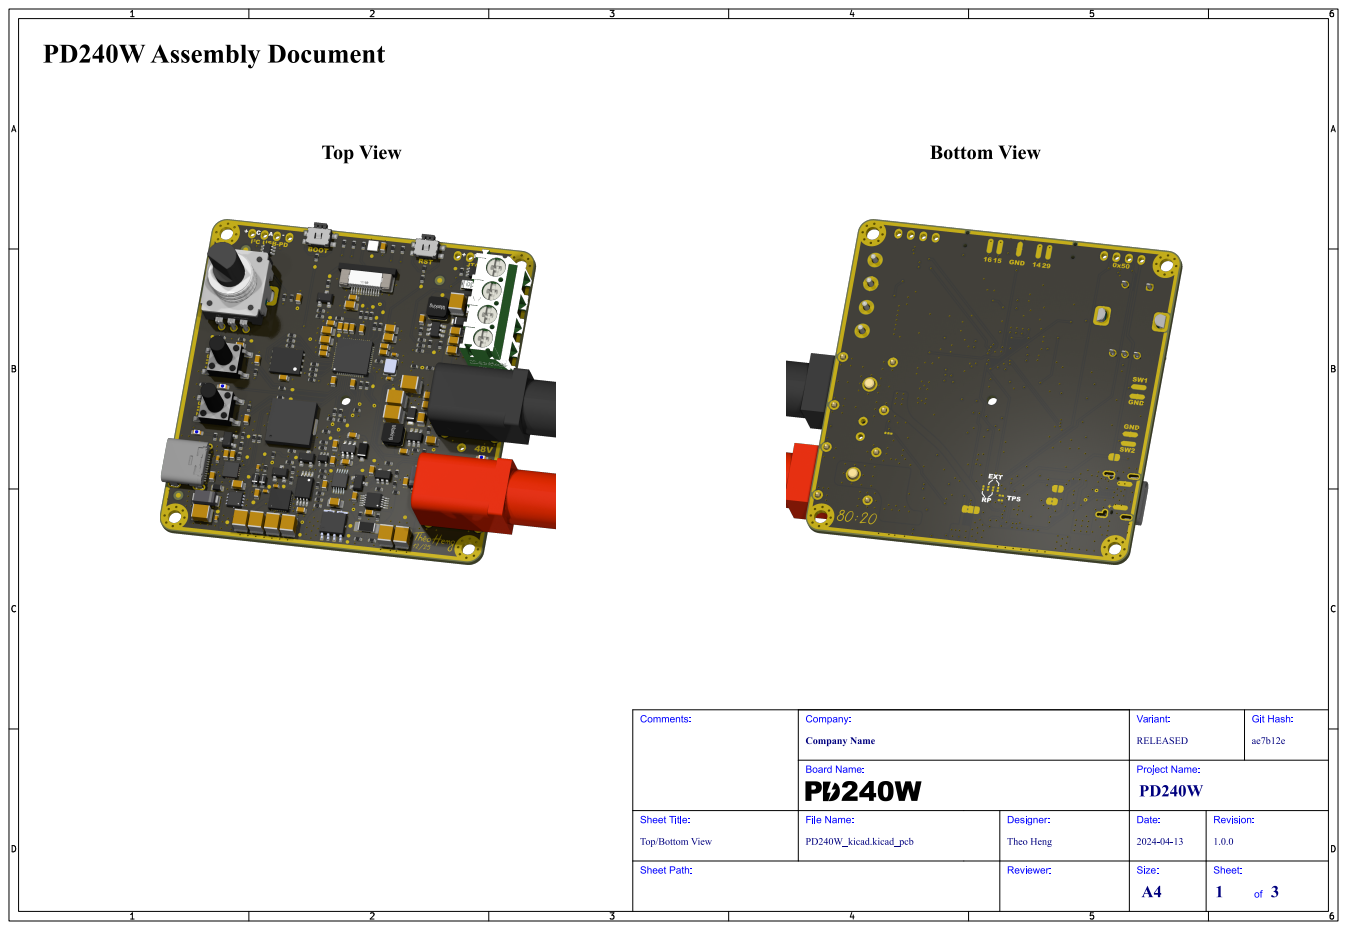
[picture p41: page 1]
Git; Hash:; Comments:; Sheet Path:; Sheet Title:; File Name:; Company Name; Company:; RELEASED; Variant:; Board Name:; PD240W_kicad.kicad_pcb; Theo Heng; Designer:; Reviewer:; Project Name:; Date:; Revision:; Size:; Sheet:

Top/Bottom View

# Top Assembly (Scale 1:1)

# PD240W Assembly Document

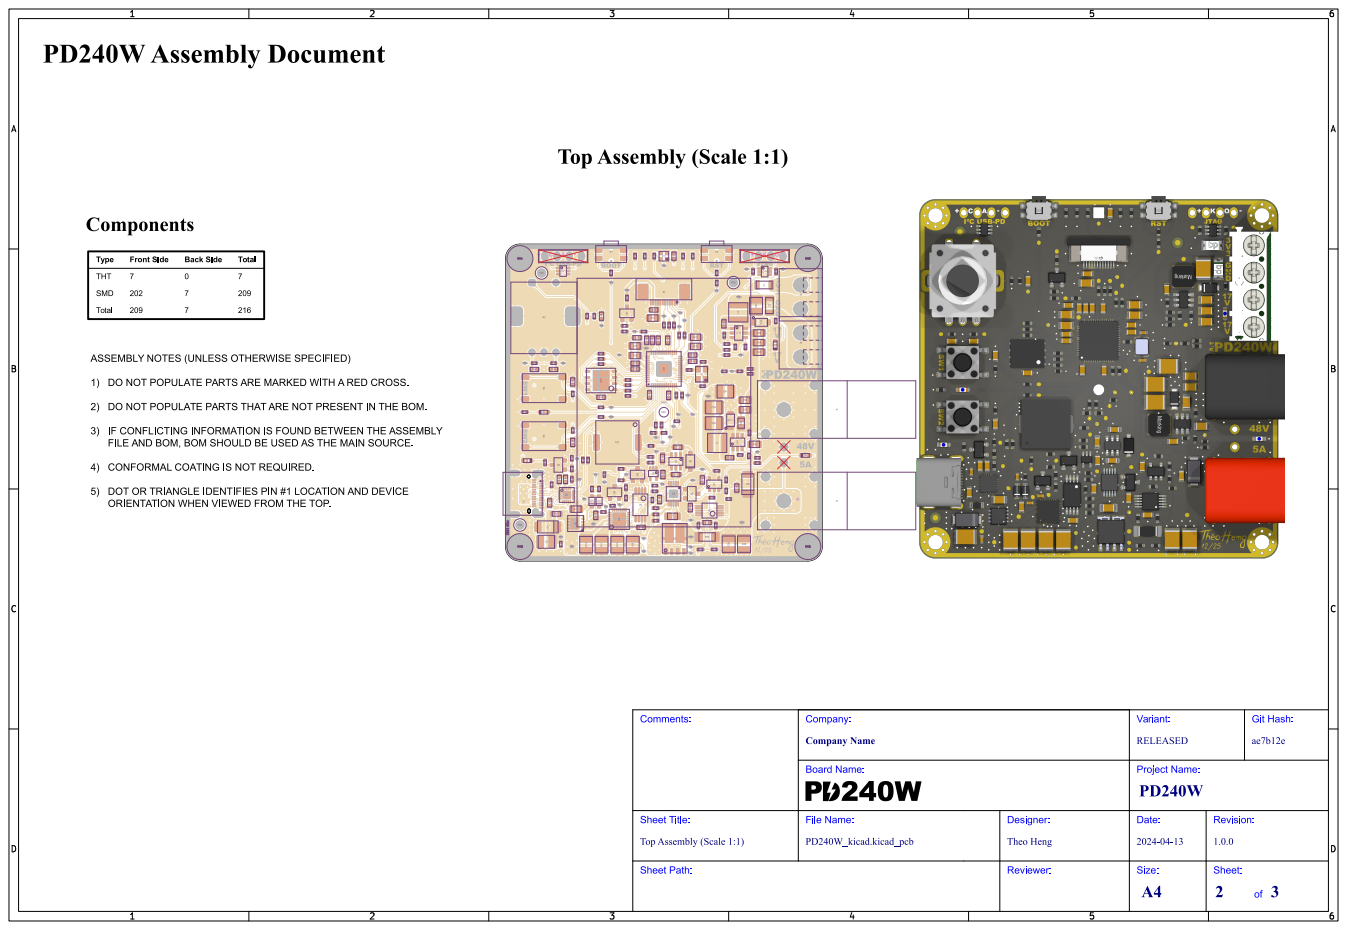
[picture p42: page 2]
Git Hash:; Comments:; Sheet Path:; Sheet Title:; File Name:; Company Name; Company:; RELEASED; Variant:; Board Name:; PD240W_kicad.kicad_pcb; Theo Heng; Designer:; Reviewer:; Project Name:; Date:; Revision:; Size:; Sheet:; PCB EDGE

Top Assembly (Scale 1:1)

# Bottom Assembly (Scale 1:1)

# PD240W Assembly Document

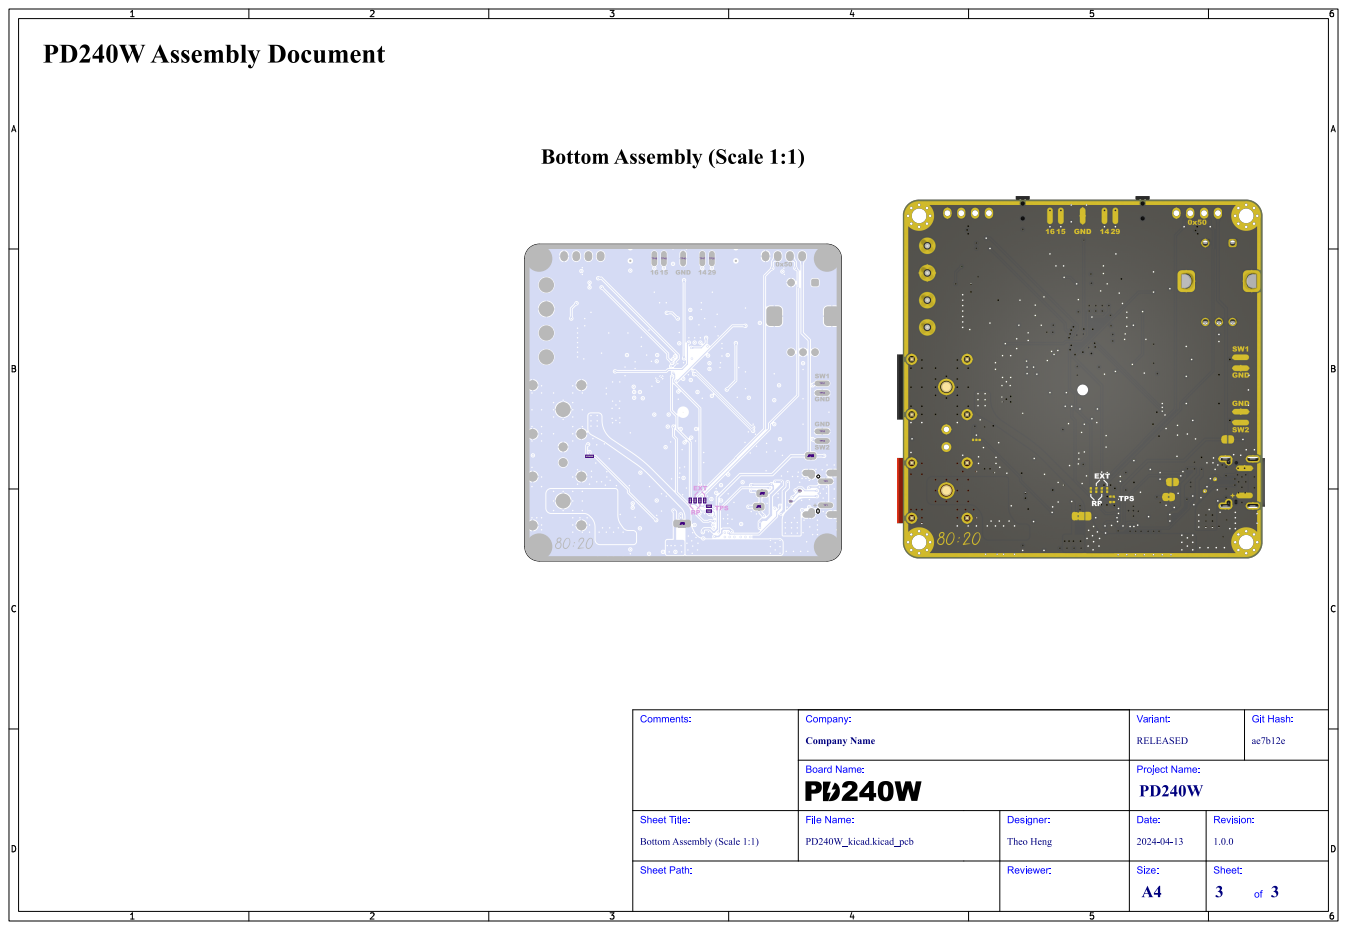
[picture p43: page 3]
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

Bottom Assembly (Scale 1:1)

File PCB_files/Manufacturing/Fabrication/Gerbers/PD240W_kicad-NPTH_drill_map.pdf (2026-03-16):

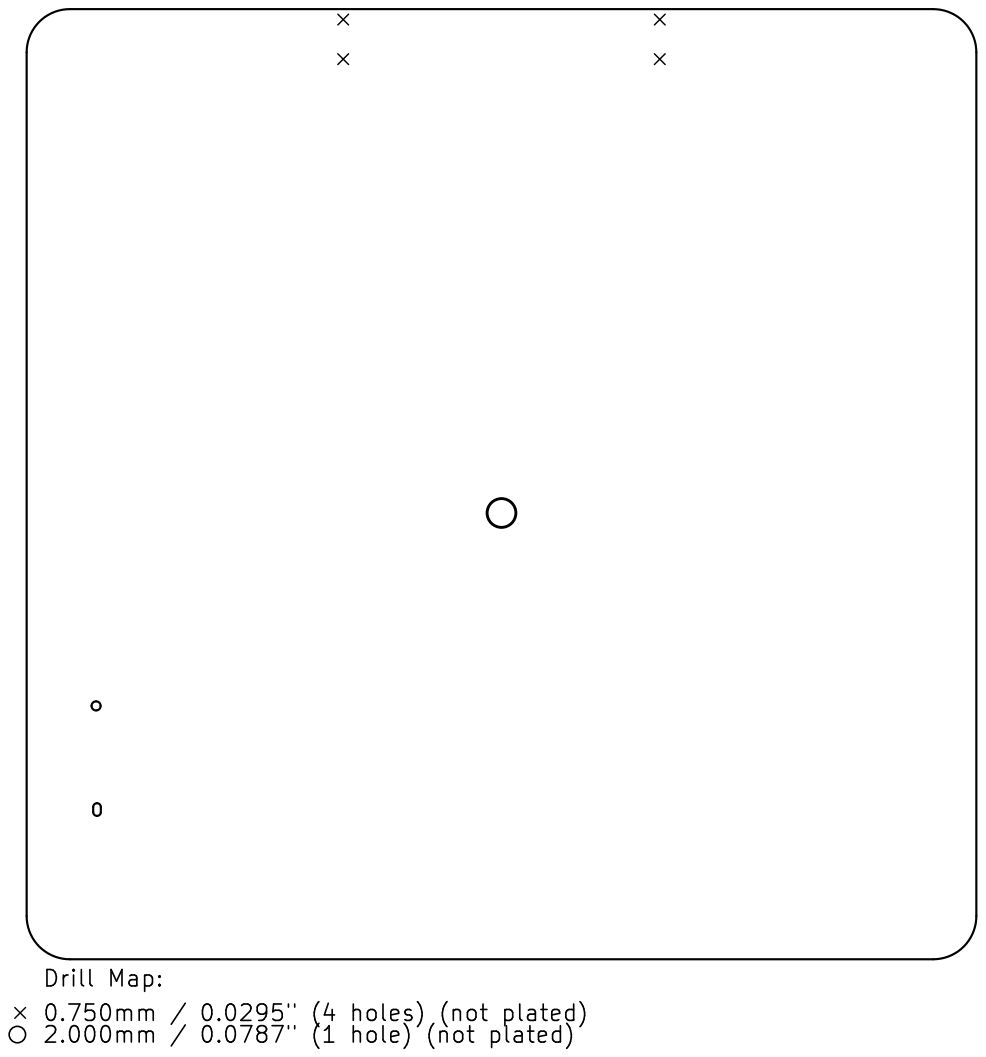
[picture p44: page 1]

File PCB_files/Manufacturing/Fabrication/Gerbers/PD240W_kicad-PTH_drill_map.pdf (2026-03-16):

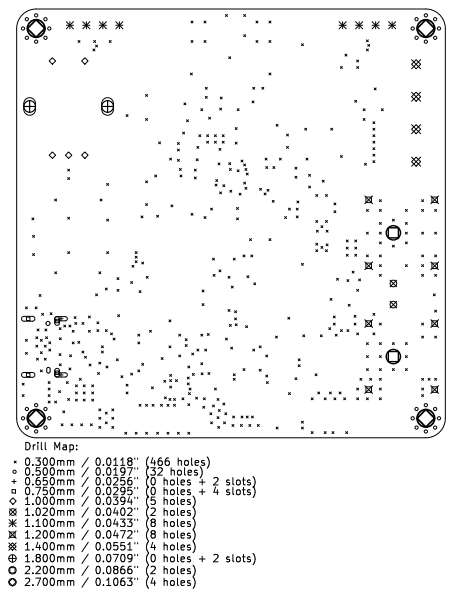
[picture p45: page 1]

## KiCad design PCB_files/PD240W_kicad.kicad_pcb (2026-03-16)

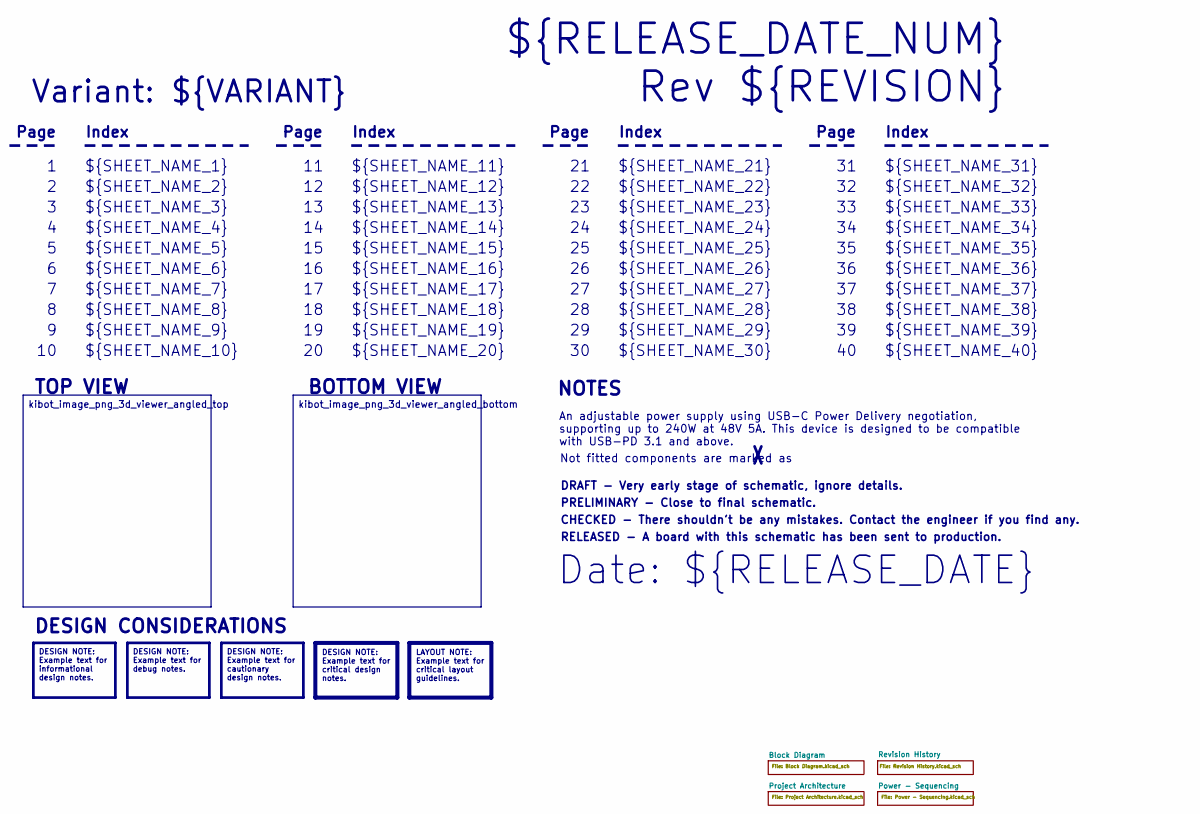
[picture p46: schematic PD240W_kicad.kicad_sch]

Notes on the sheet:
Variant: ${VARIANT}
RELEASED - A board with this schematic has been sent to production.
${SHEET_NAME_24}
Index
Page
PRELIMINARY - Close to final schematic.
${SHEET_NAME_22}
DRAFT - Very early stage of schematic, ignore details.
${SHEET_NAME_12}
${SHEET_NAME_8}
${SHEET_NAME_2}
${SHEET_NAME_5}
${SHEET_NAME_20}
${SHEET_NAME_23}
${RELEASE_DATE_NUM}
${SHEET_NAME_35}
Not fitted components are marked as
${SHEET_NAME_11}
${SHEET_NAME_6}
${SHEET_NAME_37}
${SHEET_NAME_26}
${SHEET_NAME_36}
Rev ${REVISION}
${SHEET_NAME_15}
CHECKED - There shouldn't be any mistakes. Contact the engineer if you find any.
BOTTOM VIEW
${SHEET_NAME_14}
${SHEET_NAME_21}
${SHEET_NAME_17}
${SHEET_NAME_18}
Date: ${RELEASE_DATE}
${SHEET_NAME_7}
${SHEET_NAME_31}
NOTES
${SHEET_NAME_40}
${SHEET_NAME_39}
${SHEET_NAME_32}
${SHEET_NAME_1}
${SHEET_NAME_9}
${SHEET_NAME_38}

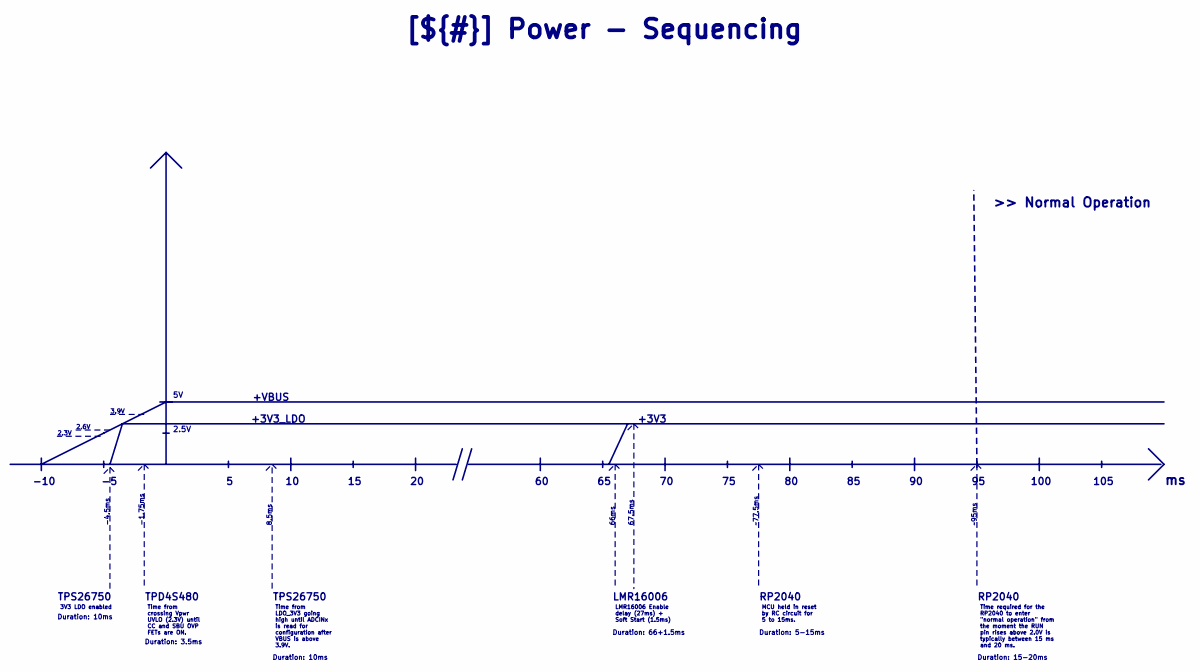
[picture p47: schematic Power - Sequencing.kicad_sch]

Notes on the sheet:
~95ms
-1.75ms
2.5V
3.9V
Duration: 15-20ms
RP2040
TPS26750
LMR16006
2.6V
+VBUS
Duration: 10ms
100
Duration: 3.5ms
Duration: 66+1.5ms
8.5ms
+3V3_LDO
66ms
67.5ms
Duration: 5-15ms
2.3V
105
~77.5ms
TPD4S480
+3V3
>> Normal Operation
-4.5ms
-10
3V3 LDO enabled
Time from LDO_3V3 going high until ADCINx is read for configuration after VBUS is above 3.9V.
Time from crossing Vpwr UVLO (2.3V) until CC and SBU OVP FETs are ON.
Time required for the RP2040 to enter "normal operation" from the moment the RUN pin rises above 2.0V is typically between 15 ms and 20 ms.
[${#}] ${TITLE}
MCU held in reset by RC circuit for 5 to 15ms.
LMR16006 Enable delay (27ms) + Soft Start (1.5ms)


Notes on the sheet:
${RELEASE_BODY_1.1.0}
[${#}] ${TITLE}
${RELEASE_BODY_1.0.0}
${RELEASE_TITLE_1.0.2}
${RELEASE_BODY_1.0.2}
${RELEASE_BODY_1.0.1}
${RELEASE_TITLE_1.0.0}
${RELEASE_TITLE_1.0.1}
${RELEASE_TITLE_1.1.0}

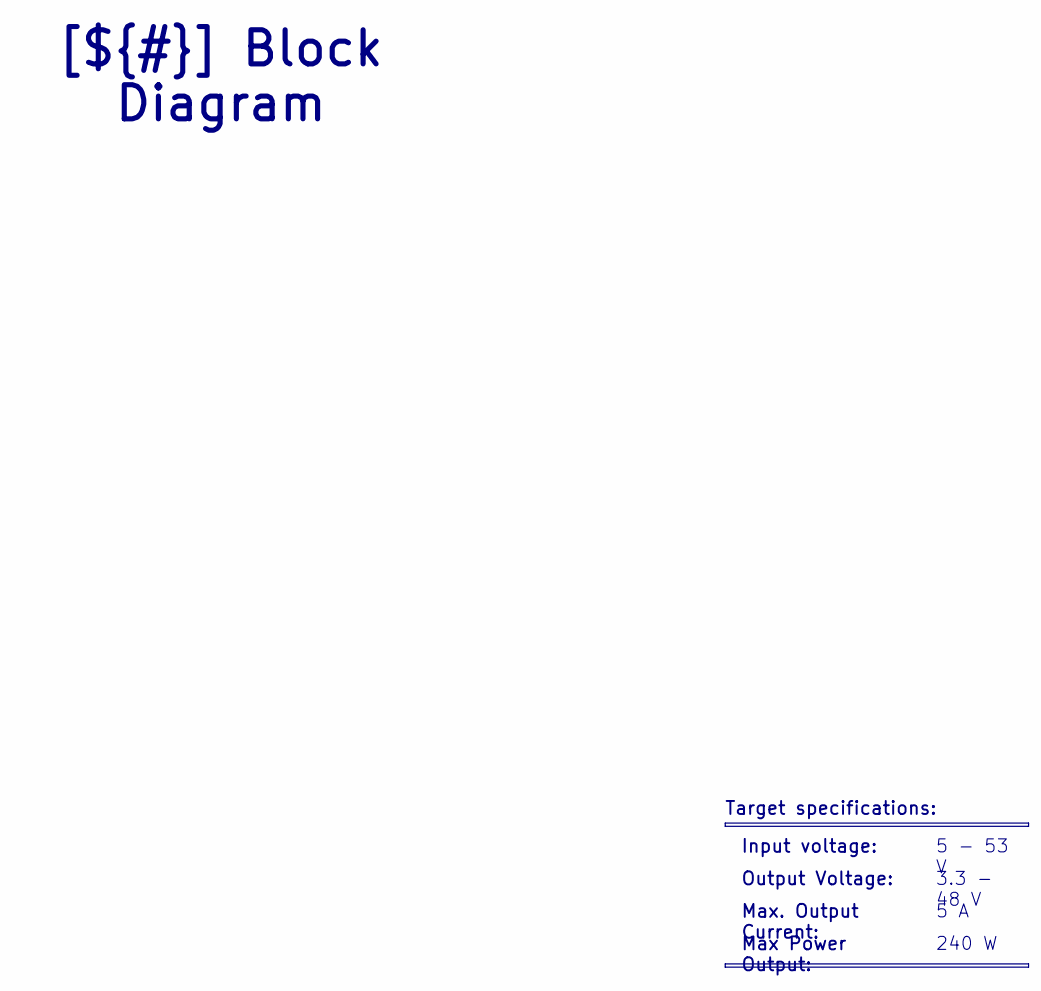
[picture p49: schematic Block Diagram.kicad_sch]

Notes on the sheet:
Max Power Output:
5 - 53 V
240 W
[${#}] ${TITLE}
3.3 - 48 V
Input voltage:
Target specifications:
Max. Output Current:
5 A
Output Voltage:

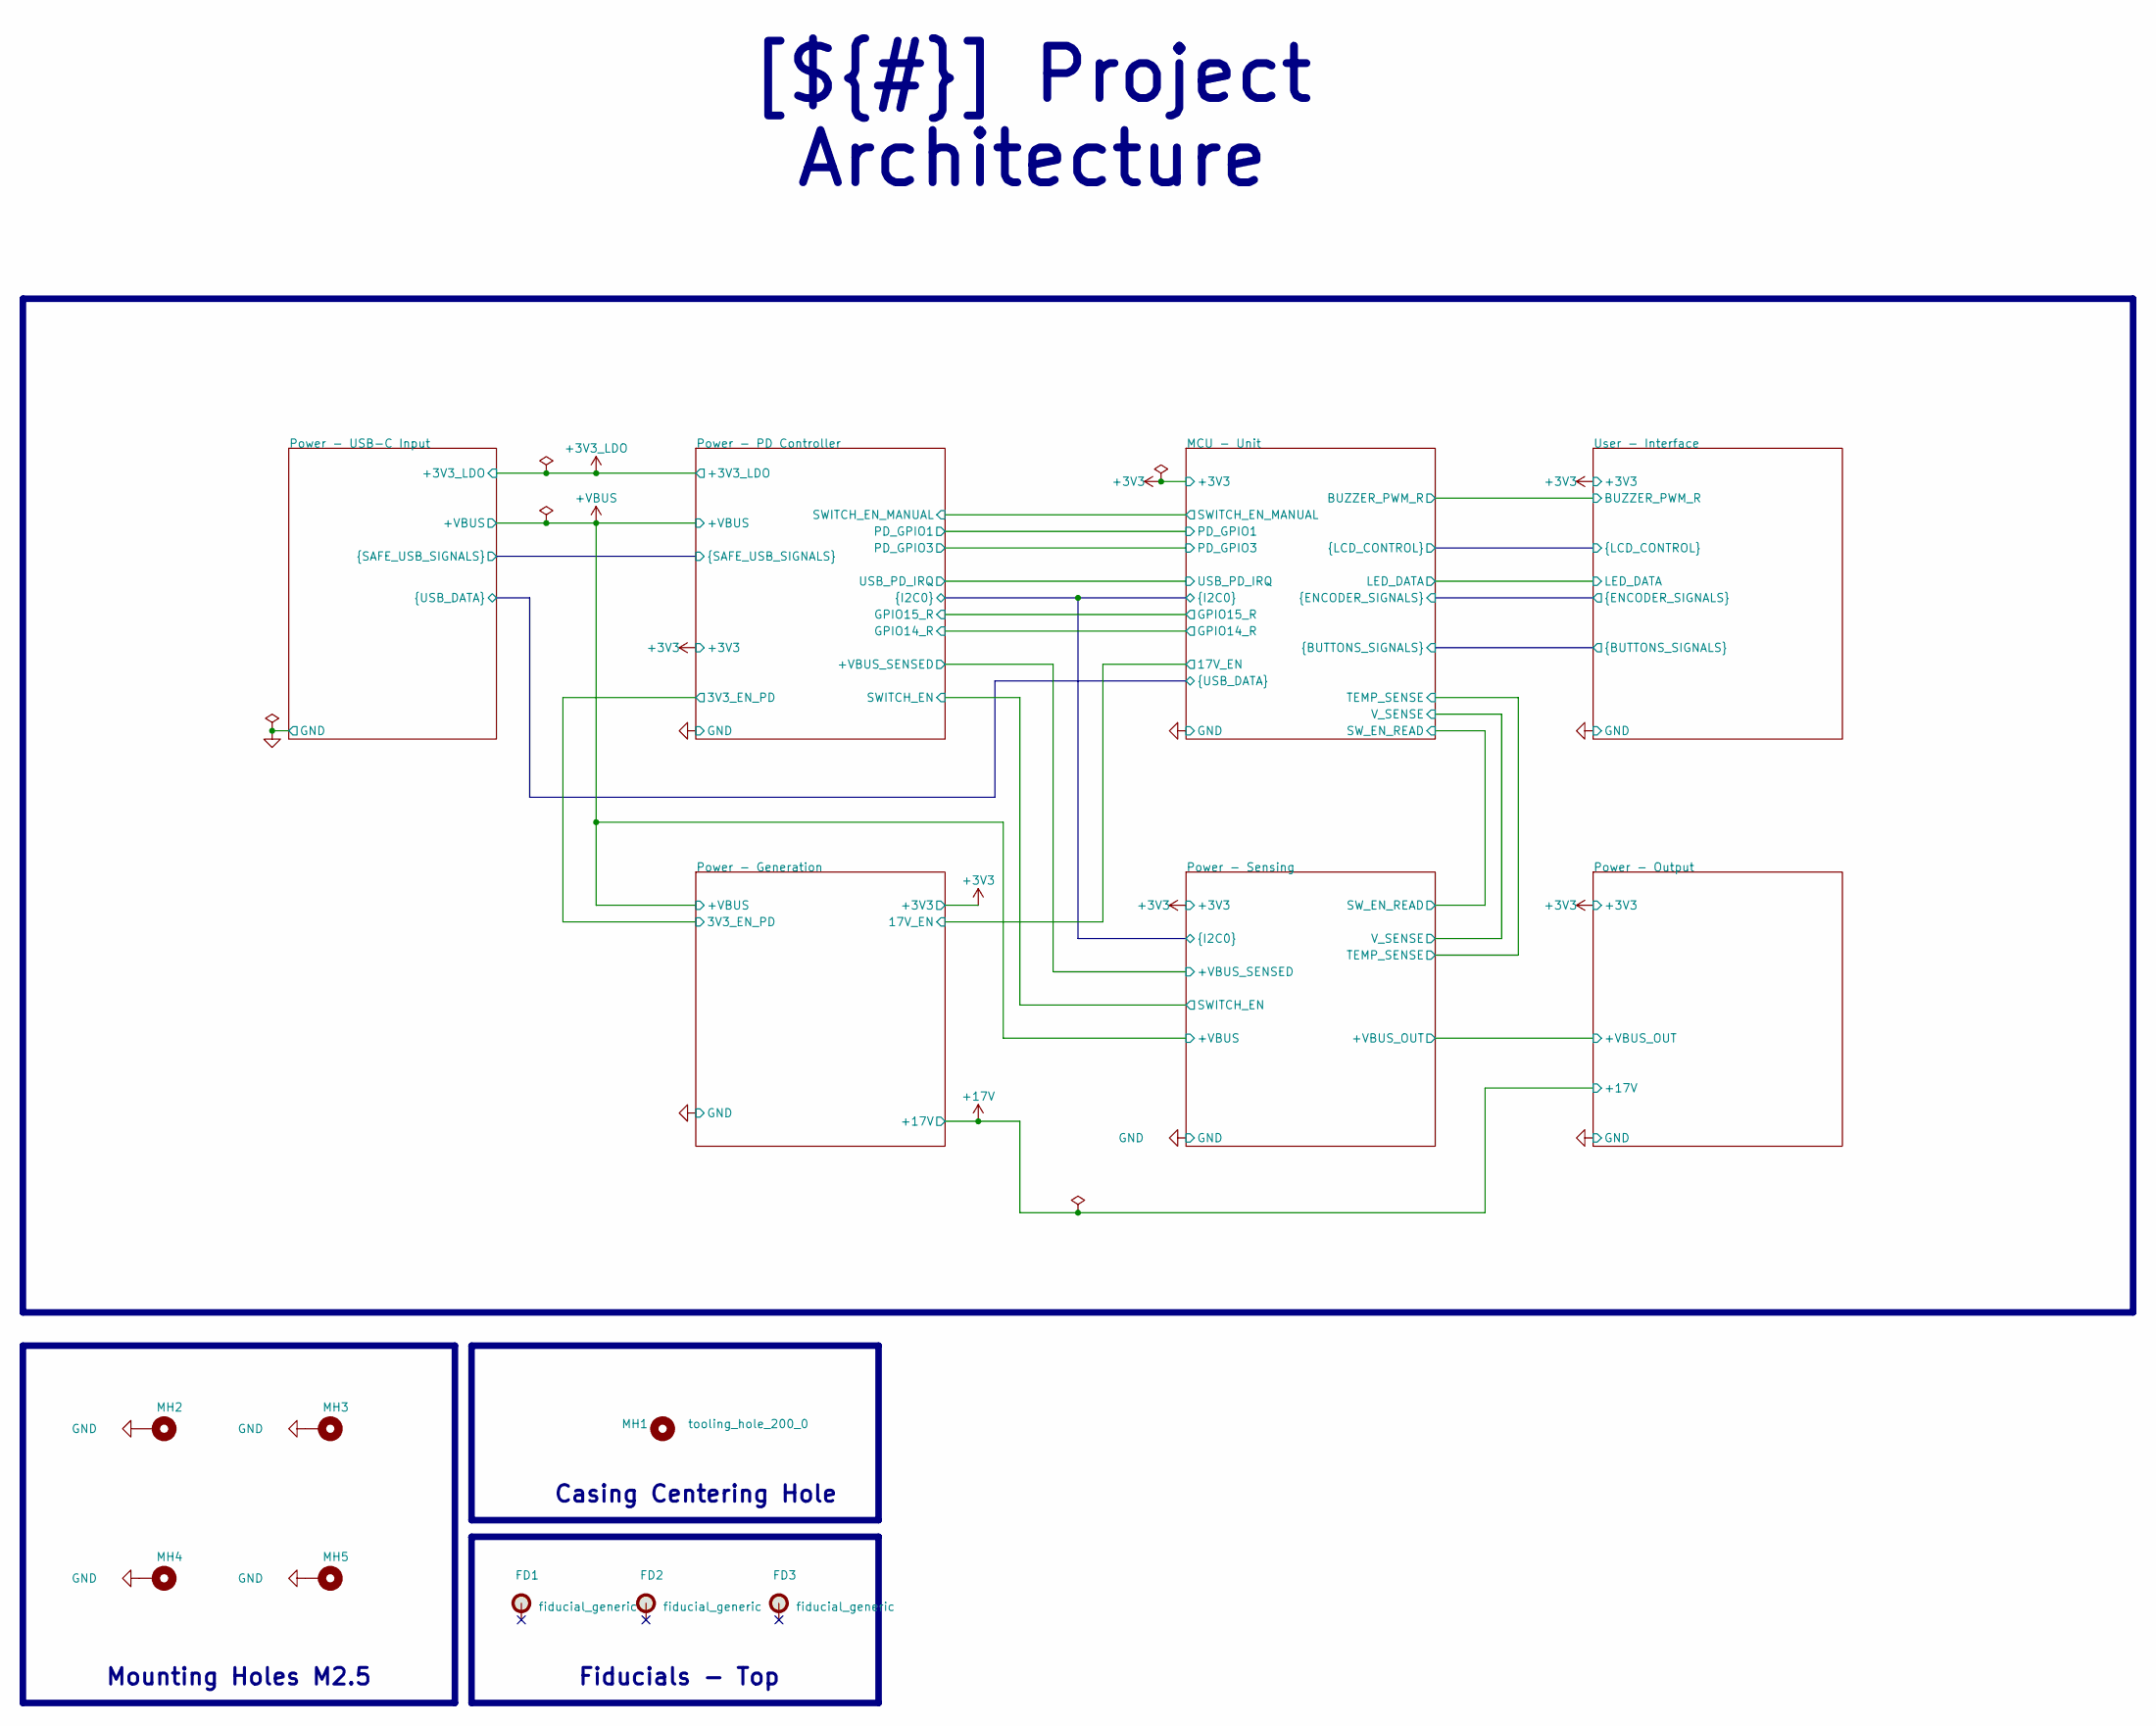
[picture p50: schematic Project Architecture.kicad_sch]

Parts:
FD1, FD2, FD3: fiducial_generic; fiducial_round_130
MH1: tooling_hole_200_0; tooling_hole_200_0_np
MH2, MH3, MH4, MH5: mounting_hole_270_540_p_via_8_50; MountingHole_2.7mm_M2.5_Pad_Via

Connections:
GND: MH2.1, MH3.1, MH4.1, MH5.1; also elsewhere on the board

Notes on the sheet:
Mounting Holes M2.5
Casing Centering Hole
Fiducials - Top
[${#}] ${TITLE}

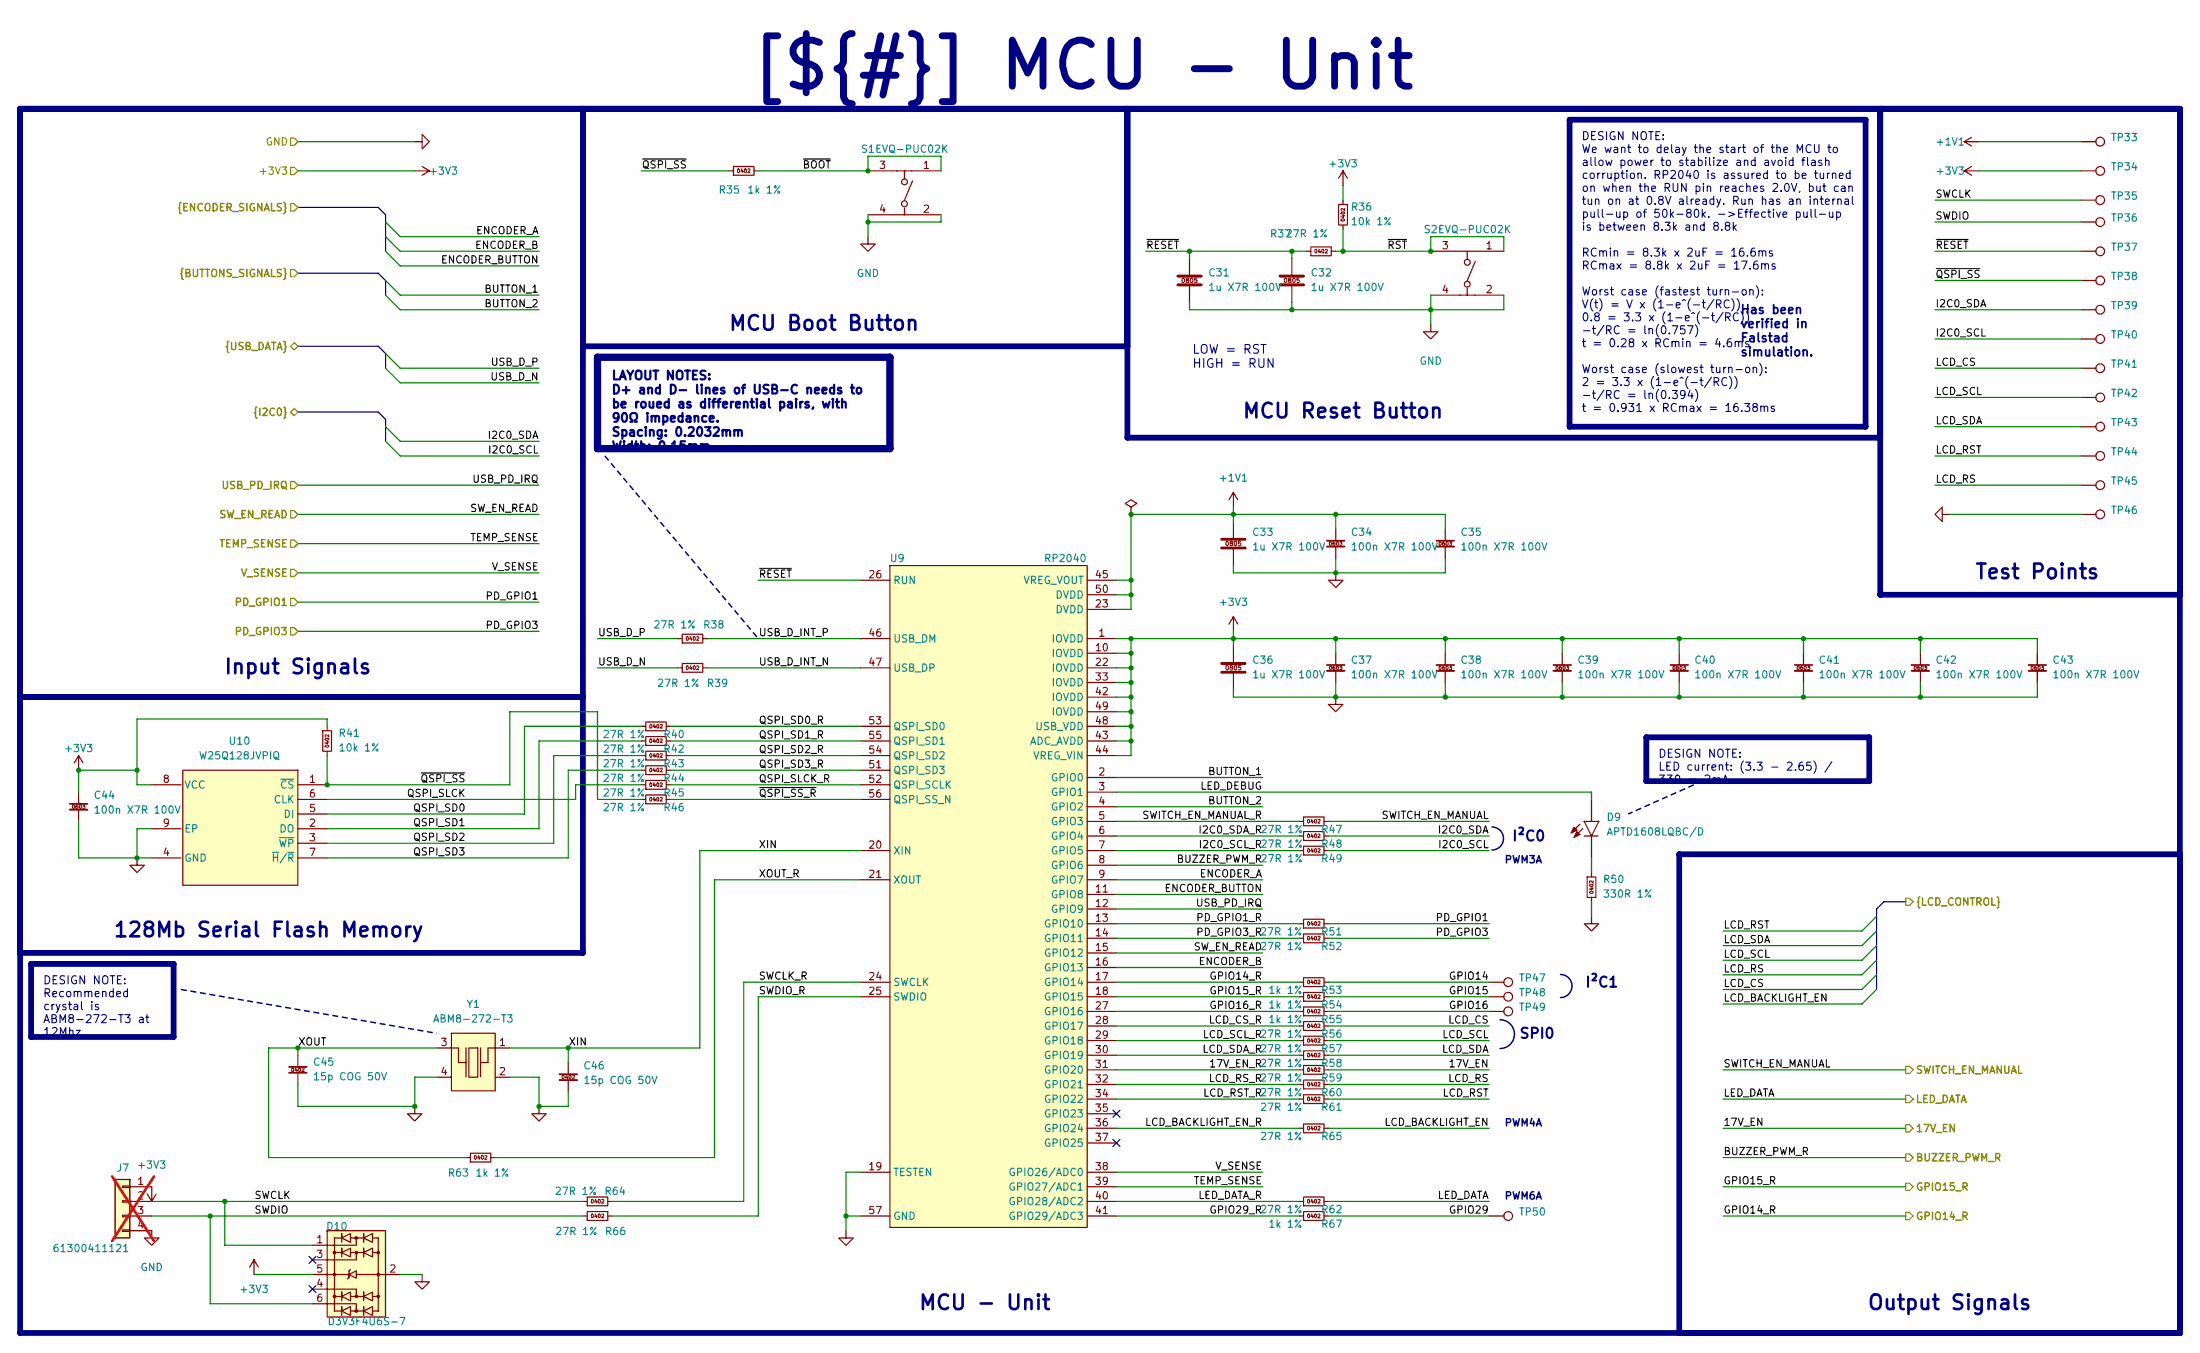
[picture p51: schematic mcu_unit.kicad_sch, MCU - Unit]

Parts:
C31, C32, C33, C36: 1u X7R 100V; capc_2012_14_n; Manufacturer Part Number CC0805KKX7R0BB105; LCSC C5370002
C34, C35, C37, C38, C39, C40, C41, C42, C43, C44: 100n X7R 100V; capc_1608_09_l; Manufacturer Part Number CL10B104KC8NNNC; LCSC C15725
C45, C46: 15p COG 50V; capc_1005_06_n; Manufacturer Part Number 0402CG150J500NT; LCSC C1548
D9: APTD1608LQBC/D; kingbright_0603_blue; Manufacturer Part Number APTD1608LQBC/D; LCSC C5344742
D10: D3V3F4U6S-7; sot363_sc88_65p_200x125x110_n; Manufacturer Part Number D3V3F4U6S-7; LCSC C1869321
J7: 61300411121; we_61300411121; Manufacturer Part Number 61300411121; LCSC C5184785; not fitted
R35, R53, R54, R55, R63, R67: 1k 1%; resc_1005_04_m; Manufacturer Part Number 0402WGF1001TCE; LCSC C11702
R36, R41: 10k 1%; resc_1005_04_n; Manufacturer Part Number 0402WGF1002TCE; LCSC C25744
R37, R38, R39, R40, R42, R43, R44, R45, R46, R47, R48, R49, R51, R52, R56, R57, R58, R59, R60, R61, R62, R64, R65, R66: 27R 1%; resc_1005_04_m; Manufacturer Part Number RC0402FR-0727RL; LCSC C138021
R50: 330R 1%; resc_1005_04_m; Manufacturer Part Number 0402WGF3300TCE; LCSC C25104
S1, S2: EVQ-PUC02K; EVQPUC02K; Manufacturer Part Number EVQ-PUC02K; LCSC C79174
TP33, TP34, TP35, TP36, TP37, TP38, TP39, TP40, TP41, TP42, TP43, TP44, TP45: tp_round_70
TP46, TP47, TP48, TP49, TP50: sp_oval_300x100
U9: RP2040; qfn56_40p_700x700x90_tp_320x320_mfg; Manufacturer Part Number SC0914(13); LCSC C2040
U10: W25Q128JVPIQ; wson8_127p_600x500x80_tp_435x340_n; Manufacturer Part Number W25Q128JVPIQ; LCSC C190862
Y1: ABM8-272-T3; osccc_320x205x80_abm8; Manufacturer Part Number ABM8-272-T3; LCSC C20625731

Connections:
+1V1: C33.1, C34.1, C35.1, TP33.1, U9.23 (DVDD), U9.45 (VREG_VOUT), U9.50 (DVDD)
+3V3: C36.1, C37.1, C38.1, C39.1, C40.1, C41.1, C42.1, C43.1, C44.1, D10.5, J7.1, R36.1, R41.1, TP34.1, U9.1 (IOVDD), U9.10 (IOVDD), U9.22 (IOVDD), U9.33 (IOVDD), U9.42 (IOVDD), U9.43 (ADC_AVDD), U9.44 (VREG_VIN), U9.48 (USB_VDD), U9.49 (IOVDD), U10.8 (VCC); also elsewhere on the board
/Project Architecture/MCU - Unit/17V_EN: R59.2; also elsewhere on the board
/Project Architecture/MCU - Unit/17V_EN_R: R59.1, U9.31 (GPIO20)
/Project Architecture/MCU - Unit/BUTTON_1: U9.2 (GPIO0); also elsewhere on the board
/Project Architecture/MCU - Unit/BUTTON_2: U9.4 (GPIO2); also elsewhere on the board
/Project Architecture/MCU - Unit/BUZZER_PWM_R: U9.8 (GPIO6); also elsewhere on the board
/Project Architecture/MCU - Unit/ENCODER_A: U9.9 (GPIO7); also elsewhere on the board
/Project Architecture/MCU - Unit/ENCODER_B: U9.16 (GPIO13); also elsewhere on the board
/Project Architecture/MCU - Unit/ENCODER_BUTTON: U9.11 (GPIO8); also elsewhere on the board
/Project Architecture/MCU - Unit/GPIO14: R53.2, TP47.1
/Project Architecture/MCU - Unit/GPIO14_R: R53.1, U9.17 (GPIO14); also elsewhere on the board
/Project Architecture/MCU - Unit/GPIO15: R54.2, TP48.1
/Project Architecture/MCU - Unit/GPIO15_R: R54.1, U9.18 (GPIO15); also elsewhere on the board
/Project Architecture/MCU - Unit/GPIO16: R55.2, TP49.1
/Project Architecture/MCU - Unit/GPIO16_R: R55.1, U9.27 (GPIO16)
/Project Architecture/MCU - Unit/GPIO29: R67.2, TP50.1
/Project Architecture/MCU - Unit/GPIO29_R: R67.1, U9.41 (GPIO29/ADC3)
/Project Architecture/MCU - Unit/I2C0_SCL: R49.2, TP40.1; also elsewhere on the board
/Project Architecture/MCU - Unit/I2C0_SCL_R: R49.1, U9.7 (GPIO5)
/Project Architecture/MCU - Unit/I2C0_SDA: R48.2, TP39.1; also elsewhere on the board
/Project Architecture/MCU - Unit/I2C0_SDA_R: R48.1, U9.6 (GPIO4)
/Project Architecture/MCU - Unit/LCD_BACKLIGHT_EN: R65.2; also elsewhere on the board
/Project Architecture/MCU - Unit/LCD_BACKLIGHT_EN_R: R65.1, U9.36 (GPIO24)
/Project Architecture/MCU - Unit/LCD_CS: R56.2, TP41.1; also elsewhere on the board
/Project Architecture/MCU - Unit/LCD_CS_R: R56.1, U9.28 (GPIO17)
/Project Architecture/MCU - Unit/LCD_RS: R60.2, TP45.1; also elsewhere on the board
/Project Architecture/MCU - Unit/LCD_RST: R61.2, TP44.1; also elsewhere on the board
/Project Architecture/MCU - Unit/LCD_RST_R: R61.1, U9.34 (GPIO22)
/Project Architecture/MCU - Unit/LCD_RS_R: R60.1, U9.32 (GPIO21)
/Project Architecture/MCU - Unit/LCD_SCL: R57.2, TP42.1; also elsewhere on the board
/Project Architecture/MCU - Unit/LCD_SCL_R: R57.1, U9.29 (GPIO18)
/Project Architecture/MCU - Unit/LCD_SDA: R58.2, TP43.1; also elsewhere on the board
/Project Architecture/MCU - Unit/LCD_SDA_R: R58.1, U9.30 (GPIO19)
/Project Architecture/MCU - Unit/LED_DATA: R62.2; also elsewhere on the board
/Project Architecture/MCU - Unit/LED_DATA_R: R62.1, U9.40 (GPIO28/ADC2)
/Project Architecture/MCU - Unit/LED_DEBUG: D9.2 (A), U9.3 (GPIO1)
/Project Architecture/MCU - Unit/PD_GPIO1: R51.2; also elsewhere on the board
/Project Architecture/MCU - Unit/PD_GPIO1_R: R51.1, U9.13 (GPIO10)
/Project Architecture/MCU - Unit/PD_GPIO3: R52.2; also elsewhere on the board
/Project Architecture/MCU - Unit/PD_GPIO3_R: R52.1, U9.14 (GPIO11)
/Project Architecture/MCU - Unit/QSPI_SD0: R40.1, U10.5 (DI)
/Project Architecture/MCU - Unit/QSPI_SD0_R: R40.2, U9.53 (QSPI_SD0)
/Project Architecture/MCU - Unit/QSPI_SD1: R42.1, U10.2 (DO)
/Project Architecture/MCU - Unit/QSPI_SD1_R: R42.2, U9.55 (QSPI_SD1)
/Project Architecture/MCU - Unit/QSPI_SD2: R43.1, U10.3 (~WP)
/Project Architecture/MCU - Unit/QSPI_SD2_R: R43.2, U9.54 (QSPI_SD2)
/Project Architecture/MCU - Unit/QSPI_SD3: R44.1, U10.7 (~H/~R)
/Project Architecture/MCU - Unit/QSPI_SD3_R: R44.2, U9.51 (QSPI_SD3)
/Project Architecture/MCU - Unit/QSPI_SLCK: R45.1, U10.6 (CLK)
/Project Architecture/MCU - Unit/QSPI_SLCK_R: R45.2, U9.52 (QSPI_SCLK)
/Project Architecture/MCU - Unit/SWCLK: D10.1, J7.2, R64.1, TP35.1
/Project Architecture/MCU - Unit/SWCLK_R: R64.2, U9.24 (SWCLK)
/Project Architecture/MCU - Unit/SWDIO: D10.6, J7.3, R66.1, TP36.1
/Project Architecture/MCU - Unit/SWDIO_R: R66.2, U9.25 (SWDIO)
/Project Architecture/MCU - Unit/SWITCH_EN_MANUAL: R47.2; also elsewhere on the board
/Project Architecture/MCU - Unit/SWITCH_EN_MANUAL_R: R47.1, U9.5 (GPIO3)
/Project Architecture/MCU - Unit/SW_EN_READ: U9.15 (GPIO12); also elsewhere on the board
/Project Architecture/MCU - Unit/TEMP_SENSE: U9.39 (GPIO27/ADC1); also elsewhere on the board
/Project Architecture/MCU - Unit/USB_D_INT_N: R39.2, U9.47 (USB_DP)
/Project Architecture/MCU - Unit/USB_D_INT_P: R38.2, U9.46 (USB_DM)
/Project Architecture/MCU - Unit/USB_D_N: R39.1; also elsewhere on the board
/Project Architecture/MCU - Unit/USB_D_P: R38.1; also elsewhere on the board
/Project Architecture/MCU - Unit/USB_PD_IRQ: U9.12 (GPIO9); also elsewhere on the board
/Project Architecture/MCU - Unit/V_SENSE: U9.38 (GPIO26/ADC0); also elsewhere on the board
/Project Architecture/MCU - Unit/XIN: C46.1, U9.20 (XIN), Y1.1
/Project Architecture/MCU - Unit/XOUT: C45.1, R63.1, Y1.3
/Project Architecture/MCU - Unit/XOUT_R: R63.2, U9.21 (XOUT)
/Project Architecture/MCU - Unit/~BOOT: R35.2, S1.1, S1.3
/Project Architecture/MCU - Unit/~QSPI_SS_R: R46.2, U9.56 (QSPI_SS_N)
/Project Architecture/MCU - Unit/~QSPI_SS: R35.1, R41.2, R46.1, TP38.1, U10.1 (~CS)
/Project Architecture/MCU - Unit/~RESET: C31.1, C32.1, R37.1, TP37.1, U9.26 (RUN)
/Project Architecture/MCU - Unit/~RST: R36.2, R37.2, S2.1, S2.3
GND: C31.2, C32.2, C33.2, C34.2, C35.2, C36.2, C37.2, C38.2, C39.2, C40.2, C41.2, C42.2, C43.2, C44.2, C45.2, C46.2, D10.2, J7.4, R50.2, S1.2, S1.4, S2.2, S2.4, TP46.1, U9.19 (TESTEN), U9.57 (GND), U10.4 (GND), U10.9 (EP), Y1.2, Y1.4; also elsewhere on the board
unnamed: D9.1 (C), R50.1

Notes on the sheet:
PWM4A
MCU Boot Button
MCU Reset Button
Input Signals
128Mb Serial Flash Memory
Test Points
I²C1
Output Signals
SPI0
I²C0
PWM6A
${TITLE}
PWM3A
LOW = RST HIGH = RUN
LAYOUT NOTES: D+ and D- lines of USB-C needs to be roued as differential pairs, with 90Ω impedance. Spacing: 0.2032mm Width: 0.15mm
DESIGN NOTE: We want to delay the start of the MCU to allow power to stabilize and avoid flash corruption. RP2040 is assured to be turned on when the RUN pin reaches 2.0V, but can tun on at 0.8V already. Run has an internal pull-up of 50k-80k. ->Effective pull-up is between 8.3k and 8.8k RCmin = 8.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
DESIGN NOTE: Recommended crystal is ABM8-272-T3 at 12Mhz.
Has been verified in Falstad simulation.
DESIGN NOTE: LED current: (3.3 - 2.65) / 330 = 2mA
[${#}] ${TITLE}

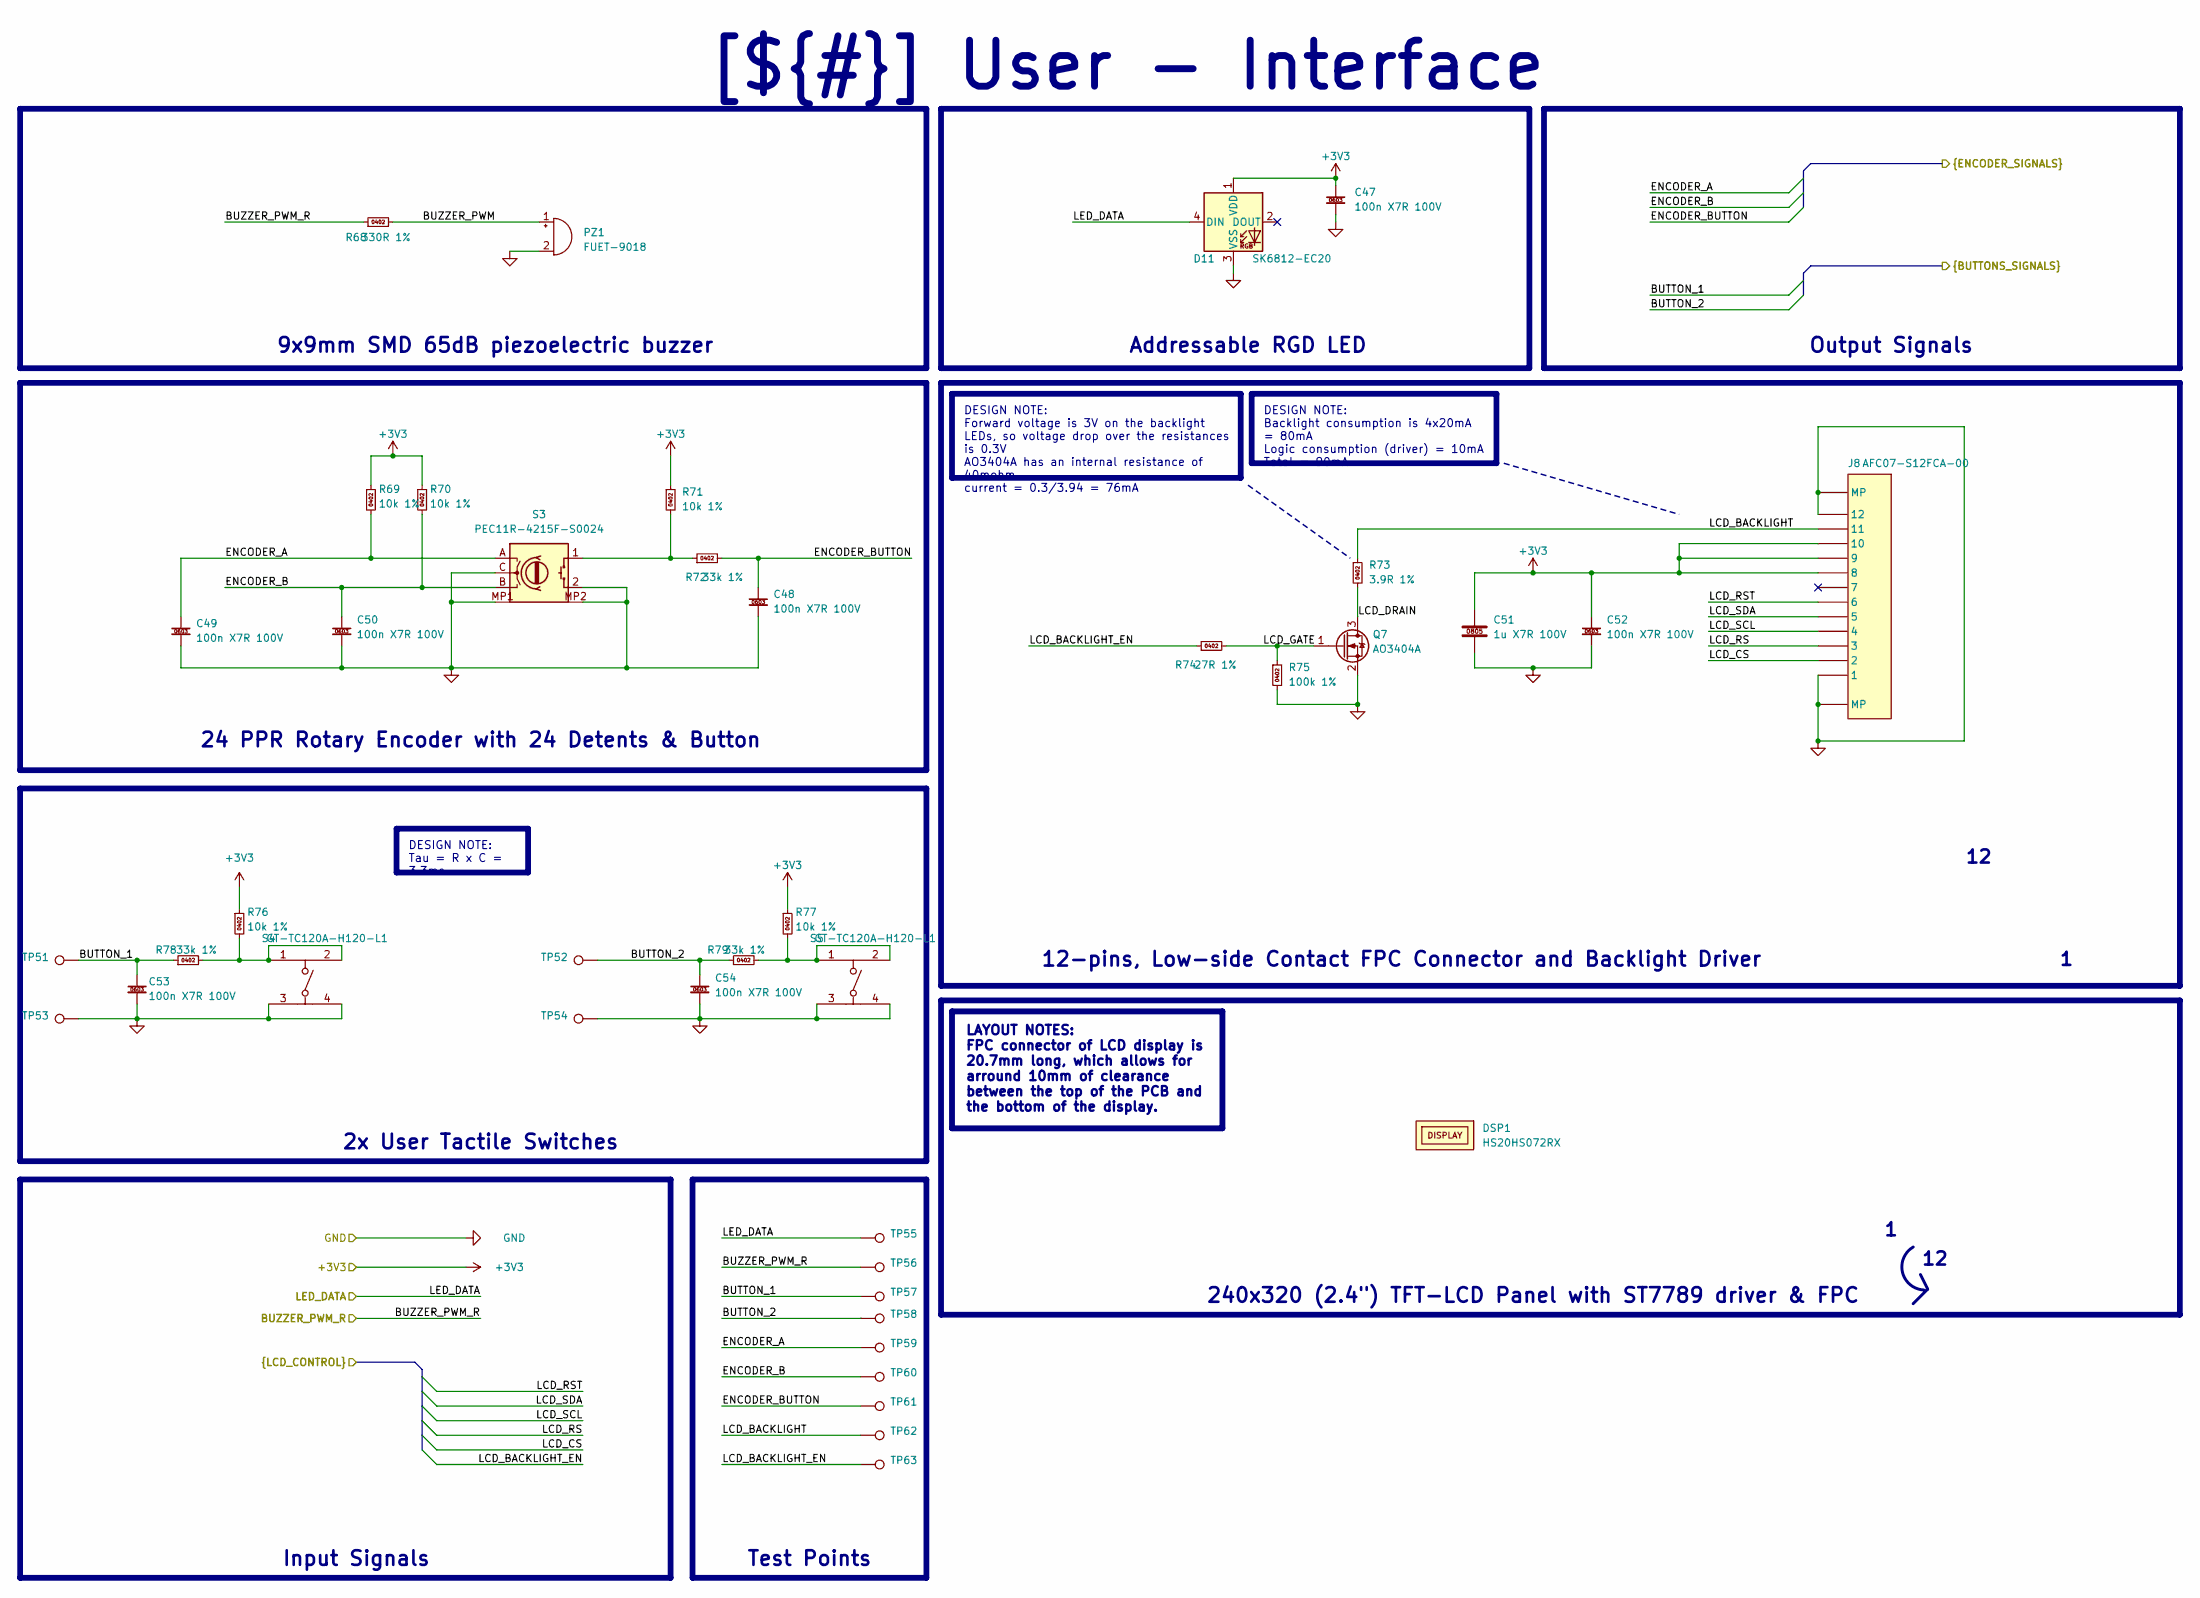
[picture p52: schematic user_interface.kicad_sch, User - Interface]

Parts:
C47, C48, C49, C50, C52, C53, C54: 100n X7R 100V; capc_1608_09_l; Manufacturer Part Number CL10B104KC8NNNC; LCSC C15725
C51: 1u X7R 100V; capc_2012_14_n; Manufacturer Part Number CC0805KKX7R0BB105; LCSC C5370002
D11: SK6812-EC20; Manufacturer Part Number SK6812-EC20; LCSC C2909058
DSP1: HS20HS072RX; generic_display_518x362x2_10mm_standoff; Manufacturer Part Number HS20HS072RX; LCSC C5329582
J8: AFC07-S12FCA-00; Manufacturer Part Number AFC07-S12FCA-00; LCSC C262559
PZ1: FUET-9018; buzzer_9x9x2.1mm; Manufacturer Part Number FUET-9018; LCSC C391035
Q7: AO3404A; sot-23-3L_103p_300x130x110_n; Manufacturer Part Number AO3404A; LCSC C30010
R68: 330R 1%; resc_1005_04_m; Manufacturer Part Number 0402WGF3300TCE; LCSC C25104
R69, R70, R71, R76, R77: 10k 1%; resc_1005_04_n; Manufacturer Part Number 0402WGF1002TCE; LCSC C25744
R72, R78, R79: 33k 1%; resc_1005_04_n; Manufacturer Part Number RC0402FR-0733KL; LCSC C138003
R73: 3.9R 1%; resc_1005_04_m; Manufacturer Part Number FRC0402F3R90TS; LCSC C2933095
R74: 27R 1%; resc_1005_04_m; Manufacturer Part Number RC0402FR-0727RL; LCSC C138021
R75: 100k 1%; resc_1005_04_m; Manufacturer Part Number 0402WGF1003TCE; LCSC C25741
S3: PEC11R-4215F-S0024; Manufacturer Part Number PEC11R-4215F-S0024; LCSC C143790
S4, S5: GT-TC120A-H120-L1; Manufacturer Part Number GT-TC120A-H120-L1; LCSC C2762973
TP51, TP52, TP53, TP54: sp_oval_300x100
TP55, TP56, TP57, TP58, TP59, TP60, TP61, TP62, TP63: tp_round_70

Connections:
+3V3: C47.1, C51.1, C52.1, D11.1 (VDD), J8.8, J8.9, J8.10, R69.1, R70.1, R71.1, R76.1, R77.1; also elsewhere on the board
/Project Architecture/MCU - Unit/BUTTON_1: C53.1, R78.1, TP51.1, TP57.1; also elsewhere on the board
/Project Architecture/MCU - Unit/BUTTON_2: C54.1, R79.1, TP52.1, TP58.1; also elsewhere on the board
/Project Architecture/MCU - Unit/BUZZER_PWM_R: R68.1, TP56.1; also elsewhere on the board
/Project Architecture/MCU - Unit/ENCODER_A: C49.1, R69.2, S3.A, TP59.1; also elsewhere on the board
/Project Architecture/MCU - Unit/ENCODER_B: C50.1, R70.2, S3.B, TP60.1; also elsewhere on the board
/Project Architecture/MCU - Unit/ENCODER_BUTTON: C48.1, R72.2, TP61.1; also elsewhere on the board
/Project Architecture/MCU - Unit/LCD_BACKLIGHT_EN: R74.1, TP63.1; also elsewhere on the board
/Project Architecture/MCU - Unit/LCD_CS: J8.2; also elsewhere on the board
/Project Architecture/MCU - Unit/LCD_RS: J8.3; also elsewhere on the board
/Project Architecture/MCU - Unit/LCD_RST: J8.6; also elsewhere on the board
/Project Architecture/MCU - Unit/LCD_SCL: J8.4; also elsewhere on the board
/Project Architecture/MCU - Unit/LCD_SDA: J8.5; also elsewhere on the board
/Project Architecture/MCU - Unit/LED_DATA: D11.4 (DIN), TP55.1; also elsewhere on the board
/Project Architecture/User - Interface/BUZZER_PWM: PZ1.1 (+), R68.2
/Project Architecture/User - Interface/LCD_BACKLIGHT: J8.11, R73.1, TP62.1
/Project Architecture/User - Interface/LCD_DRAIN: Q7.3 (D), R73.2
/Project Architecture/User - Interface/LCD_GATE: Q7.1 (G), R74.2, R75.1
GND: C47.2, C48.2, C49.2, C50.2, C51.2, C52.2, C53.2, C54.2, D11.3 (VSS), J8.1, J8.12, J8.MP1 (MP), J8.MP2 (MP), PZ1.2 (-), Q7.2 (S), R75.2, S3.2, S3.C, S3.MP1, S3.MP2, S4.3, S4.4, S5.3, S5.4, TP53.1, TP54.1; also elsewhere on the board
unnamed: R71.2, R72.1, S3.1
unnamed: R76.2, R78.2, S4.1, S4.2
unnamed: R77.2, R79.2, S5.1, S5.2

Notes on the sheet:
9x9mm SMD 65dB piezoelectric buzzer
Addressable RGD LED
12-pins, Low-side Contact FPC Connector and Backlight Driver
240x320 (2.4") TFT-LCD Panel with ST7789 driver & FPC
24 PPR Rotary Encoder with 24 Detents & Button
Input Signals
Test Points
Output Signals
2x User Tactile Switches
DESIGN NOTE: Backlight consumption is 4x20mA = 80mA Logic consumption (driver) = 10mA Total = 90mA
DESIGN NOTE: Tau = R x C = 3.3ms
DESIGN NOTE: Forward voltage is 3V on the backlight LEDs, so voltage drop over the resistances is 0.3V AO3404A has an internal resistance of 40mohm. current = 0.3/3.94 = 76mA
LAYOUT NOTES: FPC connector of LCD display is 20.7mm long, which allows for arround 10mm of clearance between the top of the PCB and the bottom of the display.
[${#}] ${TITLE}

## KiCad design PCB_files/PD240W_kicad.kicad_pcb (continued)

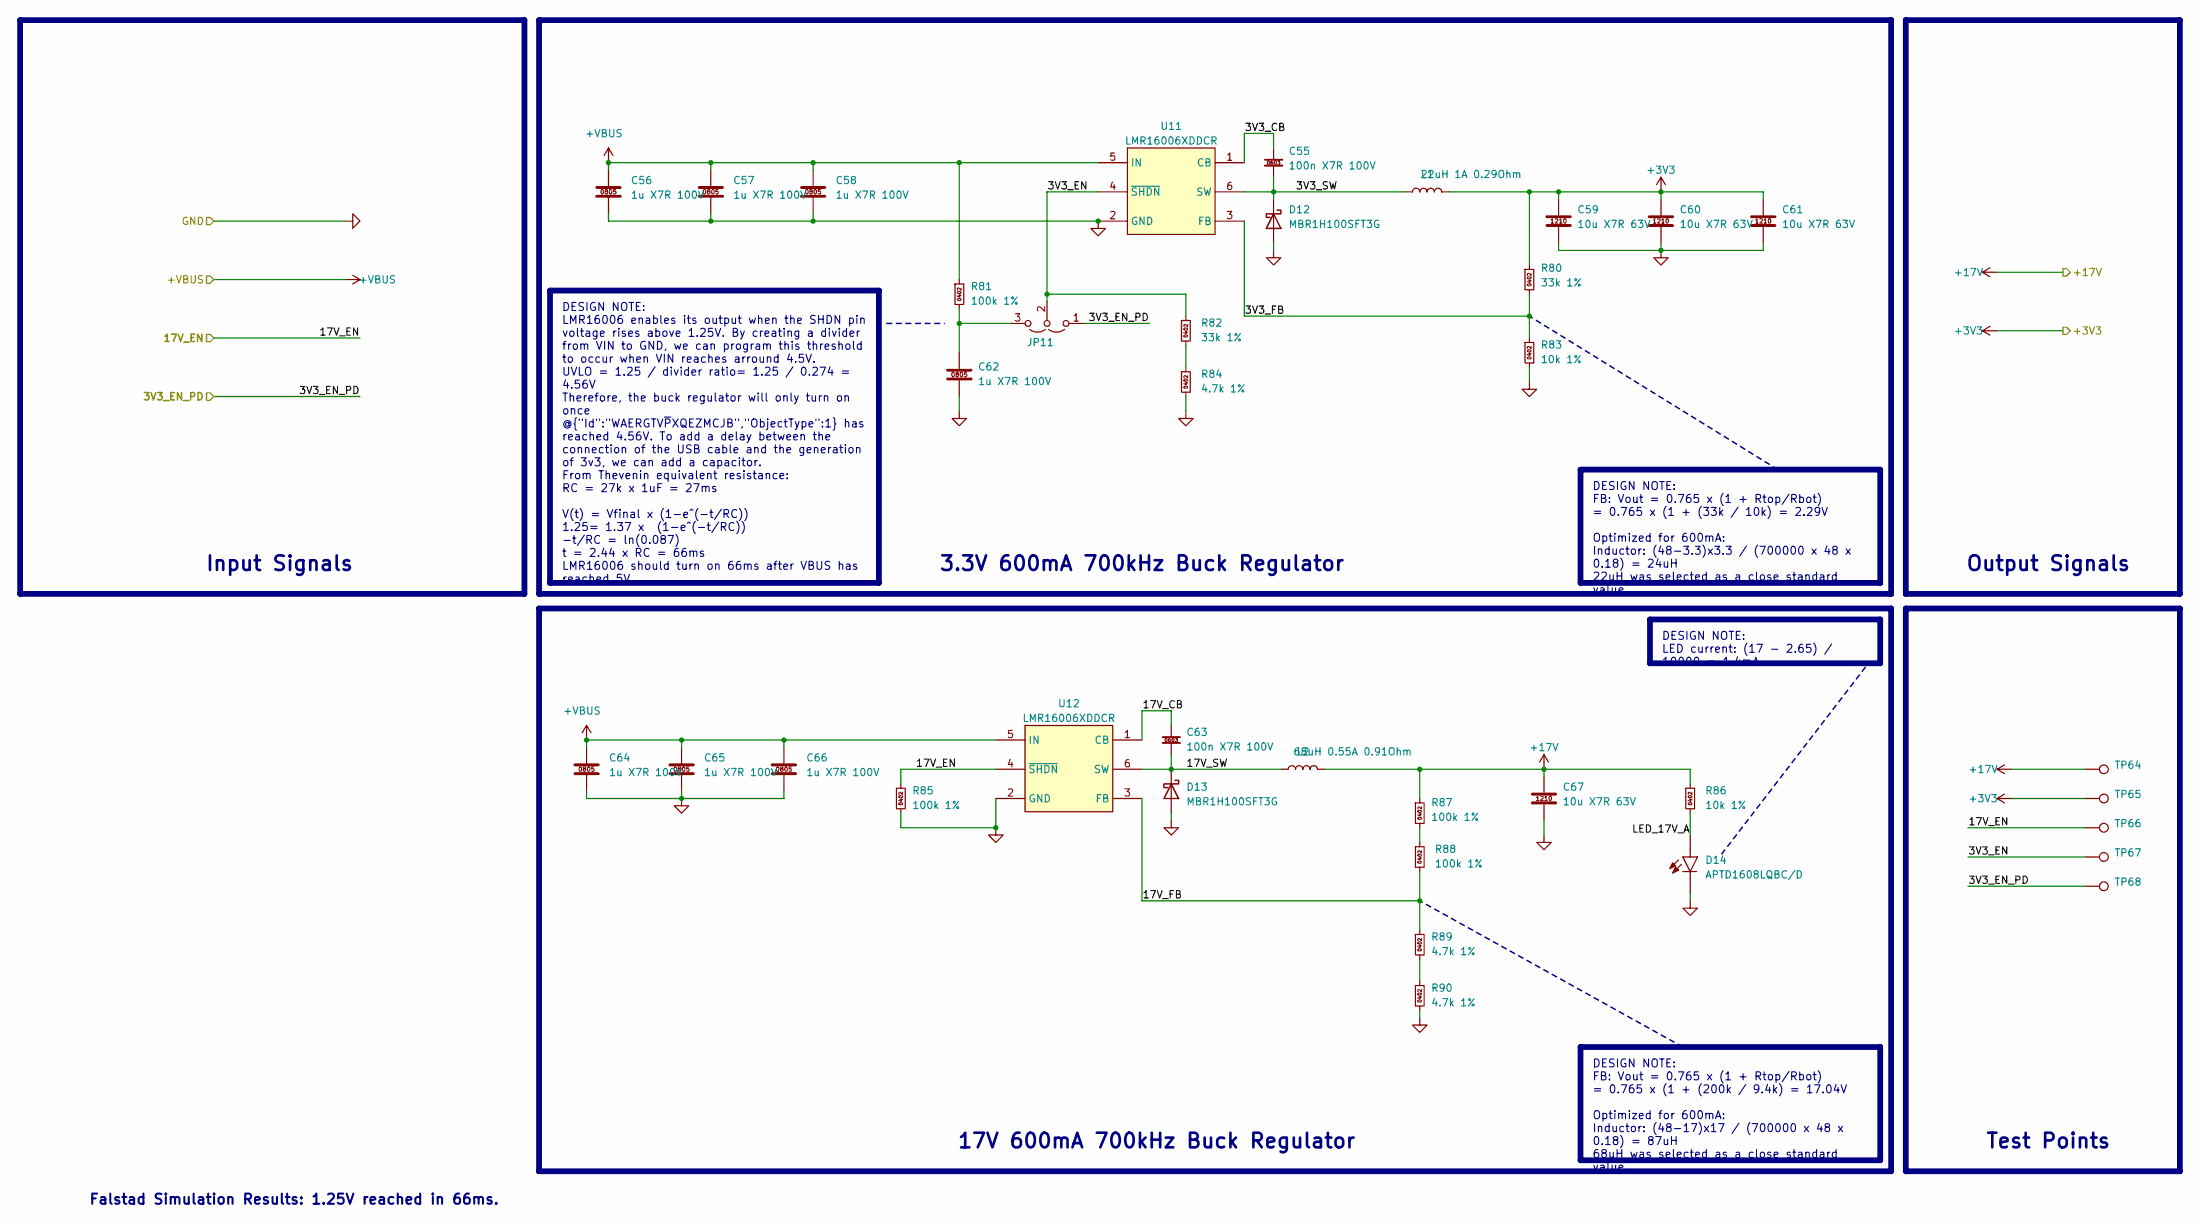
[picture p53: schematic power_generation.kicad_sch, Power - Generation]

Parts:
C55, C63: 100n X7R 100V; capc_1608_09_l; Manufacturer Part Number CL10B104KC8NNNC; LCSC C15725
C56, C57, C58, C62, C64, C65, C66: 1u X7R 100V; capc_2012_14_n; Manufacturer Part Number CC0805KKX7R0BB105; LCSC C5370002
C59, C60, C61, C67: 10u X7R 63V; capc_3225_27_n; Manufacturer Part Number GRM32ER71J106KA12L; LCSC C437568
D12, D13: MBR1H100SFT3G; sod-123fl_305p_260x160x90_n; Manufacturer Part Number MBR1H100SFT3G; LCSC C235757
D14: APTD1608LQBC/D; kingbright_0603_blue; Manufacturer Part Number APTD1608LQBC/D; LCSC C5344742
JP11: jumper_solder_3pad_no; jumper_solder_3pad_no_40x40_20
L1: 22uH 1A 0.29Ohm; SWPA4030S220MT; Manufacturer Part Number SWPA4030S220MT; LCSC C83472
L2: 68uH 0.55A 0.91Ohm; SWPA4030S220MT; Manufacturer Part Number ASWPA4035S680MT; LCSC C340217
R80, R82: 33k 1%; resc_1005_04_n; Manufacturer Part Number RC0402FR-0733KL; LCSC C138003
R81, R85, R87, R88: 100k 1%; resc_1005_04_m; Manufacturer Part Number 0402WGF1003TCE; LCSC C25741
R83, R86: 10k 1%; resc_1005_04_n; Manufacturer Part Number 0402WGF1002TCE; LCSC C25744
R84, R89, R90: 4.7k 1%; resc_1005_04_m; Manufacturer Part Number 0402WGF1003TCE; LCSC C25741
TP64, TP65, TP66, TP67, TP68: tp_round_70
U11, U12: LMR16006XDDCR; sot6_p95_290x180x110_n; Manufacturer Part Number LMR16006XDDCR; LCSC C87080

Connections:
+3V3: C59.1, C60.1, C61.1, L1.2, R80.1, TP65.1; also elsewhere on the board
+17V: C67.1, L2.2, R86.1, R87.1, TP64.1; also elsewhere on the board
+VBUS: C56.1, C57.1, C58.1, C64.1, C65.1, C66.1, R81.1, U11.5 (IN), U12.5 (IN); also elsewhere on the board
/Project Architecture/MCU - Unit/17V_EN: R85.1, TP66.1, U12.4 (~SHDN); also elsewhere on the board
/Project Architecture/Power - Generation/3V3_CB: C55.1, U11.1 (CB)
/Project Architecture/Power - Generation/3V3_EN: JP11.2 (C), R82.1, TP67.1, U11.4 (~SHDN)
/Project Architecture/Power - Generation/3V3_EN_PD: JP11.1 (A), TP68.1; also elsewhere on the board
/Project Architecture/Power - Generation/3V3_FB: R80.2, R83.1, U11.3 (FB)
/Project Architecture/Power - Generation/3V3_SW: C55.2, D12.1 (K), L1.1, U11.6 (SW)
/Project Architecture/Power - Generation/17V_CB: C63.1, U12.1 (CB)
/Project Architecture/Power - Generation/17V_FB: R88.2, R89.1, U12.3 (FB)
/Project Architecture/Power - Generation/17V_SW: C63.2, D13.1 (K), L2.1, U12.6 (SW)
/Project Architecture/Power - Generation/LED_17V_A: D14.2 (A), R86.2
GND: C56.2, C57.2, C58.2, C59.2, C60.2, C61.2, C62.2, C64.2, C65.2, C66.2, C67.2, D12.2 (A), D13.2 (A), D14.1 (C), R83.2, R84.2, R85.2, R90.2, U11.2 (GND), U12.2 (GND); also elsewhere on the board
unnamed: C62.1, JP11.3 (B), R81.2
unnamed: R82.2, R84.1
unnamed: R87.2, R88.1
unnamed: R89.2, R90.1

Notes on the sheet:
Input Signals
Output Signals
Test Points
3.3V 600mA 700kHz Buck Regulator
Falstad Simulation Results: 1.25V reached in 66ms.
17V 600mA 700kHz Buck Regulator
DESIGN NOTE: LMR16006 enables its output when the SHDN pin voltage rises above 1.25V. By creating a divider from VIN to GND, we can program this threshold to occur when VIN reaches arround 4.5V. UVLO = 1.25 / divider ratio= 1.25 / 0.274 = 4.56V Therefore, the buck regulator will only turn on once @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
DESIGN NOTE: FB: Vout = 0.765 x (1 + Rtop/Rbot) = 0.765 x (1 + (33k / 10k) = 2.29V Optimized for 600mA: Inductor: (48-3.3)x3.3 / (700000 x 48 x 0.18) = 24uH 22uH was selected as a close standard value.
DESIGN NOTE: LED current: (17 - 2.65) / 10000 = 1.4mA
DESIGN NOTE: FB: Vout = 0.765 x (1 + Rtop/Rbot) = 0.765 x (1 + (200k / 9.4k) = 17.04V Optimized for 600mA: Inductor: (48-17)x17 / (700000 x 48 x 0.18) = 87uH 68uH was selected as a close standard value.

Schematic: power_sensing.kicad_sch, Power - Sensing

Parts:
C23, C24, C25, C26, C27: 100n X7R 100V; capc_1608_09_l; Manufacturer Part Number CL10B104KC8NNNC; LCSC C15725
NT1: nt_2pad_20x20_20_60x20; NetTie-2_SMD_Pad0.5mm
R22: 8m 1%; WSLP1206_n_current_sense_6m_to_50m; Manufacturer Part Number HoLLR1206-1W-8mR-1%; LCSC C2988654
R23, R24, R26: 27R 1%; resc_1005_04_m; Manufacturer Part Number RC0402FR-0727RL; LCSC C138021
R25, R30: 4.7k 1%; resc_1005_04_m; Manufacturer Part Number 0402WGF1003TCE; LCSC C25741
R27, R28, R29: 100k 1%; resc_1005_04_m; Manufacturer Part Number 0402WGF1003TCE; LCSC C25741
R31: 10k 1%; resc_1005_04_n; Manufacturer Part Number 0402WGF1002TCE; LCSC C25744
R32: 10k @25°C; resc_1005_04_m; Manufacturer Part Number SDNT1005X103F3950FTF; LCSC C95939
TP27, TP28, TP29, TP30: tp_round_70
U7: SN74LVC1G17DBVR; sot25_95p_300x280x145_jedec_mo-178-aa_n; Manufacturer Part Number SN74LVC1G17DBVR; LCSC C7836
U8: INA228AIDGSR; vssop10_50p_300x300x110_mfg; Manufacturer Part Number INA228AIDGSR; LCSC C2887910

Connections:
+3V3: C24.1, C25.1, R30.1, U7.5 (VCC), U8.6 (VS); also elsewhere on the board
+VBUS: R27.1, R28.1; also elsewhere on the board
+VBUS_OUT: R22.2, R24.1, TP30.1, U8.8 (VBUS); also elsewhere on the board
+VBUS_SENSED: R22.1, R23.1; also elsewhere on the board
/Project Architecture/MCU - Unit/I2C0_SCL: U8.5 (SCL); also elsewhere on the board
/Project Architecture/MCU - Unit/I2C0_SDA: U8.4 (SDA); also elsewhere on the board
/Project Architecture/MCU - Unit/SW_EN_READ: R25.2, TP29.1; also elsewhere on the board
/Project Architecture/MCU - Unit/TEMP_SENSE: C27.1, R30.2, R32.1; also elsewhere on the board
/Project Architecture/MCU - Unit/V_SENSE: C26.1, R29.2, R31.1, TP27.1; also elsewhere on the board
/Project Architecture/Power - PD Controller/SWITCH_EN: R26.2, TP28.1, U7.2 (A); also elsewhere on the board
/Project Architecture/Power - Sensing/INA_ALERT: R26.1, U8.3 (ALERT)
/Project Architecture/Power - Sensing/SENSE_N: C23.2, R24.2, U8.9 (IN-)
/Project Architecture/Power - Sensing/SENSE_P: C23.1, R23.2, U8.10 (IN+)
GND: C24.2, C25.2, C26.2, C27.2, NT1.2, R31.2, U7.3 (GND), U8.1 (A1), U8.2 (A0), U8.7 (GND); also elsewhere on the board
unnamed: NT1.1, R32.2
unnamed: R27.2, R28.2, R29.1
unnamed: R25.1, U7.4 (Y)

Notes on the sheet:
Test Points
Input Signals
85-V, 20-Bit, Ultra-Precise Power/Energy/Charge Monitor With I²C Interface
Temperature Sensing
Output Signals
Input Voltage Sensing
DESIGN NOTE: B-Constant is 3950K 1.2k @ 80°C -> 0.67V 2.5k @ 60°C -> 1.14V 10k @ 25°C -> 2.24V 13k @ 20°C -> 2.42V
DESIGN NOTE: I2C pullups are on Power - PD Conroller schematic
DEBUG NOTE: INA228AIDGSR address when A1 & A0 are tied to GND is 0x40 (7 bits 1000000) (see page 19)
DESIGN NOTE: ADCRANGE = 1 (+- 40.96 mV range) V_{SENSE} = 5A x 0.008 = 40 mV. This utilizes 97.6% of the ADC range, providing the highest possible resolution. Power Dissipation: P = 5² x 0.008 = 0.2W
LAYOUT NOTES: NTC must be placed close and thermally coupled to the ground plane near the relevant heat source. Route away from noisy traces.
LAYOUT NOTES: Place capacitor close to MCU DC pin. Route away from noisy traces.
[${#}] ${TITLE}
DEBUG NOTE: Low side measurement is used to improve thermal coupling, which invert the maths in software.
DESIGN NOTE: Network ratio = 1/16 = 0.0625 @48V V_SENSE = 3V @5V V_SENSE = 0.31V
DEBUG NOTE: ALERT is open-drain and can be configured to latch or not latch the overcurrent event.
DESIGN NOTE: SN74LVC1G17 is a safety buffer to prevent software mistakes. Driving SWEN_READ cannot activate the power switch.

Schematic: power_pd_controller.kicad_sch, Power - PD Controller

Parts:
C9, C10, C11, C12: 10u X7R 63V; capc_3225_27_n; Manufacturer Part Number GRM32ER71J106KA12L; LCSC C437568
C13, C14, C15: 3.3u X5R 25V; capc_1608_09_n; Manufacturer Part Number TCC0603X5R335M250CT; LCSC C5360803
C16, C17, C21, C22: 100n X7R 100V; capc_1608_09_l; Manufacturer Part Number CL10B104KC8NNNC; LCSC C15725
C18: 2.2u X7R 100V; capc_2012_14_m; Manufacturer Part Number HHV0805R7225K101NSLJ; LCSC C22367838
C19, C20: 220p X7R 50V; capc_1005_06_l; Manufacturer Part Number CL05B221KB5NNNC; LCSC C296710
D5: B0520LW-7-F; sod-123_270x155135_n; Manufacturer Part Number B0520LW-7-F; LCSC C155367
D6: APTD1608LQBC/D; kingbright_0603_blue; Manufacturer Part Number APTD1608LQBC/D; LCSC C5344742
D7: D3V3F4U6S-7; sot363_sc88_65p_200x125x110_n; Manufacturer Part Number D3V3F4U6S-7; LCSC C1869321
J2: 61300411121; we_61300411121; Manufacturer Part Number 61300411121; LCSC C5184785; not fitted
JP3: jumper_solder_3pad_12nc_kicad; SolderJumper-3_P1.3mm_Bridged2Bar12_RoundedPad1.0x1.5mm
JP4, JP5, JP6, JP7, JP8, JP9: jumper_solder_2pad_no; jumper_solder_2pad_no_40x40_20
JP10: jumper_solder_2pad_no_kicad; SolderJumper-2_P1.3mm_Open_RoundedPad1.0x1.5mm
Q3: SQJB90EP-T1_GE3; PowerPAKSO-8_127p_513x615x120_n; Manufacturer Part Number SQJB90EP-T1_GE3; LCSC C727731
Q4, Q5, Q6: AO3404A; sot-23-3L_103p_300x130x110_n; Manufacturer Part Number AO3404A; LCSC C30010
R7: 27R 1%; resc_1005_04_m; Manufacturer Part Number RC0402FR-0727RL; LCSC C138021
R8, R9, R11, R12, R18: 4.7k 1%; resc_1005_04_m; Manufacturer Part Number 0402WGF1003TCE; LCSC C25741
R10, R13, R19: 10k 1%; resc_1005_04_n; Manufacturer Part Number 0402WGF1002TCE; LCSC C25744
R14, R15, R16, R17, R21: 100k 1%; resc_1005_04_m; Manufacturer Part Number 0402WGF1003TCE; LCSC C25741
R20: 330R 1%; resc_1005_04_m; Manufacturer Part Number 0402WGF3300TCE; LCSC C25104
TP14, TP15, TP16, TP17, TP18, TP19, TP20, TP21, TP22, TP23, TP24, TP25, TP26: tp_round_70
U2: LM2765; sot236_p95_290x160x110_n; Manufacturer Part Number LM2765M6X/NOPB; LCSC C140270
U3: TPS26750SRSMR; qfn32_40p_400x400x100_tp_280x280_mfg; Manufacturer Part Number TPS26750SRSMR; LCSC C42166327
U4: LTC7004x; msop_10p_300x490x110_tp168x188_n; Manufacturer Part Number LTC7004EMSE#TRPBF; LCSC C690106
U5: 74LVC1G08SE-7; sot353_65p_200x125x110_mo-203-aa_n; Manufacturer Part Number 74LVC1G08SE-7; LCSC C460522
U6: CAT24C512YI-GT3; JEDEC_MO-153_AA; Manufacturer Part Number CAT24C512YI-GT3; LCSC C56096

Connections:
+1V5_LDO: C9.1, TP22.1, U3.2 (ADCIN1), U3.3 (ADCIN2), U3.4 (LDO_1V5)
+3V3: C11.1, D6.2 (A), D7.5, U3.32 (VIN_3V3); also elsewhere on the board
+3V3_EEPROM: C22.1, J2.1, JP10.1 (A), U6.8 (VCC)
+3V3_LDO: C10.1, C13.1, C21.1, D5.2 (A), JP10.2 (B), R8.1, R9.1, R10.1, R11.1, R12.1, R13.1, R15.1, R16.1, TP24.1, U2.1 (IN), U3.1 (LDO_3V3), U5.5 (VCC); also elsewhere on the board
+6V6_LDO: C14.1, D5.1 (K), TP26.1, U2.5 (OUT), U4.1 (VCC)
+VBUS: JP3.3 (B), Q3.5 (D); also elsewhere on the board
+VBUS_LV: C17.1, U3.26 (VBUS), U3.27 (VBUS); also elsewhere on the board
+VBUS_SENSED: Q3.6 (D), TP20.1; also elsewhere on the board
/Project Architecture/MCU - Unit/GPIO14_R: JP9.2 (B); also elsewhere on the board
/Project Architecture/MCU - Unit/GPIO15_R: JP8.2 (B); also elsewhere on the board
/Project Architecture/MCU - Unit/I2C0_SCL: R9.2, U3.9 (I2CT_SCL); also elsewhere on the board
/Project Architecture/MCU - Unit/I2C0_SDA: R8.2, U3.8 (I2CT_SDA); also elsewhere on the board
/Project Architecture/MCU - Unit/PD_GPIO1: TP15.1, U3.6 (GPIO1); also elsewhere on the board
/Project Architecture/MCU - Unit/PD_GPIO3: TP18.1, U3.18 (GPIO3); also elsewhere on the board
/Project Architecture/MCU - Unit/SWITCH_EN_MANUAL: R21.1, U5.2 (B); also elsewhere on the board
/Project Architecture/MCU - Unit/USB_PD_IRQ: R10.2, TP16.1, U3.10 (*I2CT_IRQ); also elsewhere on the board
/Project Architecture/Power - Generation/3V3_EN_PD: U3.31 (GPIO6); also elsewhere on the board
/Project Architecture/Power - PD Controller/CAP+: C15.1, U2.6 (CAP+)
/Project Architecture/Power - PD Controller/CAP-: C15.2, U2.3 (CAP-)
/Project Architecture/Power - PD Controller/CC1: C20.1, U3.24 (CC1); also elsewhere on the board
/Project Architecture/Power - PD Controller/CC2: C19.1, U3.25 (CC2); also elsewhere on the board
/Project Architecture/Power - PD Controller/EPR_EN: U3.7 (GPIO2); also elsewhere on the board
/Project Architecture/Power - PD Controller/I2CC_IRQ: R13.2, U3.17 (*I2CC_IRQ)
/Project Architecture/Power - PD Controller/I2CC_SCL: JP6.2 (B), U3.16 (I2CC_SCL)
/Project Architecture/Power - PD Controller/I2CC_SCL_EEPROM: JP6.1 (A), JP7.2 (B), JP8.1 (A), R12.2, U6.6 (SCL)
/Project Architecture/Power - PD Controller/I2CC_SCL_EXT: D7.1, J2.2, JP7.1 (A)
/Project Architecture/Power - PD Controller/I2CC_SDA: JP4.2 (B), U3.15 (I2CC_SDA)
/Project Architecture/Power - PD Controller/I2CC_SDA_EEPROM: JP4.1 (A), JP5.2 (B), JP9.1 (A), R11.2, U6.5 (SDA)
/Project Architecture/Power - PD Controller/I2CC_SDA_EXT: D7.6, J2.3, JP5.1 (A)
/Project Architecture/Power - PD Controller/LTC_BST: C18.2, U4.9 (BST)
/Project Architecture/Power - PD Controller/LTC_GATE: Q3.2 (G), Q3.4 (G), R7.2, R14.2, R17.2, TP25.1, U4.6 (TGDN)
/Project Architecture/Power - PD Controller/POWER_PATH_EN: Q4.1 (G), TP14.1, U3.20 (POWER_PATH_EN)
/Project Architecture/Power - PD Controller/PP5V: C12.1, U3.28 (PP5V), U3.29 (PP5V)
/Project Architecture/Power - PD Controller/PP_EN1: Q4.3 (D), Q5.1 (G), R15.2, TP17.1
/Project Architecture/Power - PD Controller/PP_EN2: Q5.3 (D), R16.2, TP19.1, U5.1 (A)
/Project Architecture/Power - PD Controller/PP_EN3: R18.1, R19.1, TP21.1, U5.4 (Y)
/Project Architecture/Power - PD Controller/SWITCH_EN: Q6.1 (G), R18.2, U4.4 (INP); also elsewhere on the board
/Project Architecture/Power - PD Controller/TS: C18.1, JP3.1 (A), JP3.2 (C), Q3.1 (S), Q3.3 (S), TP23.1, U4.8 (TS)
/Project Architecture/Power - PD Controller/~FLT: U3.5 (GPIO0); also elsewhere on the board
GND: C9.2, C10.2, C11.2, C12.2, C13.2, C14.2, C16.2, C17.2, C19.2, C20.2, C21.2, C22.2, D7.2, J2.4, Q4.2 (S), Q5.2 (S), Q6.2 (S), R19.2, R21.2, U2.2 (GND), U2.4 (SD), U3.11 (GND), U3.12 (GND), U3.13 (GPIO11), U3.14 (GND), U3.19 (GND), U3.22 (GPIO4/USB_P/LD1), U3.23 (GPIO5/USB_N/LD2), U3.30 (GPIO7), U3.33 (GND), U4.2 (VCCUV), U4.3 (GND), U4.5 (OVLO), U4.11 (GND), U5.3 (GND), U6.1 (A0), U6.2 (A1), U6.3 (A2), U6.4 (VSS), U6.7 (WP); also elsewhere on the board
unnamed: C16.1, R7.1
unnamed: D6.1 (C), R20.1
unnamed: Q6.3 (D), R20.2
unnamed: R14.1, R17.1, U4.7 (TGUP)

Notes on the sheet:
I²C0
512 Kb I2C CMOS Serial EEPROM
USB Type-C® and USB PD Controller With Integrated Power Switches
Output Signals
Test Points
Input Signals
I²C1
DEBUG NOTE: ADCIN both conected to LDO1.5V result in ADCINx decoded value 5, which activate AlwaysEnableSink mode and I²C address 0x21 (7 bits). (see page 34)
DEBUG NOTE: EEPROM Address: Must be 0x50 (7-bit) on the I2Cc bus for the TPS26750 to find it automatically. (1010000)
DEBUG NOTE: If the gate driver is not working as expected, connect the bootstrap capacitor to +VBUS instead of TS.
LAYOUT NOTE: CC1/CC2 capacitors need to be placed as close as possible to their respective pins and on the same layer as the TPS26750 device.
DESIGN NOTE: 3V3 LDO total current needs to be lower than 5mA at startup: EEPROM read: 1mA POWER OK LED: 0.65mA TPD4S480: 0.16mA LM2765: 0.13mA LTC7004: 0.05mA I²C pull-ups: ~~0.5mA ADC resistors: 0.02mA AND gate: <0.01mA Total ~~2.5mA < 5mA
DESIGN NOTE: The default state for a USB-C port (before or during negotiation, or if negotiation fails) is effectively USB 2.0 specs: 5V @ 500mA. Therefore we want to limit the inrush current. Synapticon drives have an averager of 150uF of input capacitance. As explained in application informations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
DESIGN NOTE: LED current: (3.3 - 2.65)/330 = 2mA
DEBUG NOTE: When flashing the binary configuration to the EEPROM leave the jumper open, and power the EEPROM from an external supply, to avoid I²C bus conflict with TPS26750.
[${#}] ${TITLE}

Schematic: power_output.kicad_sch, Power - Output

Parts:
C28, C29: 10u X7R 63V; capc_3225_27_n; Manufacturer Part Number GRM32ER71J106KA12L; LCSC C437568
C30: 100n X7R 100V; capc_1608_09_l; Manufacturer Part Number CL10B104KC8NNNC; LCSC C15725
D8: SMAJ48A; do-214ac_440p_430x250x230_n_p; Manufacturer Part Number SMAJ48A; LCSC C41376401
F1, F2: FSMD020-1206-R; ptc_1206_08_n; Manufacturer Part Number FSMD020-1206-R; LCSC C220145
J3: 24.245.1; fcr7350r; Manufacturer Part Number 24.245.1; LCSC C7437326
J4: 24.245.2; fcr7350b; Manufacturer Part Number 24.245.2; LCSC C7437327
J5, J6: 1935776; phoenix_1935776; Manufacturer Part Number 1935776; LCSC C3817389
R33, R34: 33k 1%; resc_1005_04_n; Manufacturer Part Number RC0402FR-0733KL; LCSC C138003
TP31, TP32: 5001; Manufacturer Part Number 5001; LCSC C238122; not fitted

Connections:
+3V3: F1.1; also elsewhere on the board
+17V: F2.1; also elsewhere on the board
+VBUS_OUT: C28.1, C29.1, C30.1, D8.1 (A1), J3.1, R33.1, TP31.1; also elsewhere on the board
/Project Architecture/Power - Output/3V3_FUSED: F1.2, J5.1
/Project Architecture/Power - Output/17V_FUSED: F2.2, J6.1, J6.2
GND: C28.2, C29.2, C30.2, D8.2 (A2), J3.MP1 (MP), J3.MP2 (MP), J3.MP3 (MP), J3.MP4 (MP), J4.1, J4.MP1 (MP), J4.MP2 (MP), J4.MP3 (MP), J4.MP4 (MP), J5.2, R34.2, TP32.1; also elsewhere on the board
unnamed: R33.2, R34.1

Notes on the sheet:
Screw Terminals for 17V
4mm Banana SMT RED & BLACK Output Connectors
Input Signals
DESIGN NOTE: V_r : 48V V_brmin : 53.3V V_c = 77.4V This diode is our best option for 48V, but it won't be enough as TPD4S480 has a 63V maximum input voltage, and LMR16006 65V.
DESIGN NOTE: RC = 66k x 20uF = 1.3ms Safe to touch in 3 seconds max power losses: 0.73mA
[${#}] ${TITLE}
DESIGN NOTE: I_hold = 200mA I_trip = 400mA
FCR7350R - C7437326
LAYOUT NOTES: Space Banana connectors by a standard 19.05mm. Add mechanical stitching vias to +VBUS_OUT and GND to provide mechanical anchors against external torque applied to the connectors.
FCR7350B - C7437327

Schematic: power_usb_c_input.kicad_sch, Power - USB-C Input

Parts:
C1, C2, C5: 10n X7R 100V; capc_1005_06_n; Manufacturer Part Number CC0402KRX7R0BB103; LCSC C527014
C3: 4.7u; capc_3225_22_n; Manufacturer Part Number GCM32DC72A475KE02; LCSC C913445
C4, C6, C8: 100n X7R 100V; capc_1608_09_l; Manufacturer Part Number CL10B104KC8NNNC; LCSC C15725
C7: 1u X7R 100V; capc_2012_14_n; Manufacturer Part Number CC0805KKX7R0BB105; LCSC C5370002
D1: SMAJ48A; do-214ac_440p_430x250x230_n_p; Manufacturer Part Number SMAJ48A; LCSC C41376401
D2, D3: BZT52C18SQ; sod-323_230p_170x125x100_n; Manufacturer Part Number BZT52C18SQ; LCSC C2857090
D4: APTD1608LQBC/D; kingbright_0603_blue; Manufacturer Part Number APTD1608LQBC/D; LCSC C5344742
FB1: BLM18SN220TH1D; fer_1608_09_n; Manufacturer Part Number BLM18SN220TH1D; LCSC C710392
J1: DX07S024JJ2R1300; Manufacturer Part Number DX07S024JJ2R1300; LCSC C2977282
JP1: jumper_solder_2pad_nc_kicad; SolderJumper-2_P1.3mm_Bridged2Bar_RoundedPad1.0x1.5mm
JP2: jumper_solder_2pad_no; SolderJumper-2_P1.3mm_Open_RoundedPad1.0x1.5mm
Q1: AGM612AP; vsonp8_65p_330x330x80_mfg; Manufacturer Part Number AGM612AP; LCSC C5349119
Q2: AO3404A; sot-23-3L_103p_300x130x110_n; Manufacturer Part Number AO3404A; LCSC C30010
R1, R3: 100k 1%; resc_1005_04_m; Manufacturer Part Number 0402WGF1003TCE; LCSC C25741
R2, R4: 33k 1%; resc_1005_04_n; Manufacturer Part Number RC0402FR-0733KL; LCSC C138003
R5: 1k 1%; resc_1005_04_m; Manufacturer Part Number 0402WGF1001TCE; LCSC C11702
R6: 10k 1%; resc_1005_04_n; Manufacturer Part Number 0402WGF1002TCE; LCSC C25744
TP1, TP2: sp_oval_300x100
TP3, TP4, TP5, TP6, TP7, TP8, TP9, TP10, TP11, TP12, TP13: tp_round_70
U1: TPD4S480RUKR; wqfn20_40p_300x300x80_tp_170x170_n; Manufacturer Part Number TPD4S480RUKR; LCSC C43131250

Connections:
+3V3_LDO: C7.1, D4.2 (A), R6.1, U1.10 (VPWR); also elsewhere on the board
+VBUS: C4.1, FB1.2, Q1.3 (D), TP8.1, U1.20 (VBUS); also elsewhere on the board
+VBUS_LV: C6.1, D3.1 (K), Q1.1 (S), R1.1, TP9.1, U1.19 (VBUS_LV); also elsewhere on the board
/Project Architecture/MCU - Unit/USB_D_N: U1.14 (SBU2); also elsewhere on the board
/Project Architecture/MCU - Unit/USB_D_P: U1.15 (SBU1); also elsewhere on the board
/Project Architecture/Power - PD Controller/CC1: TP3.1, U1.12 (CC1); also elsewhere on the board
/Project Architecture/Power - PD Controller/CC2: TP5.1, U1.11 (CC2); also elsewhere on the board
/Project Architecture/Power - PD Controller/EPR_EN: TP11.1, U1.16 (EPR_EN); also elsewhere on the board
/Project Architecture/Power - PD Controller/~FLT: R6.2, TP12.1, U1.9 (~FLT); also elsewhere on the board
/Project Architecture/Power - USB-C Input/+VBUS_C: C1.1, C2.1, C3.1, D1.1 (A1), FB1.1, J1.A4, J1.A9, J1.B4, J1.B9, TP1.1, TP7.1
/Project Architecture/Power - USB-C Input/+VBUS_LV/2: Q2.1 (G), R1.2, R3.1, TP13.1
/Project Architecture/Power - USB-C Input/CC1_C: J1.A5, TP4.1, U1.4 (C_CC1), U1.7 (RPD_G1)
/Project Architecture/Power - USB-C Input/CC2_C: J1.B5, TP6.1, U1.5 (C_CC2), U1.6 (RPD_G2)
/Project Architecture/Power - USB-C Input/EPR_BLK_G: C5.2, JP2.1 (A), R2.2, TP10.1, U1.17 (EPR_BLK_G)
/Project Architecture/Power - USB-C Input/LED_IN_D: Q2.3 (D), R5.2
/Project Architecture/Power - USB-C Input/LED_IN_K: D4.1 (C), R5.1
/Project Architecture/Power - USB-C Input/USB_D_C_N: J1.A7, J1.B7, U1.2 (C_SBU2)
/Project Architecture/Power - USB-C Input/USB_D_C_P: J1.A6, J1.B6, U1.1 (C_SBU1)
/Project Architecture/Power - USB-C Input/VBIAS: C8.1, U1.3 (VBIAS)
/Project Architecture/Power - USB-C Input/VBUS_LV_GATE: C5.1, D2.1 (K), JP1.1 (A), JP1.2 (B), JP2.2 (B), Q1.2 (G), R2.1
GND: C1.2, C2.2, C3.2, C4.2, C6.2, C7.2, C8.2, D1.2 (A2), J1.A1, J1.A12, J1.B1, J1.B12, J1.MP1 (MP), J1.MP2 (MP), J1.MP3 (MP), J1.MP4 (MP), Q2.2 (S), R4.2, TP2.1, U1.8 (GND), U1.13 (GND), U1.18 (GND), U1.21 (EP); also elsewhere on the board
unnamed: D2.2 (A), D3.2 (A)
unnamed: R3.2, R4.1

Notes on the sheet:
USB Type-C™ 48V EPR port protector with short-to-VBUS overvoltage and IEC ESD protection
Test Points
Output Signals
Input Signals
USB-C 3.2 Gen2 48V 5A SMD receptacle
DEBUG NOTE: FLT is open-drain and requires a pull-up. To save board space, it could be removed, as TPS26750 has configurable internal pull-ups.
DESIGN NOTE: TPD4S480 have only 4uA of sourcing curent at EPR_BLK_G. BZT52C18SQ have a maximum leakage current of 0.1uA. Worst case sinking current: (21.17V - 17.1) / 33000 = 123 uA Turn-on time = 10nF x 12V / 4uA = 12ms
LAYOUT NOTE: Place the capacitors next to the VBUS pins.
DESIGN NOTE: 22ohm @ 100Mhz 4mohm @ DC 8A rated @ 85°C
[${#}] ${TITLE}
DESIGN NOTE: (3.3 - 2.65)/1000 = 0.65mA During dead-battery boot mode, TPS26750 internal LDO's can only source 5mA, this is why LED current as been reduced.
DESIGN NOTE: V_r : 48V V_brmin : 53.3V V_c = 77.4V This diode is our best option for 48V, but it won't be enough as TPD4S480 has a 63V maximum input voltage, and LMR16006 65V.
DEBUG NOTE: +VBUS_C and GND solder pads to test PCB with external supply at limited current.
DESIGN NOTE: +VBUS_LV/2 = 2.85V @ +VBUS_LV = 5V (min) 14.3V @ +VBUS_LV/2 = 25V (max) Vgs th < +VBUS_LV/2 < Vgs max 2.6V < +VBUS_LV/2 < 20V
DESIGN NOTE: VBUS blocking fet needs to have Vds ≥ 48V (in case TPD fails) and Vgs ≥ 0.42 x 50.4V = 21.16V. Since most FETs in this package have a +- 20V Vgs, zener diodes are used to clamp Vgs to 18V.
DESIGN NOTE: Pin A6 & B6 as well as A7 & B7 need to be connected together, to be able to use he USB-C connector in both directions.
DESIGN NOTE: RPD_G1/2 need to be tied to C_CC1/2 to enable dead battery support, to allow the device to be detected as a source by the USB-C source.

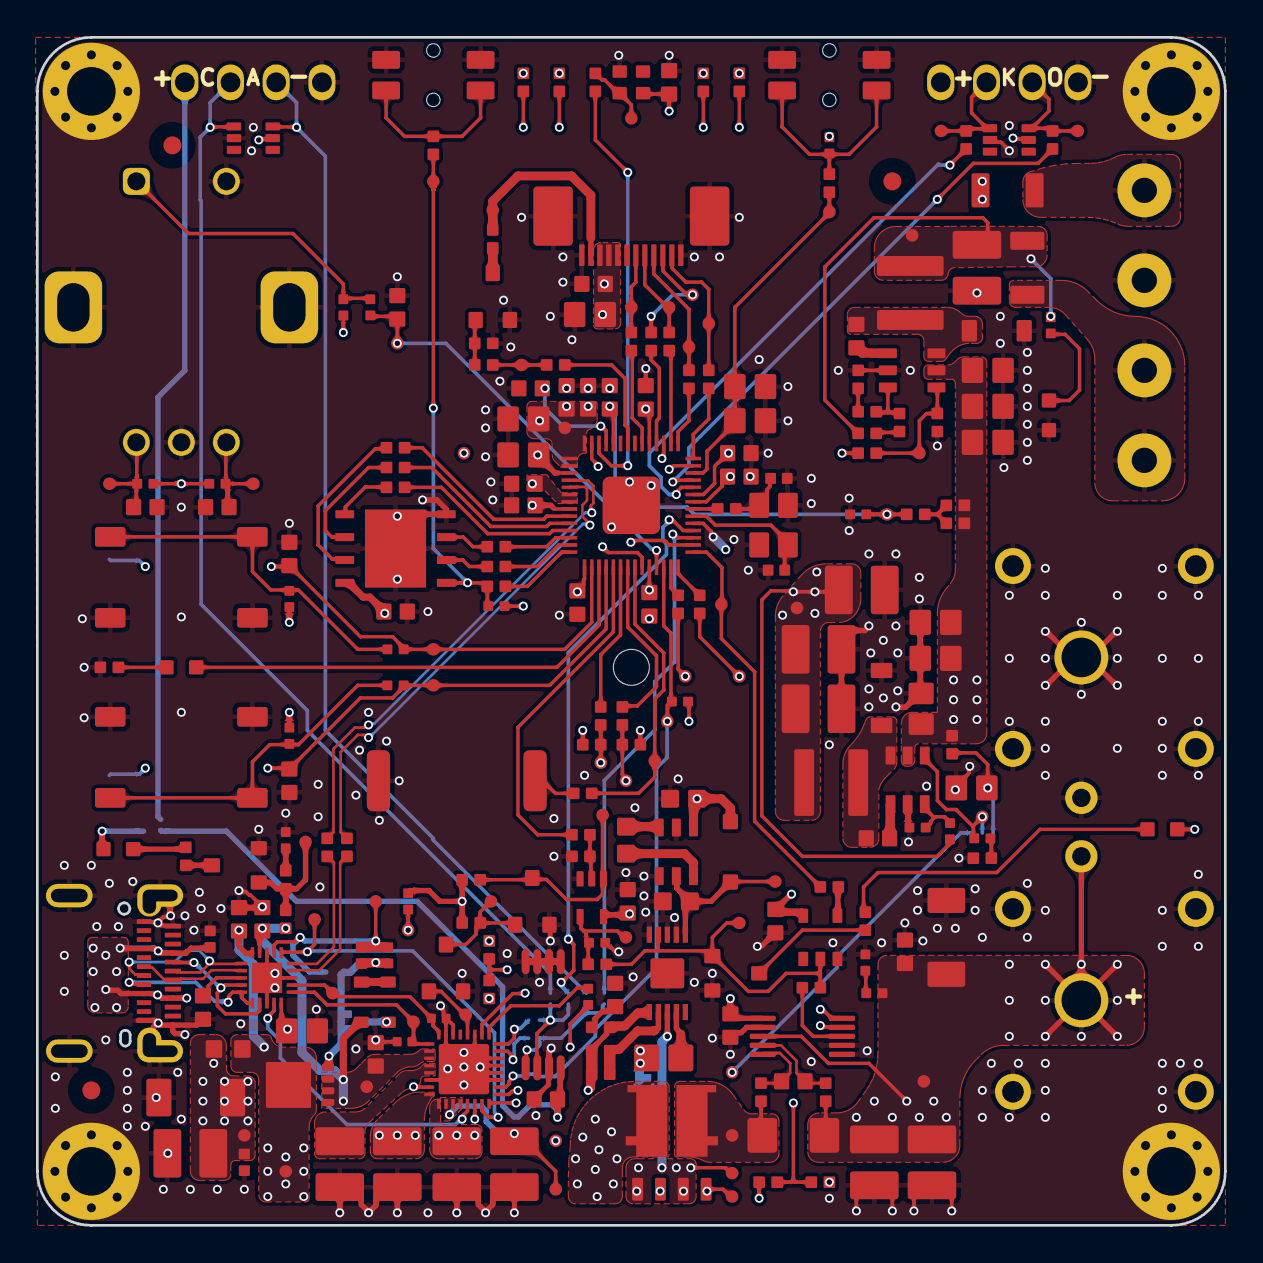
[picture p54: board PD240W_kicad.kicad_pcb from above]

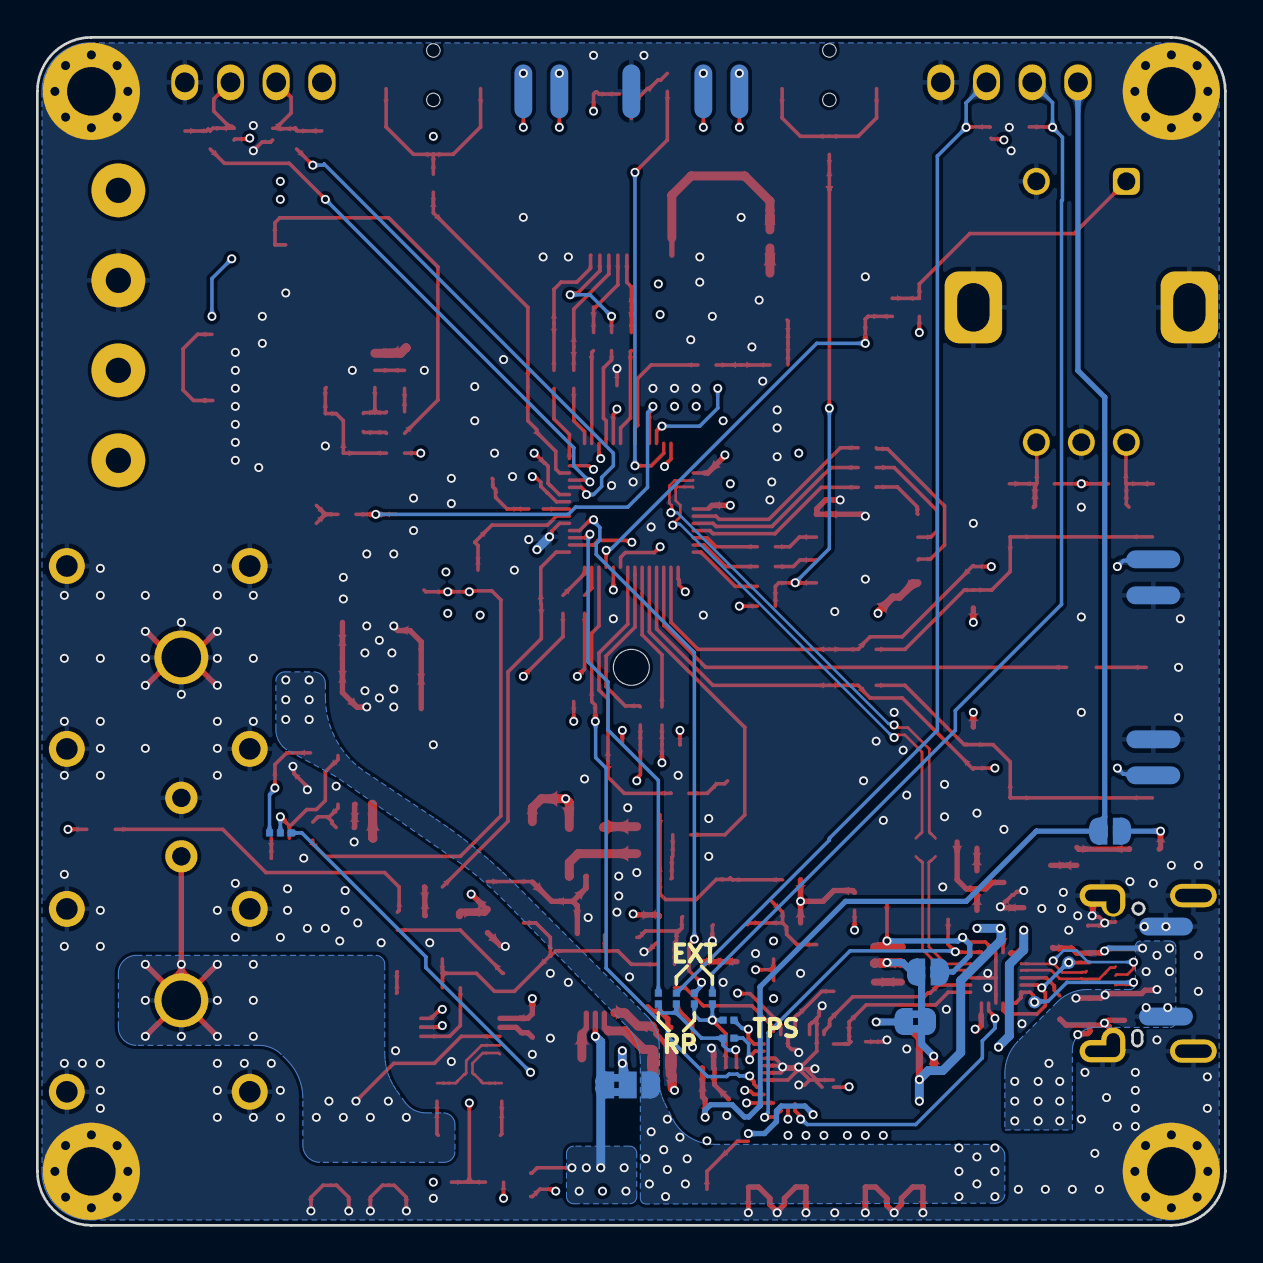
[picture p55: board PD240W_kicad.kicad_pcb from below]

Board: 6 copper layers, 66.0 x 66.0 mm, 299 parts (25 on the bottom side), 152 nets.

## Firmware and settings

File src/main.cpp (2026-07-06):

#include "pico/stdlib.h"
#include "hardware/watchdog.h"
#include <stdio.h>
#include "hardware.h"
#include "interrupts.h"
#include "utils/logging.h"
#include "config/app_config.h"
#include "logic/state_machine.h"
#include "logic/settings.h"
#include "logic/safety.h"
#include "logic/pd_manager.h"
#include "logic/cc_controller.h"
#include "cli/cli.h"
#include "ui/display_manager.h"

// ============================================================================
// PD240W Power Supply - Main Application
// ============================================================================
// Phase 3: Application Logic with State Machine
//
// Architecture:
// - State machine controls application flow (BOOT -> MAIN <-> MENU <-> ADJUST, FAULT)
// - Safety module monitors temperature, voltage, current
// - PD manager handles USB-PD contract negotiation
// - Display manager renders screens based on state
// - All modules use non-blocking patterns
// ============================================================================

// Display refresh timing
static absolute_time_t next_display_update;

int main() {
    // =========================================================================
    // Phase 1: Hardware Initialization
    // =========================================================================

    // Initialize hardware (I2C, SPI, all drivers, EEPROM flash)
    hw.init();

    // Setup all GPIO interrupts (encoder, overcurrent, USB-PD)
    Interrupts::init();

    // =========================================================================
    // Phase 2: Module Initialization
    // =========================================================================

    // Initialize settings
    settings.init();

    // Reset INA228 energy/charge accumulators for energy tracking since boot
    hw.powerMonitor.setAccumulation(1);  // Clear accumulators
    hw.powerMonitor.setAccumulation(0);  // Resume normal accumulation

    // Initialize safety monitoring
    safety.init();

    // Initialize PD manager
    pdManager.init();

    // Initialize display manager
    displayManager.init();

    // Initialize state machine (starts in BOOT state)
    stateMachine.init();

    // Initialize CC controller (restores CC mode from settings)
    CcController::init();

    // Initialize serial CLI (command interface over UART/USB)
    Cli::init();

    // Setup display refresh timer
    next_display_update = get_absolute_time();

    LOG_SEPARATOR();

    // Arm the hardware watchdog now that one-time init is done. If a stuck I2C bus
    // (or any other fault) ever freezes the main loop, this reboots the device
    // instead of leaving safety/PD monitoring dead with the load switch possibly on.
    // The loop feeds it every iteration; the boot patch push feeds it between steps.
    watchdog_enable(AppConfig::WATCHDOG_TIMEOUT_MS, true);

    // =========================================================================
    // Main Event Loop
    // =========================================================================

    while (true) {
        // ---------------------------------------------------------------------
        // 1. Update State Machine
        // ---------------------------------------------------------------------
        // Handles encoder input, button events, and state transitions
        bool needs_display_update = stateMachine.update();

        // ---------------------------------------------------------------------
        // 2. Update Safety Module
        // ---------------------------------------------------------------------
        // Monitors temperature, voltage, and current
        SafetyStatus safety_status = safety.update();

        // Transition to FAULT state if safety issue detected
        // IMPORTANT: Skip fault transitions during BOOT state to allow boot sequence to complete
        if (safety_status == SafetyStatus::FAULT && stateMachine.getState() != AppState::BOOT) {
            if (safety.isOvertemperature()) {
                stateMachine.setFault(FaultType::OVERTEMPERATURE);
            } else if (!safety.isPdConnected()) {
                stateMachine.setFault(FaultType::PD_DISCONNECT);
            }
            needs_display_update = true;
        }

        // ---------------------------------------------------------------------
        // 3. Update PD Manager
        // ---------------------------------------------------------------------
        // Handles USB-PD interrupt processing and negotiation state
        pdManager.update();

        // ---------------------------------------------------------------------
        // 3b. Update CC Controller
        // ---------------------------------------------------------------------
        // Constant current regulation via PD voltage adjustment
        CcController::update();

        // ---------------------------------------------------------------------
        // 4. Update Settings (Debounced Flash Save)
        // ---------------------------------------------------------------------
        // Handles deferred flash saves to reduce wear
        settings.update();

        // ---------------------------------------------------------------------
        // 5. Update Display
        // ---------------------------------------------------------------------
        // Render at fixed rate (100ms) or when state changes
        if (needs_display_update ||
            absolute_time_diff_us(next_display_update, get_absolute_time()) >= 0) {

            displayManager.render();
            next_display_update = make_timeout_time_ms(AppConfig::DISPLAY_UPDATE_MS);
        }

        // ---------------------------------------------------------------------
        // 6. Process Serial CLI
        // ---------------------------------------------------------------------
        // Non-blocking: reads available characters, dispatches complete commands
        Cli::update();

        // ---------------------------------------------------------------------
        // 7. Update Hardware
        // ---------------------------------------------------------------------
        // Required for RGB LED blinking and other timed operations
        hw.update();

        // ---------------------------------------------------------------------
        // 8. Feed the watchdog
        // ---------------------------------------------------------------------
        // Reaching here means a full loop iteration completed; keep the device
        // alive. A hung step (stuck bus) skips this and triggers a reboot.
        watchdog_update();
    }

    return 0;
}

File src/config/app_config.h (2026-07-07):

#pragma once

#include <cstdint>

// ============================================================================
// Application Configuration Constants
// ============================================================================

namespace AppConfig {
    // -------------------------------------------------------------------------
    // Timing Constants
    // -------------------------------------------------------------------------
    constexpr uint32_t BOOT_DURATION_MS = 2000;        // Boot screen max duration [ms]
    constexpr uint32_t BOOT_MIN_DISPLAY_MS = 500;      // Minimum boot screen time [ms]
    constexpr uint32_t BOOT_READY_DELAY_MS = 300;      // Time to show "Ready!" before transition [ms]
    constexpr uint32_t MENU_TIMEOUT_MS = 20000;        // Auto-return from menu [ms]
    constexpr uint32_t DISPLAY_UPDATE_MS = 100;        // Main screen refresh rate [ms]
    constexpr uint32_t ENCODER_LONG_PRESS_MS = 300;    // Long press threshold [ms]
    constexpr uint32_t ENCODER_MIN_PRESS_MS = 30;      // Minimum press time for debounce [ms]

    // Hardware watchdog: reboots the MCU if the main loop stops feeding it (e.g. a
    // stuck I2C bus hangs safety/PD monitoring with the load switch possibly on).
    // Sized above the longest legitimate blocking window: the boot PD-config push's
    // waitCommandClear (CMD_CLEAR_TIMEOUT_MS = 3000 ms). The push loop feeds the
    // watchdog between steps so only a single hung step needs to fit this budget.
    constexpr uint32_t WATCHDOG_TIMEOUT_MS = 4000;     // Main-loop watchdog timeout [ms]

    // -------------------------------------------------------------------------
    // Boot Timing
    // -------------------------------------------------------------------------
    constexpr uint32_t BOOT_PDO_TIMEOUT_MS = 800;               // PDO discovery timeout during boot [ms]
    constexpr uint32_t BOOT_NEGOTIATION_TIMEOUT_MS = 1000;      // Contract negotiation timeout during boot [ms]
    constexpr uint32_t BOOT_EPR_POLL_INTERVAL_MS = 150;         // EPR PDO poll interval during boot [ms]
    constexpr uint32_t BOOT_EPR_TIMEOUT_MS = 600;               // Non-EPR charger EPR probe timeout [ms]
    constexpr uint32_t BOOT_EPR_CONTRACT_TIMEOUT_MS = 1200;     // EPR contract settlement timeout [ms]
    constexpr uint32_t BOOT_PENDING_CONTRACT_TIMEOUT_MS = 5000; // Max total boot time while waiting for delayed startup contract [ms]

    // -------------------------------------------------------------------------
    // Safety Thresholds
    // -------------------------------------------------------------------------
    constexpr uint8_t TEMP_CAUTION_C = 50;             // Temperature hot threshold [C]
    constexpr uint8_t TEMP_WARNING_C = 65;             // Temperature warning threshold [C]
    constexpr uint8_t TEMP_CRITICAL_WARNING_C = 75;    // Temperature critical warning threshold [C]
    constexpr uint8_t TEMP_SHUTDOWN_C = 80;            // Temperature shutdown threshold [C]
    constexpr uint32_t MIN_VBUS_FOR_17V_MV = 18000;    // Minimum VBUS for 17V buck enable [mV]

    // -------------------------------------------------------------------------
    // Current Limit Settings
    // -------------------------------------------------------------------------
    constexpr uint32_t CURRENT_LIMIT_MIN_MA = 10;           // Minimum current limit [mA] (0.01A)
    constexpr uint32_t CURRENT_LIMIT_MAX_MA = 5000;         // Maximum current limit [mA]
    constexpr uint32_t CURRENT_LIMIT_NON_PD_MAX_MA = 3000;  // Max for non-PD chargers (USB BC1.2)
    constexpr uint32_t CURRENT_LIMIT_STEP_MA = 10;          // Base adjustment step [mA] (fine control)
    constexpr uint32_t CURRENT_LIMIT_DEFAULT_MA = 1000;     // Default current limit [mA]
    constexpr uint32_t STARTUP_REQUEST_MIN_MA = 500;        // Floor for pre-boot contract request current [mA]
    constexpr uint32_t CURRENT_LIMIT_VELOCITY_DIV = 1;      // Velocity divider (1 = use full velocity scaling)

    // -------------------------------------------------------------------------
    // PPS Voltage Settings
    // -------------------------------------------------------------------------
    constexpr uint32_t PPS_VOLTAGE_STEP_MV = 20;        // PPS voltage step size [mV] (PD spec minimum)
    constexpr uint32_t PPS_VELOCITY_MULT = 1;           // Keep single-detent PPS moves at the 20mV spec minimum
    constexpr uint32_t PPS_VOLTAGE_FLOOR_MV = 3300;     // CC fallback floor when the active APDO range min is unknown
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

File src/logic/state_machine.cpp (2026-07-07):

#include "state_machine.h"
#include "hardware/watchdog.h"
#include "hardware.h"
#include "interrupts.h"
#include "config/app_config.h"
#include "utils/logging.h"
#include "utils/pd_voltage.h"
#include "drivers/buzzer/buzzer.h"
#include "pd_manager.h"
#include "settings.h"
#include "tps_eeprom_workflow.h"
#include "cc_controller.h"
#include "ui/display_manager.h"
#include "cli/cli.h"

namespace {

const char* appStateName(AppState state) {
    switch (state) {
        case AppState::BOOT: return "BOOT";
        case AppState::MAIN: return "MAIN";
        case AppState::MENU: return "MENU";
        case AppState::ADJUST: return "ADJUST";
        case AppState::FAULT: return "FAULT";
    }

    return "UNKNOWN";
}

uint32_t getInitialProgrammableTargetMv(bool resume_current_target,
                                        uint32_t user_target_mv,
                                        uint32_t live_voltage_mv,
                                        uint32_t min_voltage_mv,
                                        uint32_t max_voltage_mv,
                                        uint32_t step_mv) {
    uint32_t target_mv = (min_voltage_mv + max_voltage_mv) / 2;

    if (resume_current_target) {
        target_mv = (user_target_mv > 0) ? user_target_mv : live_voltage_mv;
    }

    target_mv = PdVoltage::alignDown(target_mv, step_mv);
    if (target_mv < min_voltage_mv) {
        target_mv = min_voltage_mv;
    }
    if (target_mv > max_voltage_mv) {
        target_mv = max_voltage_mv;
    }

    return target_mv;
}

// currentLimitModeName / nextCurrentLimitMode now live in settings.h (shared).

// Snap a stored brightness percentage to the adjustment grid (STEP multiples
// anchored at MIN, clamped to [MIN, MAX]). Applied when loading the value into
// the adjuster so encoder steps stay on-grid — otherwise an off-grid stored
// value (e.g. from a CLI SETT:BRIGHT) makes the first CCW step underflow MIN and
// the first CW step land off-grid.
uint8_t alignBrightnessToGrid(uint8_t value) {
    if (value < AppConfig::LCD_BRIGHTNESS_MIN) return AppConfig::LCD_BRIGHTNESS_MIN;
    if (value > AppConfig::LCD_BRIGHTNESS_MAX) return AppConfig::LCD_BRIGHTNESS_MAX;
    uint8_t off = (value - AppConfig::LCD_BRIGHTNESS_MIN) % AppConfig::LCD_BRIGHTNESS_STEP;
    if (off == 0) return value;
    uint8_t aligned = (off * 2 >= AppConfig::LCD_BRIGHTNESS_STEP)
                          ? value + (AppConfig::LCD_BRIGHTNESS_STEP - off)
                          : value - off;
    if (aligned > AppConfig::LCD_BRIGHTNESS_MAX) aligned = AppConfig::LCD_BRIGHTNESS_MAX;
    return aligned;
}

}  // namespace

// Global instance
StateMachine stateMachine;

// ============================================================================
// Boot Stage Configuration
// ============================================================================

static const char* BOOT_MESSAGES[] = {
    "",                      // 0: Logo only (melody plays)
    "Reading USB-PD...",     // 1: Discovering PDOs with timeout
    "Negotiating...",        // 2: Requesting startup contract
    "Ready!"                 // 3: Complete
};
static constexpr uint8_t BOOT_STAGE_COUNT = 4;

// ============================================================================
// Constructor
// ============================================================================

StateMachine::StateMachine()
    // NOTE: keep this list in member-declaration order (see state_machine.h)
    // so -Wreorder stays clean.
    : _state(AppState::BOOT)
    , _previous_state(AppState::BOOT)
    , _state_enter_time(nil_time)
    , _last_activity_time(nil_time)
    , _encoder_press_start(nil_time)
    , _encoder_button_held(false)
    , _screen_dimmed(false)
    , _boot_stage(0)
    , _boot_pdos_found(false)
    , _boot_contract_requested(false)
    , _boot_contract_complete(false)
    , _boot_retry_after_epr(false)
    , _boot_epr_probed(false)
    , _boot_epr_probe_time(nil_time)
    , _boot_last_epr_poll_ms(0)
    , _boot_epr_pdos_found(false)
    , _boot_ready_time(nil_time)
    , _boot_neg_start(nil_time)
    , _boot_patch_session{}
    , _boot_patch_active(false)
    , _boot_patch_done(false)
    , _boot_patch_progress(0)
    , _selected_menu_item(MenuItem::SELECT_VOLTAGE)
    , _selected_settings_item(SettingsItem::FLASH_EEPROM)
    , _selected_pdo_index(0)
    , _num_pdos(0)
    , _adjust_mode(AdjustMode::NONE)
    , _current_limit_ma(AppConfig::CURRENT_LIMIT_DEFAULT_MA)
    , _epr_probe_pending(false)
    , _epr_probe_start(nil_time)
    , _epr_probe_target(AdjustMode::NONE)
    , _fault_type(FaultType::NONE)
    , _fault_measured_value(0.0f)
    , _fault_limit_value(0.0f)
    , _last_encoder_ticks(0)
    , _encoder_delta(0)
    , _pps_target_voltage_mv(0)
    , _pps_min_voltage_mv(0)
    , _pps_max_voltage_mv(0)
    , _pps_max_current_ma(0)
    , _pps_pdo_index(0)
    , _avs_target_voltage_mv(0)
    , _avs_min_voltage_mv(0)
    , _avs_max_voltage_mv(0)
    , _avs_max_current_ma(0)
    , _avs_pdo_index(0)
    , _brightness_value(100)
    , _brightness_adjusting(false)
    , _dim_timeout_value(1)
    , _dim_timeout_adjusting(false)
    , _melody_value(1)
    , _melody_adjusting(false)
    , _contract_mode_value(2)
    , _contract_mode_adjusting(false)
    , _energy_display_mwh(false)
{}

// ============================================================================
// Initialization
// ============================================================================

void StateMachine::init() {
    _state_enter_time = get_absolute_time();
    _last_activity_time = get_absolute_time();
    _last_encoder_ticks = hw.encoder.getTicks();

    // Restore saved current limit from settings
    uint32_t saved_limit = settings.getCurrentLimit();
    if (saved_limit >= AppConfig::CURRENT_LIMIT_MIN_MA && saved_limit <= AppConfig::CURRENT_LIMIT_MAX_MA) {
        setCurrentLimitMa(saved_limit);
    }

    // Restore energy display mode from settings
    _energy_display_mwh = (settings.getEnergyDisplayMode() != 0);

    // Play startup melody at boot (only if sounds enabled and melody != Silent)
    if (settings.isSoundsEnabled()) {
        uint8_t melody_idx = settings.getStartupMelody();
        const Note* melody = getStartupMelody(melody_idx);
        uint8_t length = getStartupMelodyLength(melody_idx);
        if (melody && length > 0) {
            hw.buzzer.playMelody(melody, length);
        }
    }

    LOG_INFO("State machine initialized, starting BOOT sequence");
}

// ============================================================================
// Main Update Loop
// ============================================================================
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

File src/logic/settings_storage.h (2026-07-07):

#pragma once

#include <cstddef>
#include <cstdint>
#include <cstring>

#include "config/app_config.h"
#include "logic/settings_types.h"

// ============================================================================
// Settings storage codec (pure, hardware-free)
// ============================================================================
// The persisted flash layout plus the pure logic that operates on it: CRC32
// integrity, magic/version validation, v4/v5 -> v6 migration, defaults, and the
// value clamps used by the setters. Split out of the Pico-SDK-coupled Settings
// class so this — the trickiest and most bug-prone part of settings — can be
// exercised by host unit tests (see test/test_settings_storage.cpp). This header
// includes only <cstdint>/<cstring>, app_config.h, and settings_types.h, so it
// is host-buildable.
//
// Settings (settings.cpp) owns the actual flash I/O, debounce timing, logging,
// and dirty-tracking; it delegates the byte-crunching here.
// ============================================================================

// Magic number to validate stored settings ("PD24").
constexpr uint32_t SETTINGS_MAGIC = 0x50443234;
// Current on-flash layout version. Bumping resets to defaults unless a migration
// path below understands the older layout.
constexpr uint8_t SETTINGS_VERSION = 6;

// Current persisted layout (v6). Kept a plain POD so it can be memcpy'd to/from
// flash and CRC'd byte-for-byte. Fields are never reordered without a version
// bump; new fields append before crc32.
struct UserSettings {
    // Magic number for validation
    uint32_t magic;

    // Settings version for future compatibility
    uint8_t version;

    // Current limit (mA)
    uint32_t current_limit_ma;

    // Saved startup-contract hint (PDO indices are charger-specific, so this is only a hint)
    int8_t last_pdo_index;

    // Output states (unused: accessors were removed as dead code). Retained only
    // to keep the flash layout stable; delete on the next SETTINGS_VERSION bump.
    bool load_switch_enabled;
    bool buck_17v_enabled;

    // Display settings
    uint8_t lcd_brightness;  // 0-100%

    // Sound settings
    bool sounds_enabled;     // ON/OFF for navigation buzzer sounds

    // Auto PPS tuning
    bool auto_pps_enabled;   // ON/OFF for automatic PPS voltage calibration

    // Auto-dim timeout (minutes)
    uint8_t auto_dim_minutes;  // 0-10, 0 = OFF, default 1

    // Startup melody selection
    uint8_t startup_melody;    // 0=Silent, 1=Mario, 2=Chime, 3=TwoTone

    // Auto output on boot
    bool auto_output;          // If true, enable output after boot completes

    // Saved startup contract snapshot for LAST_USED restore
    uint8_t last_contract_type;             // SavedStartupContractType
    uint32_t last_requested_voltage_mv;     // Requested fixed/PPS/AVS target [mV]
    uint32_t last_contract_min_voltage_mv;  // Advertised range min, or fixed voltage [mV]
    uint32_t last_contract_max_voltage_mv;  // Advertised range max, or fixed voltage [mV]

    // Startup contract negotiation mode
    uint8_t startup_negotiation;  // 0=Lowest voltage, 1=Highest voltage, 2=Last used

    // Auto AVS tuning
    bool auto_avs_enabled;   // ON/OFF for automatic AVS voltage calibration

    // Energy display mode: 0 = mAh, 1 = mWh
    uint8_t energy_display_mode;

    // Current limit operating mode (OFF / OCP / CC)
    uint8_t current_limit_mode;

    // CRC32 for data integrity
    uint32_t crc32;
};

// Pin the persisted layout. The CRC and loadFromBytes depend on the exact byte
// layout (including compiler padding), and the host test suite must exercise
// the same layout the ARM target writes to flash. These fire on any field
// insertion/reorder done without a SETTINGS_VERSION bump, and on any
// host/target ABI divergence. Verified identical on arm-none-eabi (Cortex-M0+)
// and x86-64/arm64 hosts.
static_assert(sizeof(UserSettings) == 44, "UserSettings layout changed - bump SETTINGS_VERSION and update this assert");
static_assert(offsetof(UserSettings, crc32) == 40, "crc32 must stay the trailing field");

namespace SettingsStorage {

// Legacy on-flash layouts still understood for migration. Never edited — they
// are the exact byte layouts written by firmware v5 / v4.
struct UserSettingsV5 {
    uint32_t magic;
    uint8_t version;
    uint32_t current_limit_ma;
    int8_t last_pdo_index;
    bool load_switch_enabled;
    bool buck_17v_enabled;
    uint8_t lcd_brightness;
    bool sounds_enabled;
    bool auto_pps_enabled;
    uint8_t auto_dim_minutes;
    uint8_t startup_melody;
    bool auto_output;
    uint8_t last_contract_type;
    uint32_t last_requested_voltage_mv;
    uint32_t last_contract_min_voltage_mv;
    uint32_t last_contract_max_voltage_mv;
    uint8_t startup_negotiation;
    bool auto_avs_enabled;
    uint8_t energy_display_mode;
    bool cc_mode_enabled;
    uint32_t crc32;
};
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

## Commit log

2026-01-26 Added Overcurrent protection methode, cleaned hardware init, added info log for succesful init, spearated interrupts from main, added blink method for GPIO
2026-01-26 Working with 5V but not 15V. Flashing full flash binary with C++ code.
2026-01-26 Finally found a robust way of making PCB work without debugger atatched.
2026-01-27 Working UI, no flickering, fixed conctracts dispaly, and more
    [button.cpp, hardware.cpp, interrupts.cpp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]
2026-01-27 Working UI, no flickering, fixed conctracts dispaly, and more, updated documentation
    [app_config.h, state_machine.cpp]
2026-01-28 Fixed RGB LED behavior during fault, and implmented EEPROM flashing feature
    [eeprom_loader.cpp, eeprom_loader.h, safety.cpp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]
2026-01-29 Improved encoder rotation click logic, added scaling for current and voltage measurements
2026-01-29 Cleaned UI, fixed flickering, cleaned bootup, added melody, cleaned about
    [buzzer.cpp, safety.cpp, st7789.cpp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]
2026-01-29 Cleaned logo, cleaned UI, added beeps, added precise current settings, updated doc
2026-02-02 Cleaned repo, cleaned code, added PCB files, stl and 3d models, prepared next steps
    [PD240W_PCB.stp, button.stl, casing_bottom.stl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]
2026-02-02 Added USB-PD norm badge, added energy monitoring, added melody selection, added auto dim config, added auto output on config, fixed screen flicker in settings, fixed temeparture display clearing, add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
    [app_config.h, buzzer.cpp, hardware.cpp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]
2026-02-03 Fixed long encoder button press causing double clicks, added color helpers for rgb led, cleaned auto-dim variables, fixed PD badge not showing on boot, fixed setting change full redraw
    [app_config.h, hardware.cpp, safety.cpp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]
2026-02-06 Fixed buzzer beep for overtemp, fixed menu flickering, removed noise in current and wattage measurements, cleaned overctemp screen, and few more minor fixes
    [pd_manager.cpp, pd_manager.h, safety.cpp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]
2026-02-07 Cleaned UI, cleaned about menu, early readme, added CI, added release workflow, added current contract highlight
2026-02-07 Added images & gif to readme, fixed as best as possible overcurrent screen and overtemp screens
    [state_machine.cpp]
2026-02-09 Updated README, added gerbers and liscence [skip ci]
    [BOM.csv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]
2026-03-16 Added KiCad PCB files, updated licence, updated README [skip ci]
    [BOM.csv, Block Diagram.kicad_sch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]
2026-03-22 Fixed looping issue when scrolling with many contracts available, can go from 48V to 36V to 28V but cannot go back to SPR
    [pd_manager.cpp, pd_manager.h, state_machine.cpp]
2026-03-22 LG still broken, no more 48V detected, but can navigate between 5-20V on the framework
    [hardware.cpp, pd_manager.cpp, pd_manager.h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]
2026-03-22 Fixed 48V neg on refresh bug on main menu, LG still not working
    [pd_manager.cpp, pd_manager.h, state_machine.cpp]
2026-03-22 Fixed AVS and duplicated contracts, added EPR and AVS badges
    [app_config.h, state_machine.cpp]
2026-03-24 Implemented a sketchy CC mode, improved INA228 library with true power math core, and ppm compensation, tried switching mode CC (fail) and reduced amount of EEPROM save
    [app_config.h, board_config.h, hardware.cpp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]
2026-03-29 Cleaned code (magic numbers, dead code, duplicates, missing inits)
    [app_config.h, pd_manager.cpp, pd_manager.h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]
2026-04-27 Added possibility to disable Auto-Dim, fix AVS current bug at PDO voltages, fixed display issue for current and voltage selection
    [app_config.h, pd_manager.cpp, pd_manager.h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]
2026-04-27 Fix voltage spike at reboot when in last V used mode
    [main.cpp, pd_manager.cpp, pd_manager.h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]
2026-04-30 Rebranded the UI to blue/magenta and PD240W logo. Fix persistent bip in mute mode when exiting the voltage selection menu. Fixed AVS/EPR/PPS badges fake persistence after reboot with a different char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
    [hardware.cpp, pd_manager.cpp, pd_manager.h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]
2026-05-18 Rounded loading bars with gradient, rounded highlight bar, improved EEPROM flashing screens showing the progress, detect SPR AVS contracts and identifies charger as PD3.2, centered highlight bar on t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
    [hardware.cpp, pd_manager.cpp, st7789.cpp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]
2026-05-19 Fixed SPR and PPS negotiation, and fixed AVS negotiation. However did not fix SPR AVS, and there are bugs in the transitions from EPR to SPR
    [pd_manager.cpp, pd_manager.h, state_machine.cpp]
2026-05-19 Log PD revision only when it changes, to avoid noise in serial terminal
    [pd_manager.cpp]
2026-05-20 fixed exit from EPR fixed PDO to lower voltage that always go to 5V and not the correct fixed PDO (no 9, 15 or 20), fixed exit EPR AVS to SPR AVS that cause reboot
    [pd_manager.cpp, pd_manager.h]
2026-05-20 Fixed bug were EPR badge was appearing on main screen for SPR AVS
    [pd_manager.cpp, pd_manager.h]
2026-05-26 Integrate INA228 multiplatform library as submodule and remove local driver
    - add external/ina228_multiplatform as git submodule
    - switch CMake to build INA228 sources from submodule
    - update hardware include and constructor usage for bus-first INA228 API
    - remove duplicated in-tree INA228 implementation
    - update README and notes for submodule-based build flow
    - update CI/release workflows to checkout submodules recursively
2026-05-30 Add charger diagnostics and smarter cable inference
    Add an About This Charger diagnostics view with live PD revision, CC orientation, charger identity, QC inference, and source power reporting.
    Extend the TPS26750 driver with GPPI and MBRd helpers so the firmware can request Manufacturer Info and expose controller status to higher layers.
    Refine cable rating detection to distinguish confirmed 5A cables from likely 3A and charger-limited unknown cases, avoiding false positives from PPS-only >3A advertisements.
    [pd_manager.cpp, pd_manager.h, state_machine.cpp]
2026-05-30 Fix programmable adjust cursor restore
    Reuse the active PPS or AVS target when reopening the selected APDO from the voltage selection menu, instead of resetting the cursor to the middle of the range.
    Keep the quick-adjust and menu entry paths aligned through a shared programmable target initializer that clamps to the current APDO bounds.
    Reduce the encoder long-press threshold from 700ms to 300ms so PPS and AVS quick adjust feels more responsive.
    [app_config.h, state_machine.cpp]
2026-05-30 Refine startup contract restore and boot logging
    Make LAST_USED restore charger-agnostic by saving explicit contract metadata and matching by intent instead of blindly trusting PDO indices.
    Defer >20V restore targets until EPR PDOs appear, retry after EPR discovery, and fall back cleanly on non-EPR chargers.
    Clean up boot and polling logs, keep about screens alive on encoder activity, and include the menu auto-return timeout adjustment.
2026-05-30 Stabilize PPS and AVS tuning feedback
    Keep programmable contract state alive while PPS/AVS requests are still settling so Vset and badge state do not disappear on first entry.
    Retain PPS/AVS tracking through normal regulation error, speed up unconverged tuning retries, and restore 20mV PPS single-detent steps.
    [app_config.h, pd_manager.cpp, pd_manager.h]
2026-06-01 Add OFF current limit mode
2026-06-01 Increased max current reading from INA from 5.0A to 5.12A
2026-06-17 Fit more contracts in voltage select menu
    Pull the PDO list up to the header and raise the visible row cap
    from 8 to 10, reducing scrolling on chargers with many contracts.
2026-06-25 Migrate TPS26750 driver to shared multiplatform submodule
    Replace the in-tree tps26750 driver with the external
    tps26750_multiplatform submodule and adopt its TPS26750_* types
    across pd_manager, state_machine, hardware, and the display.
    Add a TPS FW version line to the About screen and tidy its
    spacing/column layout.
    [hardware.cpp, pd_manager.cpp, pd_manager.h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]
2026-06-29 Lower PD disconnect VBUS threshold to 3.3V
2026-06-30 Push TPS26750 PD config over I2C (burst mode), drop EEPROM dependency
    Stream the patch bundle + app config directly from the RP2040 over I2C at
    boot using the TI burst-mode tasks (PBMs -> burst -> PBMc), so an EEPROM-less
    board can transition the TPS26750 from PTCH to APP mode.
    - Derive the low region (patch + config) from the validated full-flash image. Sourcing both EEPROM and burst paths from one image keeps them identical.
    - Issue the startup pre-boot contract request after the patch reaches APP mode
    (boot stage 0), not in main() where the TPS is still in PTCH.
    [main.cpp, state_machine.cpp, tps_eeprom_loader.cpp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]
2026-06-30 Make flash size configurable instead of hardcoded 2MB
    Settings storage offset and About-screen flash usage now derive from
    PICO_FLASH_SIZE_BYTES (set to the real 16MB/128Mbit chip) instead of
    an assumed 2MB, so both reflect the actual hardware. The value is wired
    into both the linker flash region and the C compile definitions so
    they stay in sync.
2026-06-30 Fix Max Power showing 0W for non-PD chargers, bump TPS26750 driver to v1.0.1
    [pd_manager.cpp, pd_manager.h]
2026-07-03 Fix brightness CLI overload, buzzer melody latch, and other small bugs
    - SETT:BRIGHT CLI command called the bool setBacklight() overload
    instead of setBacklightBrightness(), forcing full brightness
    - playTone() left _playing_melody latched after cancelling a melody's
    alarm chain, which could permanently silence the critical-temperature
    alarm
    - tpsPatchStep(nullptr) dereferenced session in its error path
    - Moved function-local static state to member variables in safety.cpp
    and state_machine.cpp boot EPR-poll tracking, fixing a case where the
    poll state wasn't reset across repeated BOOT entries
    - Bumped stale pico_set_program_version from 0.1 to 2.0.2
    [buzzer.cpp, safety.cpp, state_machine.cpp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]
2026-07-03 Fix all P0/P1 code-review findings
    P0: reject query form of action CLI commands (NOT_QUERYABLE), make the
    overcurrent ISR the sole fault owner (no more permanent FAULT), enter
    remote mode only on a recognized command, reject over-length CLI lines.
    P1: non-blocking EPR probe in the menu (drop sleep_ms), disable outputs
    before the blocking TPS:GARBAGE erase, clamp negative measurements before
    unsigned cast, fix PPS/AVS tuning badge stuck yellow, widen EPR badge
    clear rect, refresh settings brightness row on external change, guard
    buzzer alarm state against the IRQ callback, stop type-punning
    absolute_time_t in Button.
    [button.cpp, buzzer.cpp, safety.cpp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]
2026-07-04 Implement P2 code-review items: warnings, cleanup, hygiene
    - Enable -Wall -Wextra scoped to our sources; fix ~130 format
    specifiers (%lu/%ld), ctor init-order, and other warnings
    - Wire DEBUG_BUILD to CMake build type (Debug=1, Release=0),
    defaulting to Debug when unspecified
    - Document accepted overcurrent-ISR latency during flash writes
    - Remove verified zero-caller dead code across drivers/logic/ui
    - Promote pd_manager timer statics to members (re-entrant waitForPdos)
    - CLI: uppercase only the command token, keep argument case;
    make ON/OFF parsing case-insensitive
    [adc_inputs.cpp, button.cpp, buzzer.cpp]
2026-07-04 CI/release: build explicit Release config
    With the new default-to-Debug guard in CMakeLists, a bare `cmake ..`
    now configures Debug. Pin both workflows to -DCMAKE_BUILD_TYPE=Release
    so releases ship an optimized image with DEBUG_BUILD=0 (no debug
    logging) and CI validates that shipping config.
2026-07-04 - Shared StateMachine::setLoadSwitch/set17vBuck for CLI + buttons (one owner of fault gating, INA latch clear, tuning recheck, 17V VBUS interlock); buck interlock now uses pre-switch ADC VBUS - Curre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
2026-07-04 Fix AVS keep-alive re-arming during in-flight contract exit
    Warm-reset AVS/PPS re-detection could fire on a stale voltage reading
    while a Fixed request was already in flight, re-arming keep-alive at
    the old AVS voltage and preventing the contract from ever exiting.
    [pd_manager.cpp]
2026-07-05 Unify PPS/AVS keep-alive, tuning, and request logic
    PdManager tracked PPS and AVS contracts with near-identical duplicated
    code for keep-alive refresh, auto-tune correction, request handling,
    and state clearing.
    Introduce a ProgrammableContract struct holding per-type config and
    runtime state, instantiated once each as _pps/_avs, and collapse the
    duplicated blocks into serviceKeepAlive()/requestProgrammable()/
    clearTracking(). Public API unchanged, so callers in state_machine,
    display_manager, cc_controller, and cli_commands needed no edits.
    Verified on hardware.
    [pd_manager.cpp, pd_manager.h]
2026-07-05 Extract pure PD diagnostics logic to a testable header
    Move findBestStartupMatch, inferDetectedCableRating,
    decodeManufacturerInfoResponse, and their pure dependencies out of
    pd_manager.cpp into pd_diagnostics.h, which depends only on data-type
    headers (no hardware.h/interrupts.h/cc_controller.h).
    Also document the DisplayManager backlight ownership split
    (DisplayManager owns the one-shot first-frame reveal; StateMachine
    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
2026-07-05 Add host-based unit test harness for logic layer
    Decouple pd_diagnostics.h from the Pico SDK (settings_types.h for the
    flash enums, TPS26750_PLATFORM_NATIVE for the submodule's data types)
    and add a Snitch-based test suite that builds and runs on the host
    with ASan/UBSan, covering startup-contract matching, charger-identity
    decode, and cable-rating inference. Also adds .clang-format/.clang-tidy
    config.
2026-07-06 Extract settings storage and thermal FSM to testable headers
    Settings: flash-image CRC32, magic/version validation, v4/v5->v6
    migration, defaults, and setter clamps moved to settings_storage.h
    (depends only on <cstdint>/settings_types.h). Settings now delegates
    the byte-crunching and keeps flash I/O, debounce, and logging.
    Safety: the 3-band overtemperature FSM (hysteresis, latching, edge
    signalling) moved to thermal_monitor.h. Safety::updateTemperature
    delegates to ThermalMonitor::evaluate() and keeps the load cut, buzzer
    path, and logs.
    Both are semantics-preserving lifts, wired into the host suite via
    test_settings_storage.cpp and test_thermal_monitor.cpp.
    [safety.cpp, settings_storage.h]
2026-07-06 Extract PD-revision and PPS/AVS tuning math; add host test CI
    PdManager::detectPdRevision's PDO-shape -> revision-string
    classification moves to inferPdRevision() in pd_diagnostics.h; the
    wrapper keeps only caching and the change log.
    The PPS/AVS auto-tune corrector (convergence check, accumulating
    P-correction with +/-500mV clamp, request-voltage clamp/step-align)
    moves to programmable_tuning.h and is shared by serviceKeepAlive and
    checkTuningConvergenceImmediate, closing the "fixed it for PPS, forgot
    AVS" gap at its most bug-prone spot.
    Adds .github/workflows/test.yml to run the host suite (native g++,
    ASan/UBSan) on push/PR to main, alongside the existing ARM firmware
    build in ci.yml.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
    [pd_diagnostics.h, pd_manager.cpp]
2026-07-06 Fix safety and correctness bugs from code review
    - I2C timeouts on both submodules + watchdog to prevent bus-hang lockups
    - Menu timeout no longer abandons EEPROM flash mid-write
    - INA228 DIETEMP sign-extension fix (spurious OVERTEMP fault when cold)
    - PPS/AVS keep-alive backoff on failed request (was hammering I2C every loop)
    - Clamp ST7789 gradient column buffer (latent stack overflow)
    - Guard SK6812 write against failed PIO init
    - Zero TPS26750 short-read tail / assign getActiveContract out-params
    - Guard buzzer alarm arm failures so tone can't latch on forever
    - Restore state color on safety OK instead of leaving LED stuck yellow
    - MEAS:ENERGY? now reports mWh, new MEAS:CHARGE? for mAh
    -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
    [app_config.h, buzzer.cpp, main.cpp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]
2026-07-06 Fix P2 review findings: CC range floor, brightness floor, buzzer pitch, thermal status, log gate
    - CcController: use active APDO range min instead of hard-coded PPS/AVS
    voltage floors, falling back to new AppConfig constants when unknown
    - settings_storage: clampBrightness enforces the 5% floor, not just the cap
    - Buzzer::setFrequency: raise clkdiv instead of clamping wrap for low
    frequencies, fixing pitch below ~120Hz without affecting any used note
    - ThermalMonitor::evaluate: derive status from the final latched band so
    it no longer sticks at FAULT after clearing into an already-latched
    warning
    - LOG_SEPARATOR now honors the LOG:OFF gate like the other log macros
    [app_config.h, buzzer.cpp, settings_storage.h]
2026-07-06 Fix remaining P3 review findings: INA228 gate, driver hygiene, EEPROM I2C
    - Gate load switch on INA228 init success (hw.powerMonitorReady()); refuse
    with new OutputResult::NO_POWER_MONITOR (CLI error + front-panel beep)
    instead of silently enabling an unmonitored output with no OCP.
    - st7789: fix writeData16 CS/DC ordering to match writeCommand/writeData;
    support negative-origin clipping in drawBitmap/drawBitmapScaled.
    - adc_inputs: drop logging include per driver architecture rule (drivers
    stay logging-free; callers interpret sentinel return values).
    - tps_eeprom_loader: make I2C1 init/deinit idempotent, factor shared
    page-chunk write helper, delete dead blocking eepromFlash().
    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
    [adc_inputs.cpp, hardware.cpp, st7789.cpp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]
2026-07-06 Fixed PDO dedup, display staleness, EPR-exit extraction
    - ST7789 gradient-column fill now screen-bounds clips (dithered path)
    - PdManager::pdoAt() replaces triplicated PDO copies (s_pdo_list global,
    stack caps[] copies in state_machine/cli_commands/display_manager)
    - EPR badge re-anchors on PD-rev width change; dropped redundant
    full-screen clears on FAULT entry and EEPROM flash stage 2;
    About-Charger screen redraws on charger connect/disconnect
    - Extracted EPR safe-exit decision helpers (needsEprExit,
    isSafeEprExitPossible, findAvsSafeVoltage) to host-testable
    pd_diagnostics.h with test coverage
    [pd_diagnostics.h, pd_manager.cpp, pd_manager.h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]
2026-07-07 Extract CC regulation and EPR-exit FSM to testable headers; fuzz settings codec
    - CC controller: pull the regulation arithmetic (R-estimate filter,
    feedforward + P blend, deadband, overcurrent-never-raises, clamp) into
    pure, host-tested CcRegulation::computeCcStep; CcController::update() now
    only handles hardware I/O and request timing. 18 Snitch cases including
    the overcurrent-never-raises invariant and a resistive-load convergence sim.
    - PD manager: extract the EPR safe-exit sequencing into
    PdDiagnostics::eprExitStep, a pure transition table pinning timeout >
    failure > advance precedence; PdManager dispatches the hardware side effect
    per action. STARTUP_REQUEST_MIN_MA replace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
    [app_config.h, cc_regulation.h, pd_diagnostics.h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]
2026-07-07 Fix dim-wake, PDO_SELECT staleness, and in-FAULT redraw bugs
    - Wake-from-dim (both encoder and button paths) restored the Settings-submenu
    editing snapshot (_brightness_value, 100 until the submenu is first opened)
    instead of the saved brightness; read settings.getLcdBrightness() instead.
    - The waking input itself no longer actuates: swallow the encoder event after
    an encoder wake, and return before the load-switch/17V toggle after a
    button wake, matching bench-instrument behaviour.
    - PDO_SELECT re-syncs _num_pdos and clamps the cursor at the top of the
    branch, so a mid-selection cache refresh (late EPR caps, re-advertisement)
    can't leave rows unreachable or mis-treat the "Back"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
    [state_machine.cpp]
2026-07-07 Gate -Werror on our sources behind a CI-only CMake option
    -Wall -Wextra were already scoped to our sources (not the Pico SDK) but
    never promoted to errors. Add PD240W_WERROR (default OFF, so a stray warning
    from a newer local toolchain doesn't block day-to-day builds) and have
    ci.yml configure with -DPD240W_WERROR=ON, so a format-string or
    dead-variable regression fails the PR instead of merging silently.
2026-07-07 Fix release-build unused-variable errors in LOG_DEBUG-only locals
    LOG_DEBUG compiles to a no-op in production builds, so these locals
    were unused under -Werror=unused-variable in the CI release config.
    [pd_manager.cpp]

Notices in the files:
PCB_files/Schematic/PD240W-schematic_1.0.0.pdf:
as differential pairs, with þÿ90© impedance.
